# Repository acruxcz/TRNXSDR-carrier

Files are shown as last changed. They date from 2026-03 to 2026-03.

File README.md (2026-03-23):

# #TRNXSDR - Open RF Research Platform

**A modular baseboard designed for advanced Software Defined Radio (SDR) ecosystems.**

---

## 📝 Project Overview
The **TRNXSDR** is a hardware platform engineered to host and interconnect specialized SDR modules. It acts as the central processing hub, providing high-speed logic, memory bandwidth, and versatile connectivity for complex radio applications.

> [!IMPORTANT]
> The **TRNXSDR** is a **Baseboard Platform**. While it provides the processing power and RF routing, it requires external SDR modules connected via the expansion slots for full radio functionality.

## #TRNXSDR Baseboard

<p align="center">
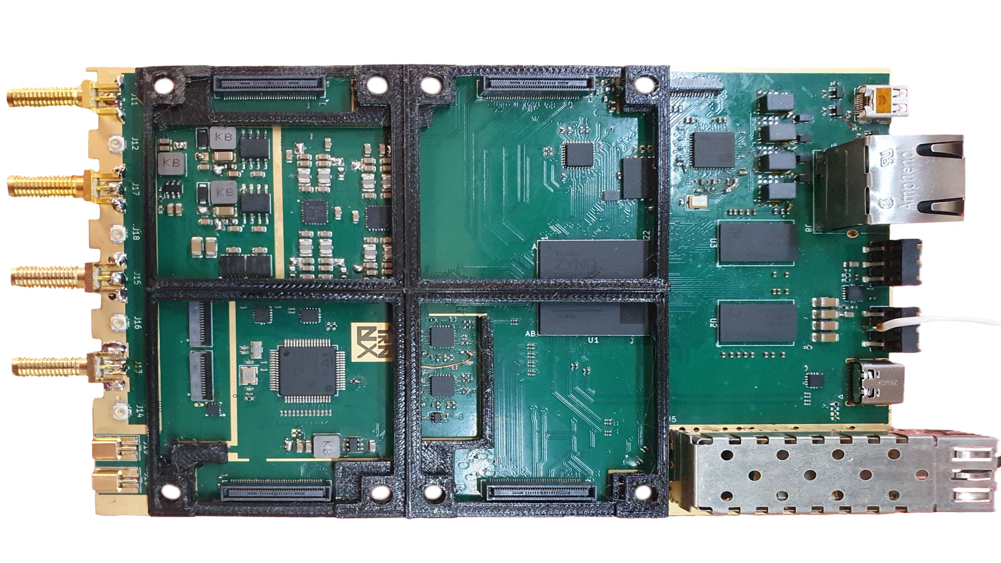
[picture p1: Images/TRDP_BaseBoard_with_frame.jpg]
TRNXSDR BaseBoard
  
</p>

---

## Key Technical Specifications

### ⚙️ Processing & Memory
*   **FPGA XC7Z015 Core**: High-speed logic for real-time Digital Signal Processing (DSP).
*   **1 GB DDR3 RAM @ 1066 MHz**: High-capacity memory for data buffering and complex waveform processing.
*   **80-pin Module Connectors**: High-density connectors ensuring reliable signal integrity between the baseboard and modules.

### 🌐 Connectivity & I/O
*   **1 Gbit Ethernet (Copper)**: Standard high-speed network integration.
*   **Optical Ethernet (SFP)**: Hardware ready for fiber-optic connection. Planned support for **1 Gbit / 2.5 Gbit+** throughput via GTX connection (up to **5 Gbit** for custom digital IF).
*   **USB-C**: Hardware support for **Power Delivery (PD)** to power the entire board via a single cable (9–20 V input). Firmware currently under development.
*   **4 SMA RF Connectors**: On-board SMA connectors for direct and stable antenna connections.

---

## 🛠 Modular Ecosystem & Scalability
The platform is designed to grow. The baseboard features a flexible slot system to accommodate various SDR modules.

| Slot Type | Quantity | Technical Capabilities |
| :--- | :---: | :--- |
| **Primary HS Slots** | **2** | **High-Speed Support**: 1x with 2L GTX (JESD204B support), both slots support LVDS. |
| **Primary LS Slots** | **2** | **Standard I/O**: Optimized for general-purpose SDR control and low-speed buses. |
| **Expansion Board** | **+6** | **Low-Speed Expansion**: Optimized for SPI, I2C, and LVDS control buses. |

---

## 💻 Software & Integration

### GNU Radio Support (Active Development)
**Core functionality is already verified!** We have developed a custom **OOT (Out-Of-Tree) Module**, enabling basic RX streaming between the hardware and GNU Radio.
*   *Current focus*: Stability improvements, feature expansion, and bug fixes.

Below, you can see a GNU Radio Companion (GRC) flowgraph demonstrating the implementation of the dedicated #TRNXSDR source block.

<p align="center">
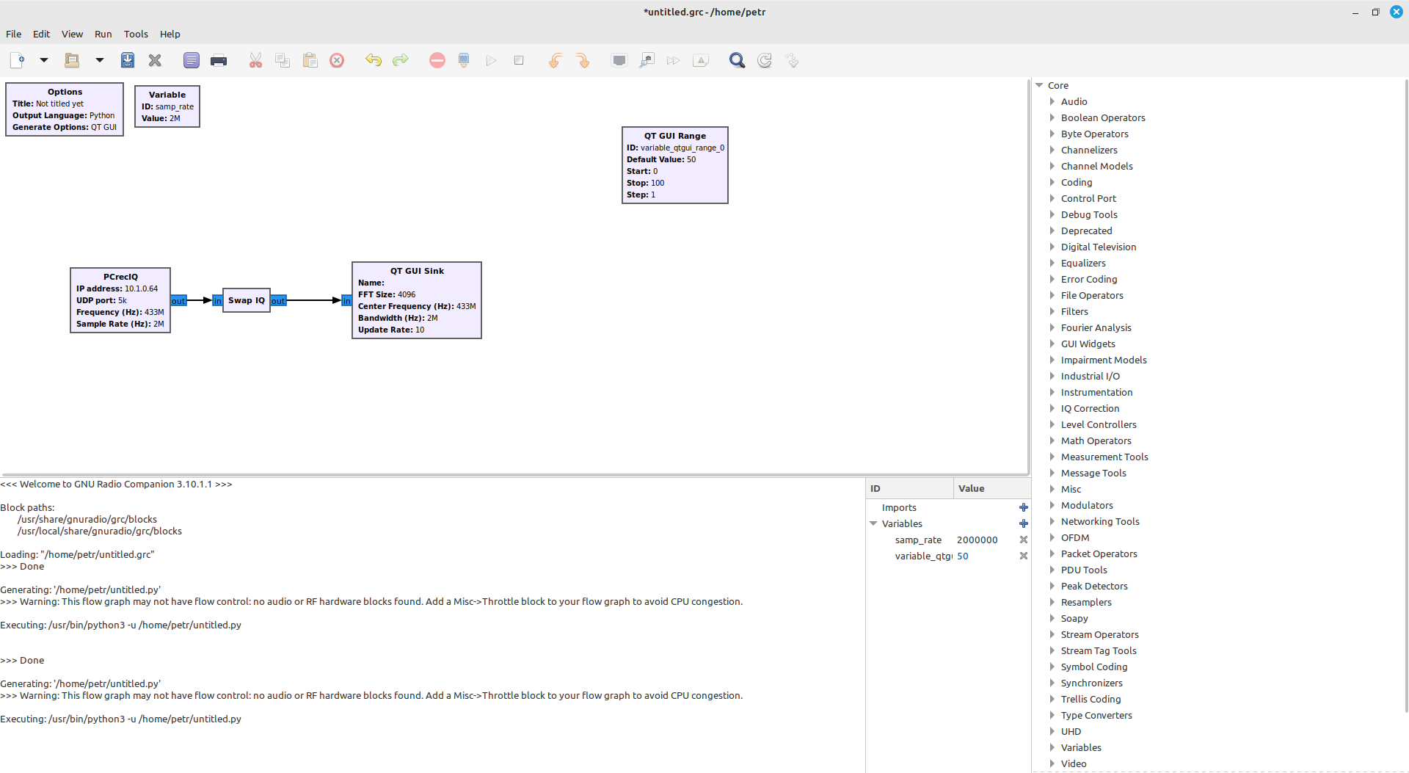
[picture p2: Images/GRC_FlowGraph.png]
GNU Radio flowgraph featuring the custom #TRNXSDR OOT module
  
</p>

### Signal Analysis & Verification
To verify the RF chain's integrity, we tested the SDR in the 433 MHz band. The following image shows the captured spectrum in GRC, displaying a clean signal peak and minimal noise floor.

<p align="center">
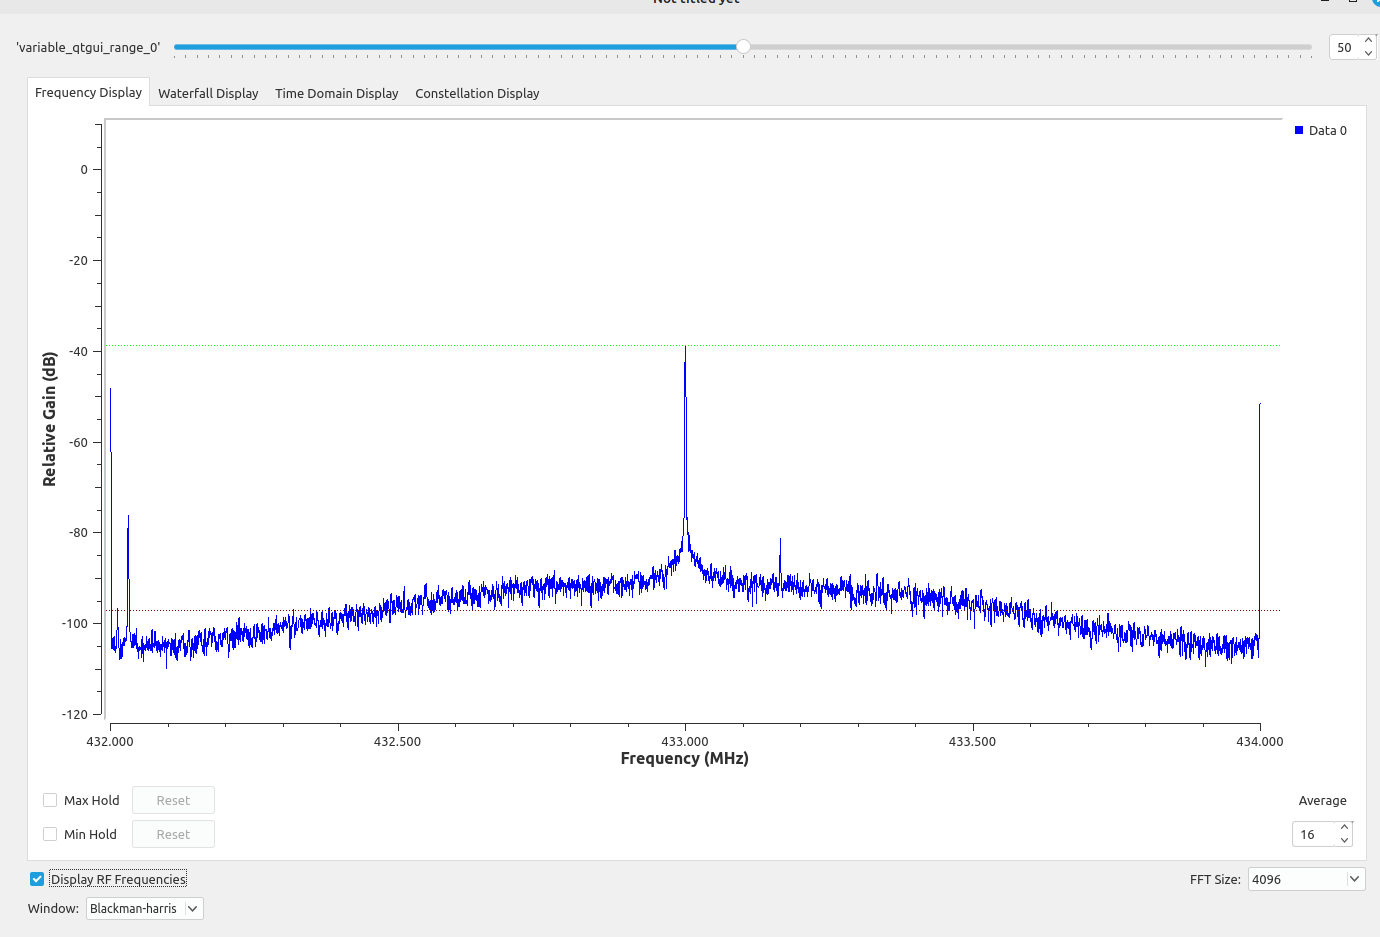
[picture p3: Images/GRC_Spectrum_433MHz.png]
Real-time spectrum analysis of a 433 MHz signal
  
</p>

Furthermore, we performed a dynamic frequency shift test. In the waterfall plot below, you can see a "snake" pattern created by manually sweeping the carrier frequency. The sweep was performed roughly within a ±500 kHz range around the 433 MHz center.

<p align="center">
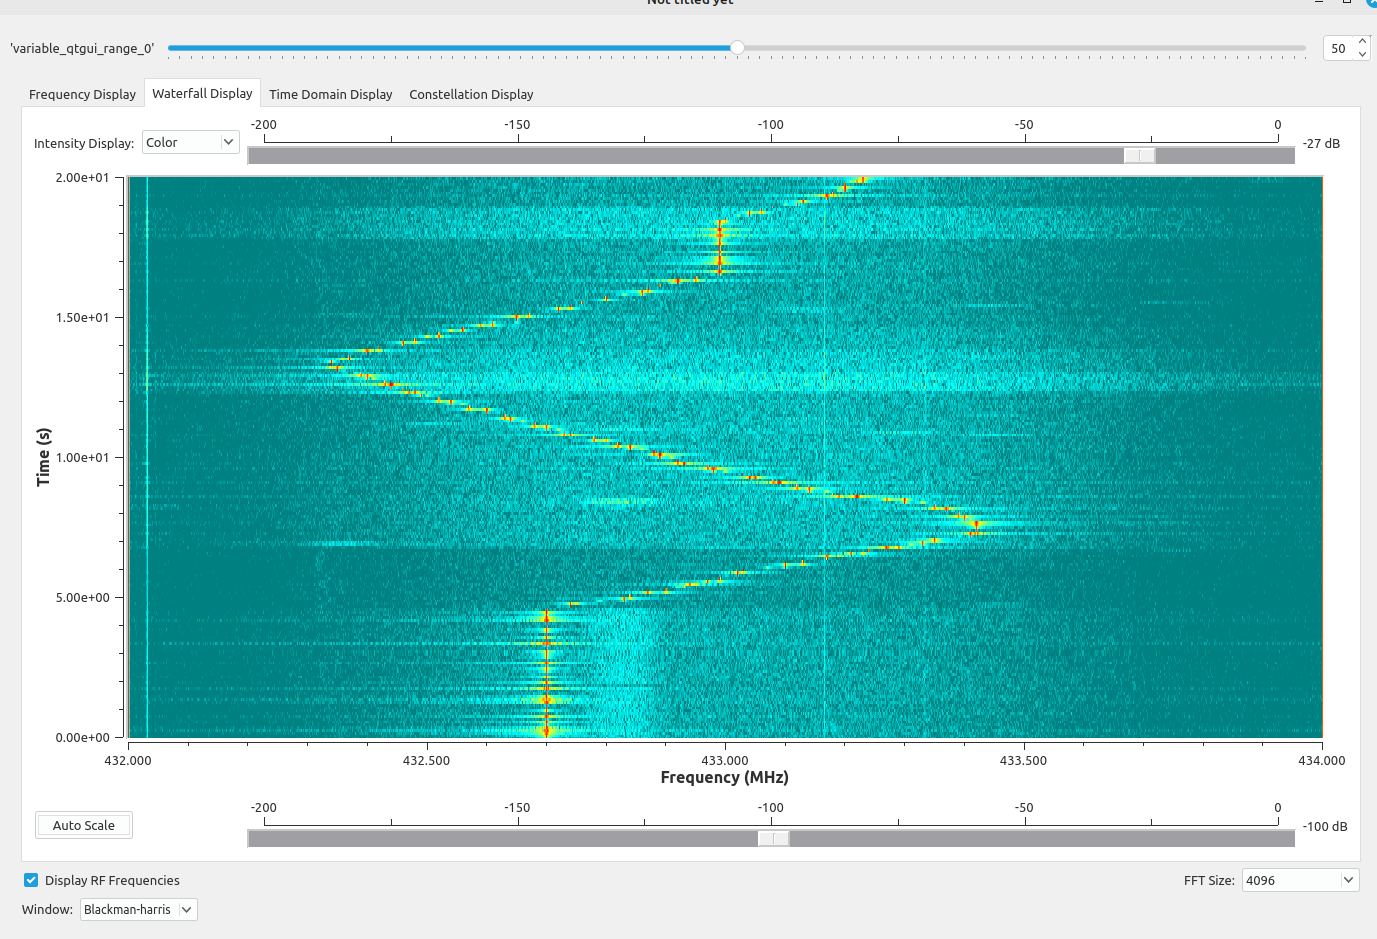
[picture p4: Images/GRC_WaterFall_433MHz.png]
Waterfall plot showing carrier frequency modulation (frequency sweep)
  
</p>

### Future Software Roadmap (Planned)
*   **SoapySDR Compatibility**: Integration of a SoapySDR driver to provide a vendor-neutral API for tools like **SDR++, SDRangel, GNU Radio and more**.
*   **OpenWiFi Project**: Investigating the possibility of hosting the OpenWiFi stack (IEEE 802.11 FPGA/Software) on #TRNXSDR hardware.

---

## #TRNXSDR with AT86RF215 SDR Module and RFFC5072 Mixer Module + RF Front-End (LNA, PA...) Module

<p align="center">
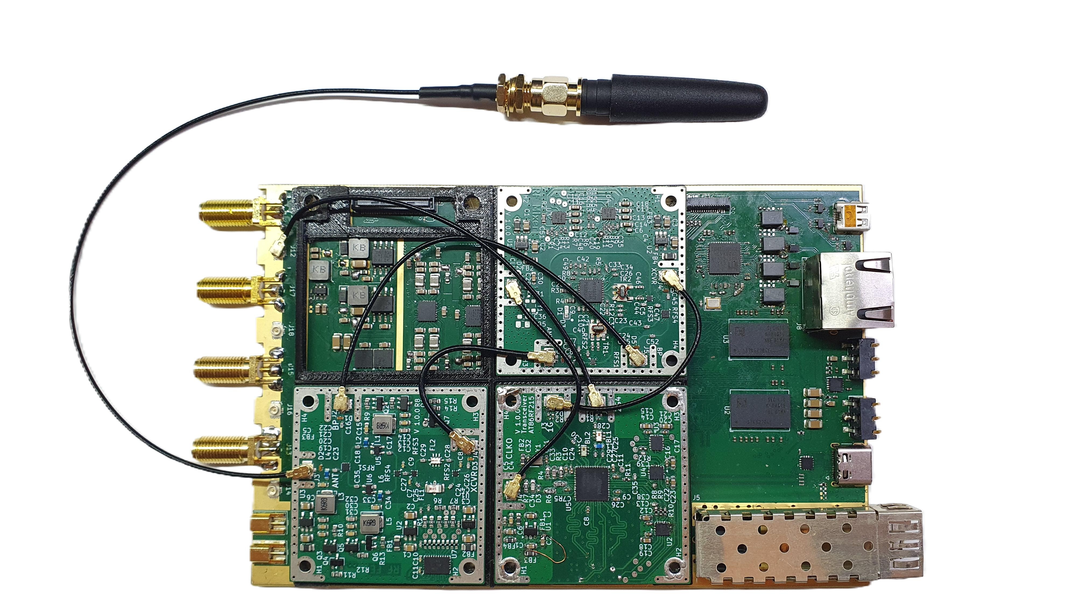
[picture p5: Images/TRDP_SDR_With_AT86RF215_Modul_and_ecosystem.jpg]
TRNXSDR Ecosystem
  
</p>

---

## 🟢 Future Hardware Roadmap
Expanding the #TRNXSDR ecosystem with high-end RF modules:
*   **Expansion Board**: A dedicated add-on board adding **6 additional low-speed slots** (Total of 10 modules).
*   **New SDR Modules**:
    *   **Lime Ecosystem**: Modules based on **LMS6002D** and **LMS7002M** (MIMO, wide frequency range).
    *   **Analog Devices Series**: High-performance transceivers based on **AD9361 / AD9363 / AD9364**.

---

## 🛠 Development Status

- [x] **Baseboard Hardware Design**: Completed (Rev 1.0) — *Functional, with known bugs being addressed.*
- [/] **Hardware Revision 2.0**: In progress (bug fixes and optimizations).
- [/] **GNU Radio OOT Module**: Functional — *Ongoing development and feature updates.*
- [/] **Optical Port**: Hardware ready, firmware development in progress.
- [/] **USB-C Power Delivery**: Hardware support implemented, firmware under active development.
- [ ] **SoapySDR & OpenWiFi**: Conceptual/Planned stage.

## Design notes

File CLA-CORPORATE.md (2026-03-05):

# Corporate Contributor License Agreement

**Project:** TRNXSDR  
**Maintainer:** Petr Pavlata, Tronex s.r.o. ("We", "Us", "Our")  
**Project URL:** https://github.com/acruxcz/TRNXSDR-carrier  
**Version:** 1.0  

---

## Purpose

This Corporate Contributor License Agreement ("Agreement") clarifies the
intellectual property rights granted by a Corporation and its designated
employees or contractors to this project.

This Agreement covers all Contributions made by individuals who are
authorized by the Corporation to contribute on its behalf. It supplements —
and does not replace — any Individual CLAs those individuals may have signed.

---

## Definitions

**"Corporation"** means the legal entity signing this Agreement ("You", "Your").

**"Authorized Contributor"** means any employee, contractor, or agent of the
Corporation who is authorized in writing (e.g. via the Authorized Contributors
list below or a separate authorization) to submit Contributions on behalf of
the Corporation.

**"Contribution"** means any original work of authorship — including hardware
design files, schematics, PCB layouts, BOMs, HDL/FPGA source, firmware,
software, and documentation — submitted to this project by an Authorized
Contributor on behalf of the Corporation.

**"Submit"** means any act of uploading, emailing, opening a pull request,
or otherwise delivering a Contribution to Us or the project repository.

---

## 1. Copyright License Grant

Subject to the terms of this Agreement, You hereby grant to Us a perpetual,
worldwide, non-exclusive, royalty-free, irrevocable license to:

- reproduce, prepare derivative works of, publicly display, publicly perform,
  sublicense, and distribute Your Contributions and derivative works thereof
- license Your Contributions under any license, including commercial and
  proprietary licenses

**Limitation:** As a condition of the above grant, We agree that any Material
incorporating Your Contribution will always be made available under the terms
of the open source license in effect for this project at the time of Your
Contribution (currently CERN-OHL-S v2). We may offer additional commercial
licenses, but We will not remove or revoke the open source license for any
Material containing Your Contribution.

---

## 2. Patent License Grant

You hereby grant to Us and to recipients of Material distributed by Us a
perpetual, worldwide, non-exclusive, royalty-free, irrevocable patent license
to make, have made, use, offer to sell, sell, import, and otherwise transfer
Your Contribution and Your Contribution in combination with the project Material.

This license applies only to patent claims licensable by You that are
necessarily infringed by Your Contribution alone or in combination with the
project Material.

**Defensive termination:** If the Corporation or any entity it controls
institutes patent litigation (including a cross-claim or counterclaim)
alleging that any Contribution constitutes patent infringement, any patent
licenses granted under this Agreement to that entity terminate as of the
date such litigation is filed.

---

## 3. Corporation's Representations

The Corporation represents and warrants that:

1. It is legally entitled to grant the above licenses.
2. It has the authority to authorize the individuals listed as Authorized
   Contributors to submit Contributions on its behalf.
3. Each Contribution submitted by an Authorized Contributor is either an
   original creation of that individual or the Corporation has the right
   to submit it under this Agreement.
4. The Contributions do not, to the best of the Corporation's knowledge,
   infringe any third-party patents, copyrights, trademarks, or other
   intellectual property rights.
5. The Corporation will disclose any known third-party licenses or
   restrictions that apply to any part of the Contributions.

---

## 4. Authorized Contributors

The Corporation designates the following individuals as Authorized Contributors
under this Agreement. The Corporation may update this list by written notice
to Us.

| Name | GitHub Username | Email | Date Added |
|---|---|---|---|
| | | | |
| | | | |
| | | | |

*Attach additional pages if needed.*

---

## 5. Responsibility for Authorized Contributors

The Corporation accepts responsibility for ensuring that each Authorized
Contributor is aware of and complies with this Agreement. The Corporation
remains liable for Contributions made by its Authorized Contributors.

---

## 6. No Support Obligation

The Corporation is not expected to provide support for Contributions unless
it chooses to do so.

---

## 7. No Warranty

Contributions are provided "as is", without warranty of any kind, express
or implied, including but not limited to warranties of merchantability,
fitness for a particular purpose, or non-infringement.

---

## 8. Governing Law

This Agreement shall be governed by the laws of Czech Republic,
without regard to its conflict of law provisions.
Any disputes shall be subject to the exclusive jurisdiction of the courts
of Czech Republic.

---

## Signing

This Agreement must be signed by a person with authority to bind the
Corporation (e.g. director, legal counsel, or authorized officer).

---

**Legal name of Corporation:** ___________________________________

**Registered address:** ___________________________________

**Name of signatory:** ___________________________________

**Title of signatory:** ___________________________________

**Email address:** ___________________________________

**Date:** ___________________________________

**Signature:** ___________________________________

---

*Submit signed Corporate CLA by email to info@tronex.cz.*  
*After acceptance, Authorized Contributors may begin submitting Contributions.*  
*To add or remove Authorized Contributors, contact info@tronex.cz.*

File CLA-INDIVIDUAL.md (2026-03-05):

# Individual Contributor License Agreement

**Project:** TRNXSDR  
**Maintainer:** Petr Pavlata, Tronex s.r.o. ("We", "Us", "Our")  
**Project URL:** https://github.com/acruxcz/TRNXSDR-carrier  
**Version:** 1.0  

---

## Purpose

This Individual Contributor License Agreement ("Agreement") clarifies the
intellectual property rights granted by Contributors to this project.
It enables Us to maintain a dual licensing model while ensuring that all
contributions remain available to the open source community.

This Agreement does **not** transfer copyright ownership. You retain full
copyright in Your Contributions.

---

## Definitions

**"You"** means the individual signing this Agreement.

**"Contribution"** means any original work of authorship — including hardware
design files, schematics, PCB layouts, BOMs, HDL/FPGA source, firmware,
software, and documentation — that You submit to this project, in any form.

**"Submit"** means any act of uploading, emailing, opening a pull request,
or otherwise delivering a Contribution to Us or the project repository.

---

## 1. Copyright License Grant

Subject to the terms of this Agreement, You hereby grant to Us a perpetual,
worldwide, non-exclusive, royalty-free, irrevocable license to:

- reproduce, prepare derivative works of, publicly display, publicly perform,
  sublicense, and distribute Your Contributions and derivative works thereof
- license Your Contributions under any license, including commercial and
  proprietary licenses

**Limitation:** As a condition of the above grant, We agree that any Material
incorporating Your Contribution will always be made available under the
terms of the open source license in effect for this project at the time of
Your Contribution (currently CERN-OHL-S v2). We may offer additional
commercial licenses, but We will not remove or revoke the open source
license for any Material containing Your Contribution.

---

## 2. Patent License Grant

You hereby grant to Us and to recipients of Material distributed by Us a
perpetual, worldwide, non-exclusive, royalty-free, irrevocable patent license
to make, have made, use, offer to sell, sell, import, and otherwise transfer
Your Contribution and Your Contribution in combination with the project Material.

This license applies only to patent claims licensable by You that are
necessarily infringed by Your Contribution alone or in combination with the
project Material.

**Defensive termination:** If any entity institutes patent litigation against
You or Us alleging that Your Contribution constitutes patent infringement,
any patent license granted under this Agreement to that entity terminates
as of the date such litigation is filed.

---

## 3. Your Representations

You represent and warrant that:

1. You are legally entitled to grant the above licenses.
2. Each Contribution is Your original creation, or You have the right to
   submit it under this Agreement.
3. If Your employer has rights to intellectual property You create, You have
   obtained permission to make Contributions on behalf of that employer, or
   Your employer has waived such rights for Your Contributions to this project.
4. Your Contributions do not, to the best of Your knowledge, infringe any
   third-party patents, copyrights, trademarks, or other intellectual
   property rights.
5. You will disclose any third-party licenses or restrictions You are aware of
   that apply to any part of Your Contributions.

---

## 4. Contributions on Behalf of Others

If Your Contribution includes work created by third parties, You must:
- identify such third-party work clearly in the Contribution
- confirm that the third party has agreed to terms consistent with this Agreement

---

## 5. No Support Obligation

You are not expected to provide support for Your Contributions unless You
choose to do so. Support may be provided free of charge, for a fee, or
not at all — at Your discretion.

---

## 6. No Warranty

Your Contributions are provided "as is", without warranty of any kind,
express or implied, including but not limited to warranties of merchantability,
fitness for a particular purpose, or non-infringement.

---

## 7. Governing Law

This Agreement shall be governed by the laws of Czech Republic,
without regard to its conflict of law provisions.

---

## Signing

By submitting a Contribution to this project (e.g. via pull request),
You confirm that You have read, understood, and agree to the terms of
this Agreement.

For formal written confirmation, please submit the following:

---

**Full legal name:** ___________________________________

**GitHub username:** ___________________________________

**Email address:** ___________________________________

**Date:** ___________________________________

**Signature:** ___________________________________

---

*Submit signed CLA by email to info@tronex.cz or via the CLA bot on GitHub.*
*See [CLA assistant setup](https://cla-assistant.io/) for automated signing.*

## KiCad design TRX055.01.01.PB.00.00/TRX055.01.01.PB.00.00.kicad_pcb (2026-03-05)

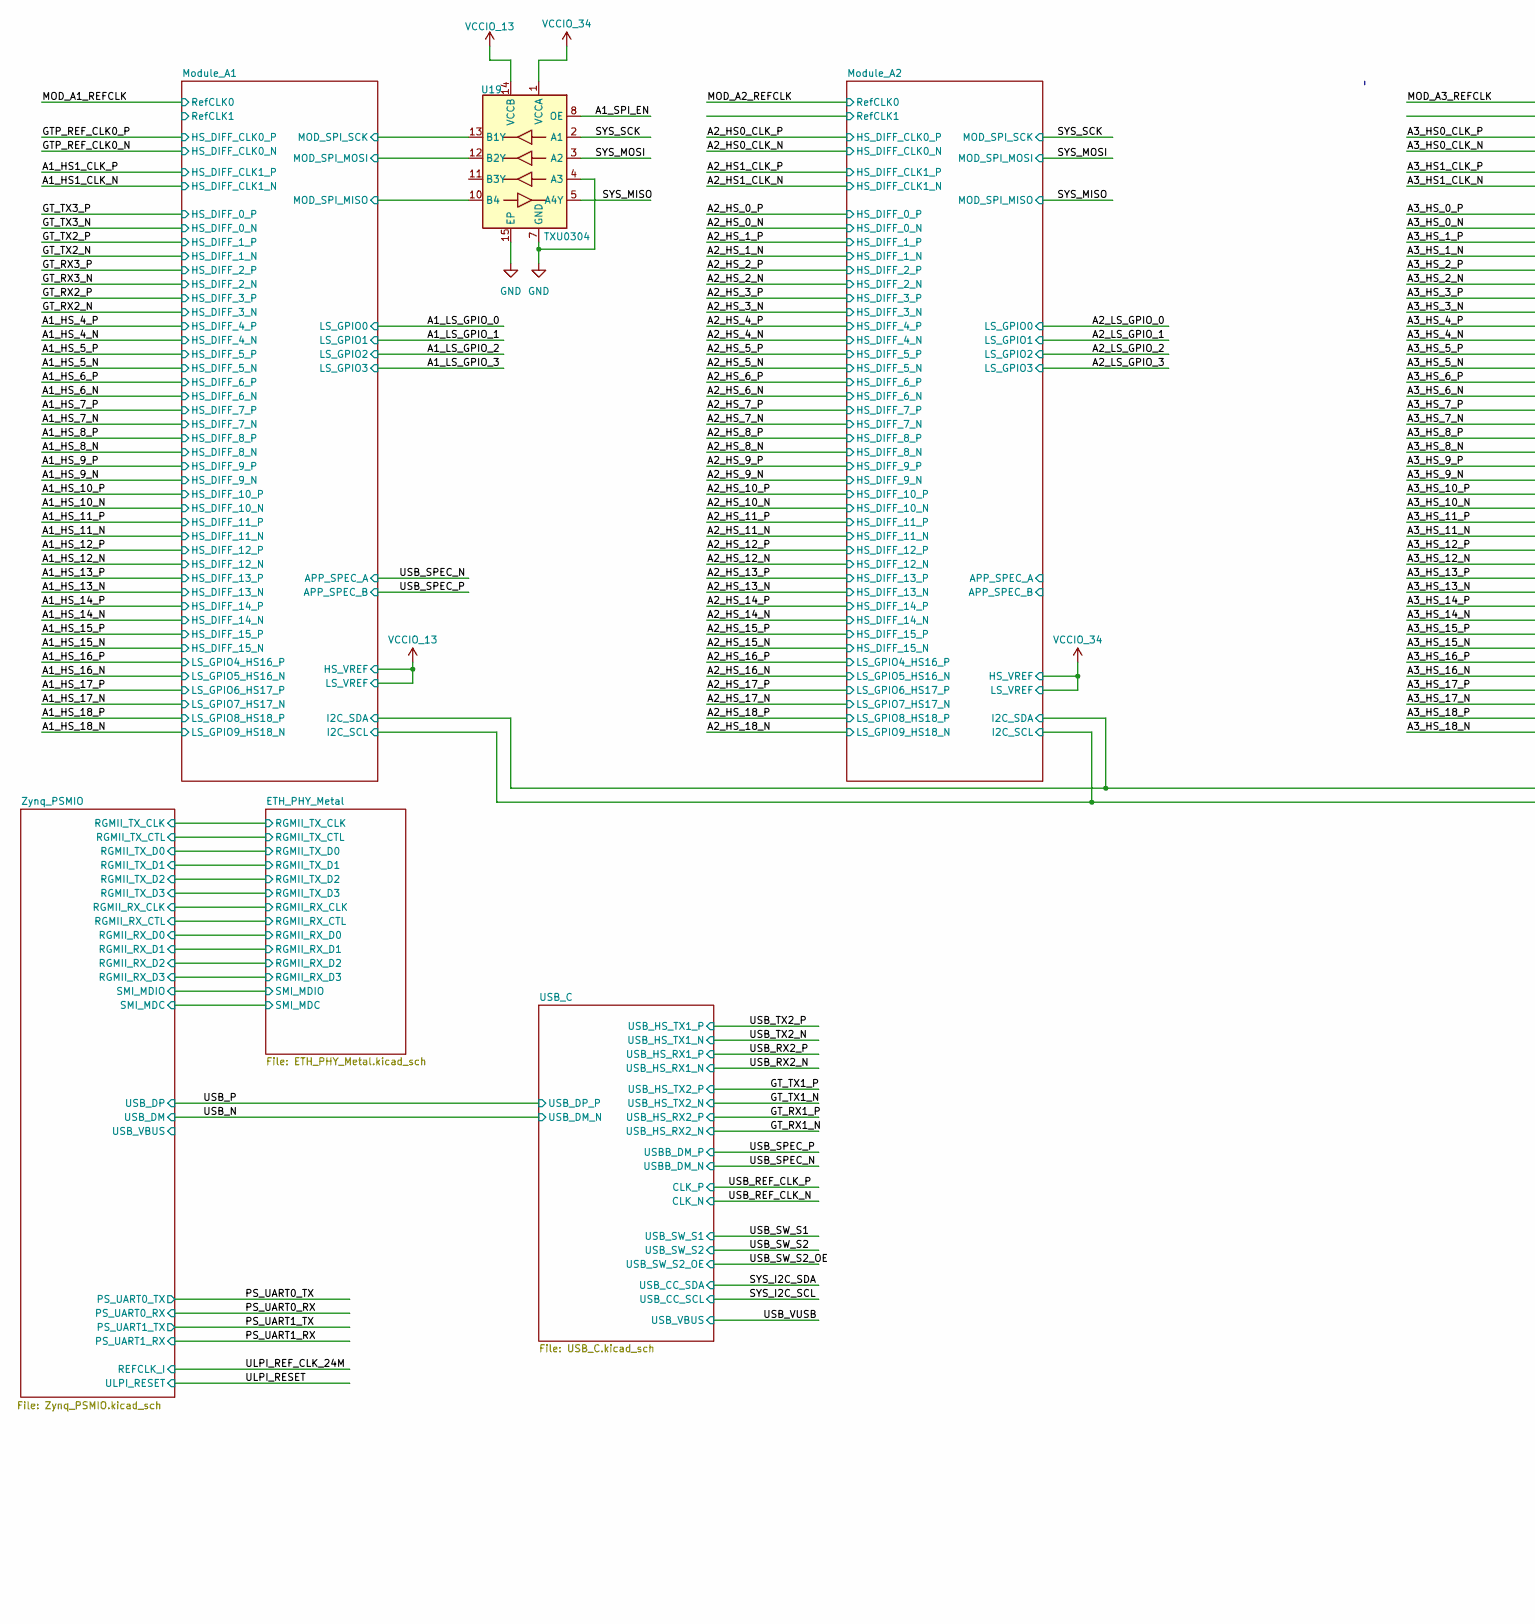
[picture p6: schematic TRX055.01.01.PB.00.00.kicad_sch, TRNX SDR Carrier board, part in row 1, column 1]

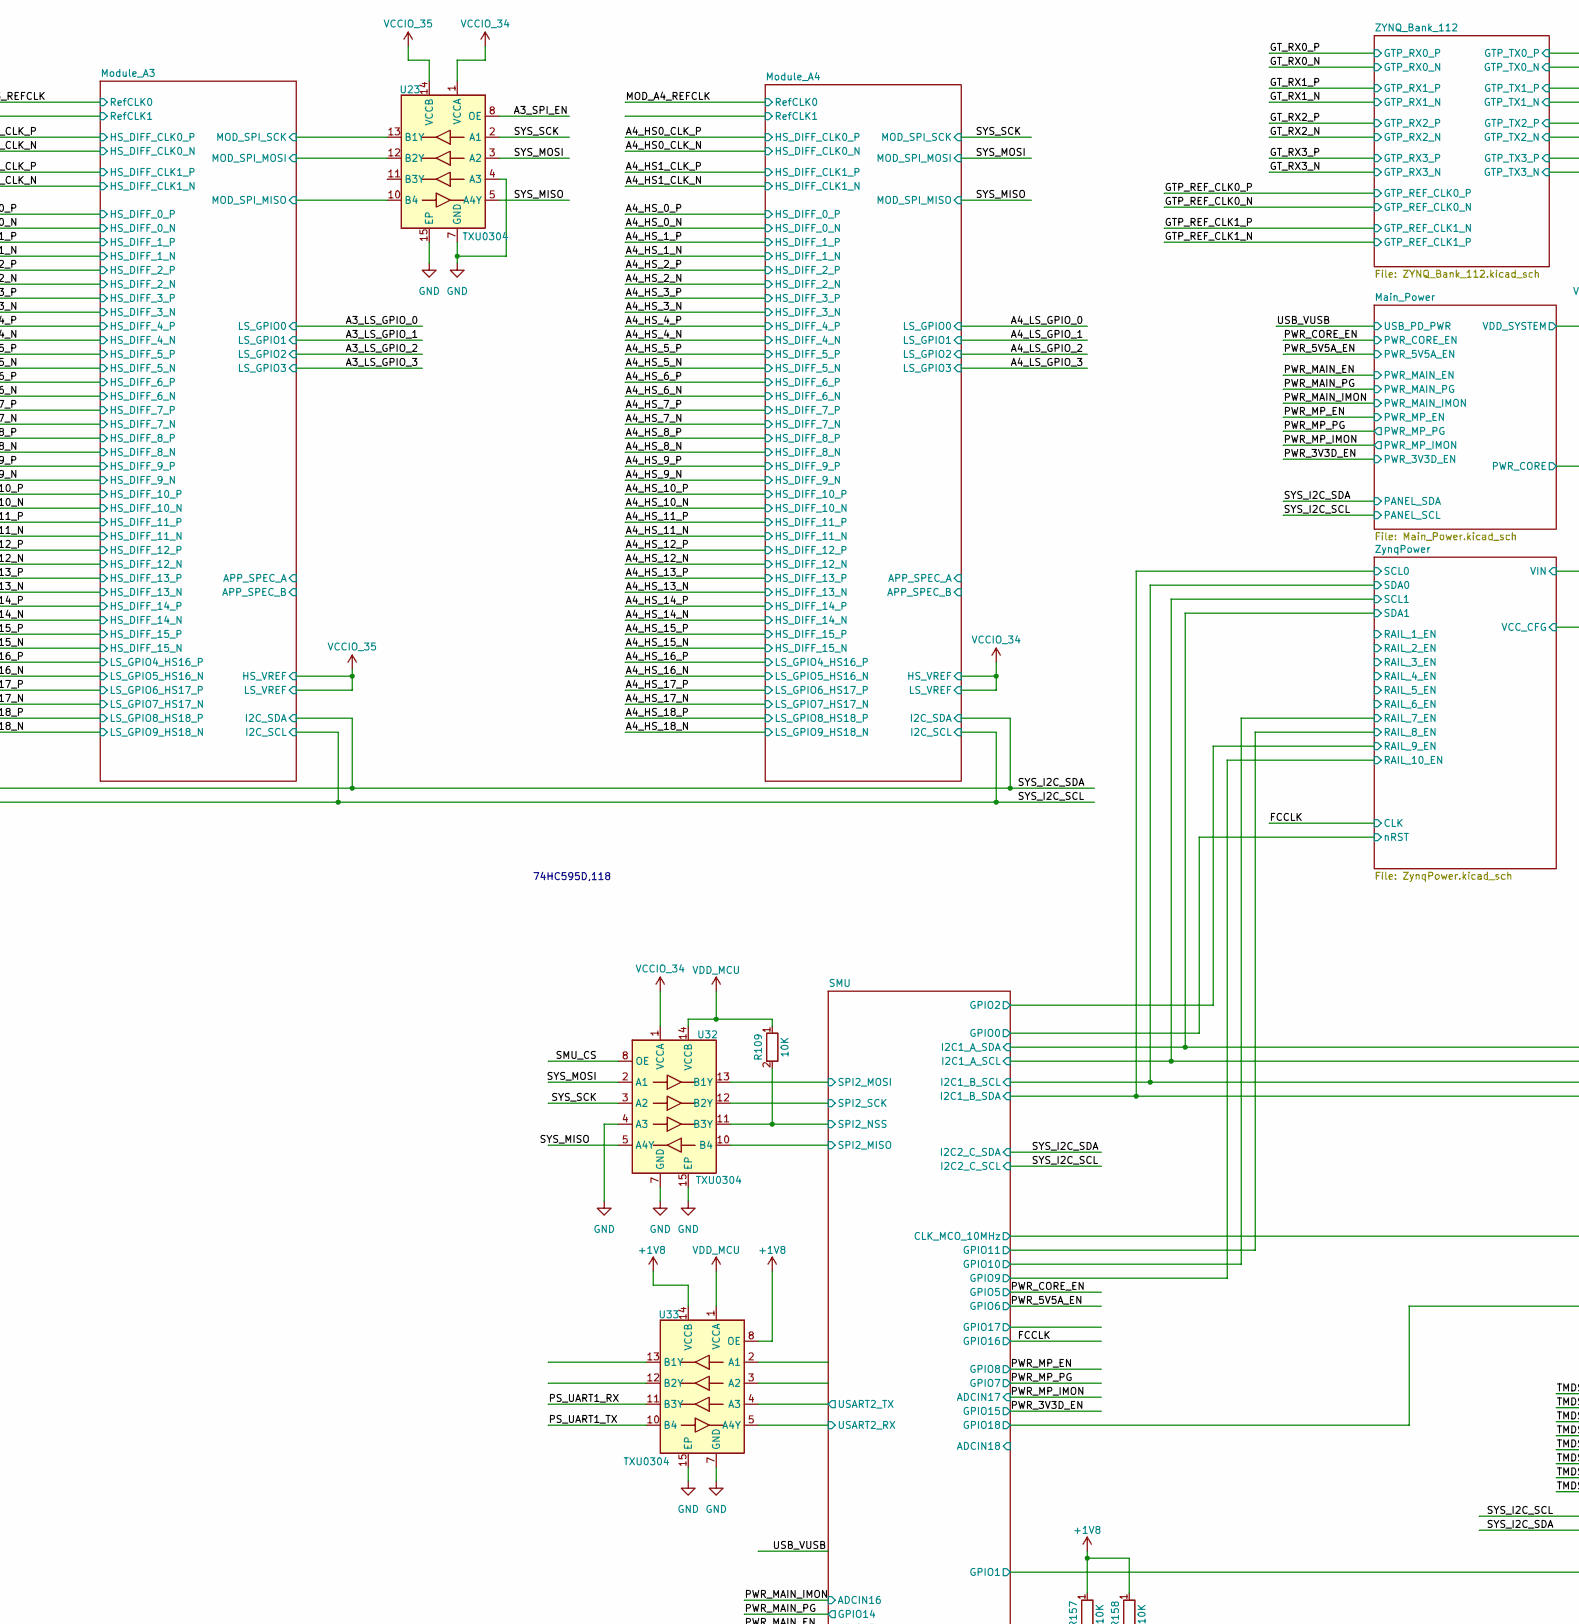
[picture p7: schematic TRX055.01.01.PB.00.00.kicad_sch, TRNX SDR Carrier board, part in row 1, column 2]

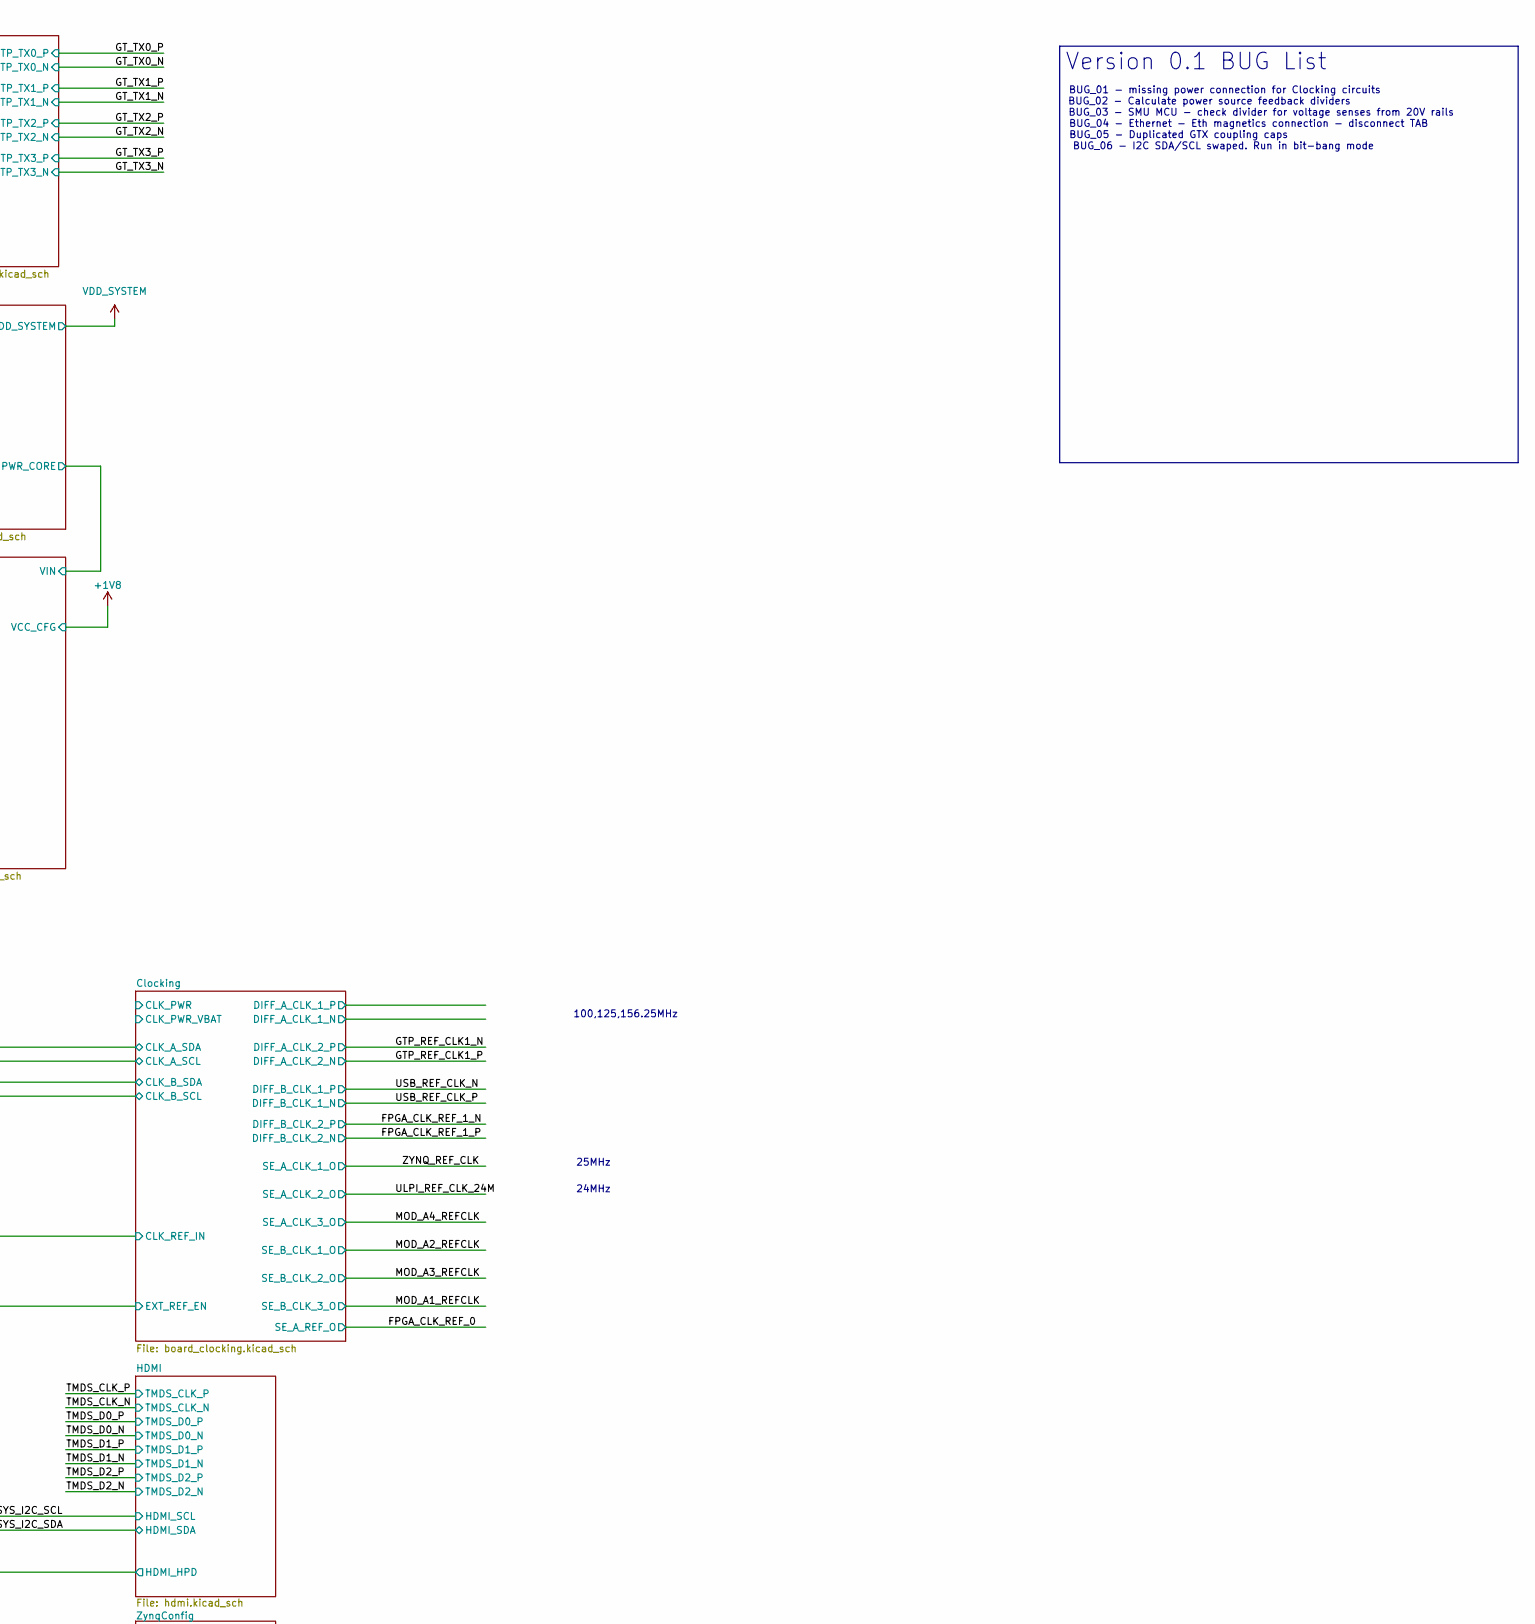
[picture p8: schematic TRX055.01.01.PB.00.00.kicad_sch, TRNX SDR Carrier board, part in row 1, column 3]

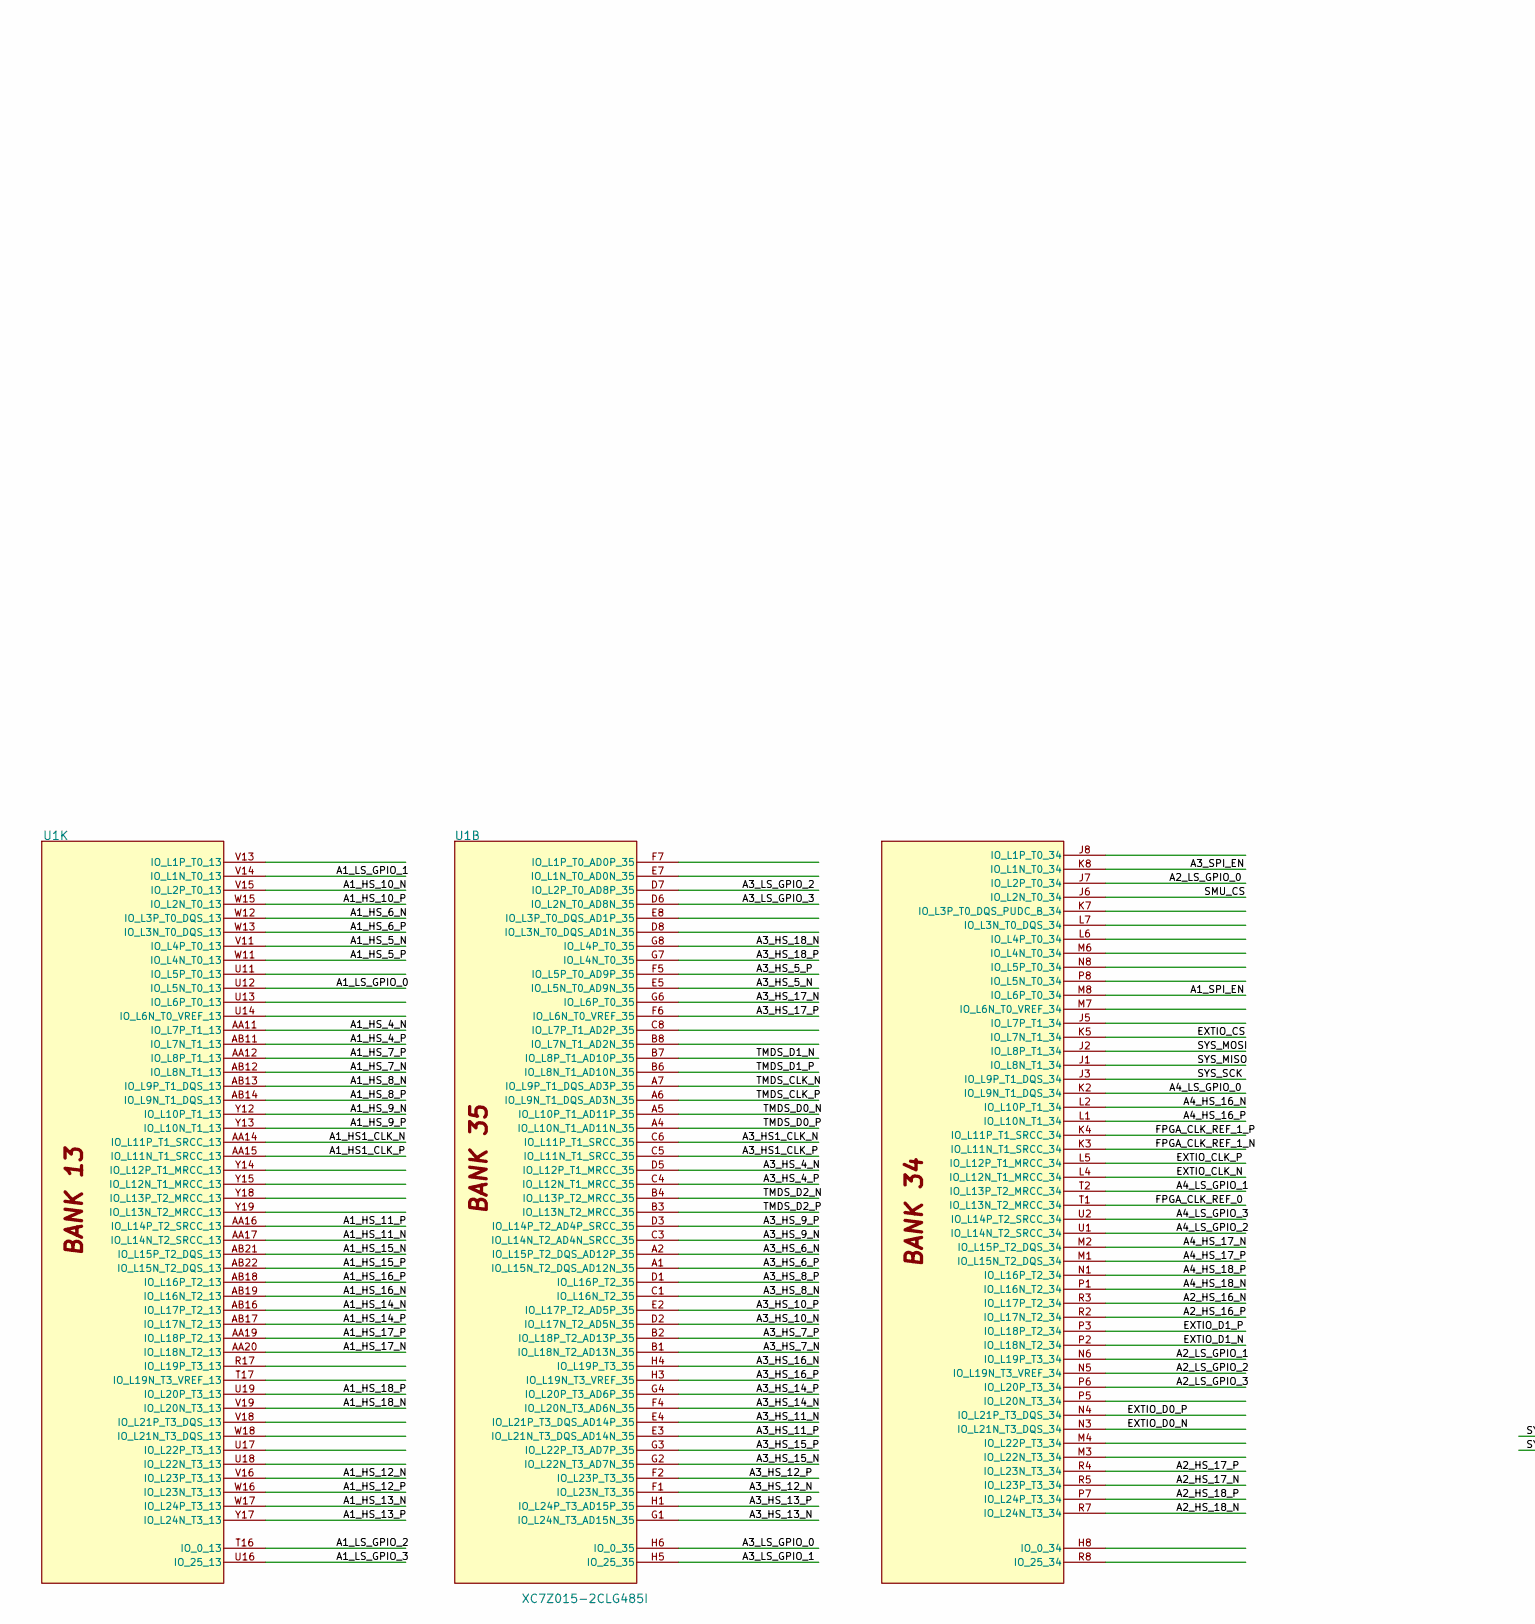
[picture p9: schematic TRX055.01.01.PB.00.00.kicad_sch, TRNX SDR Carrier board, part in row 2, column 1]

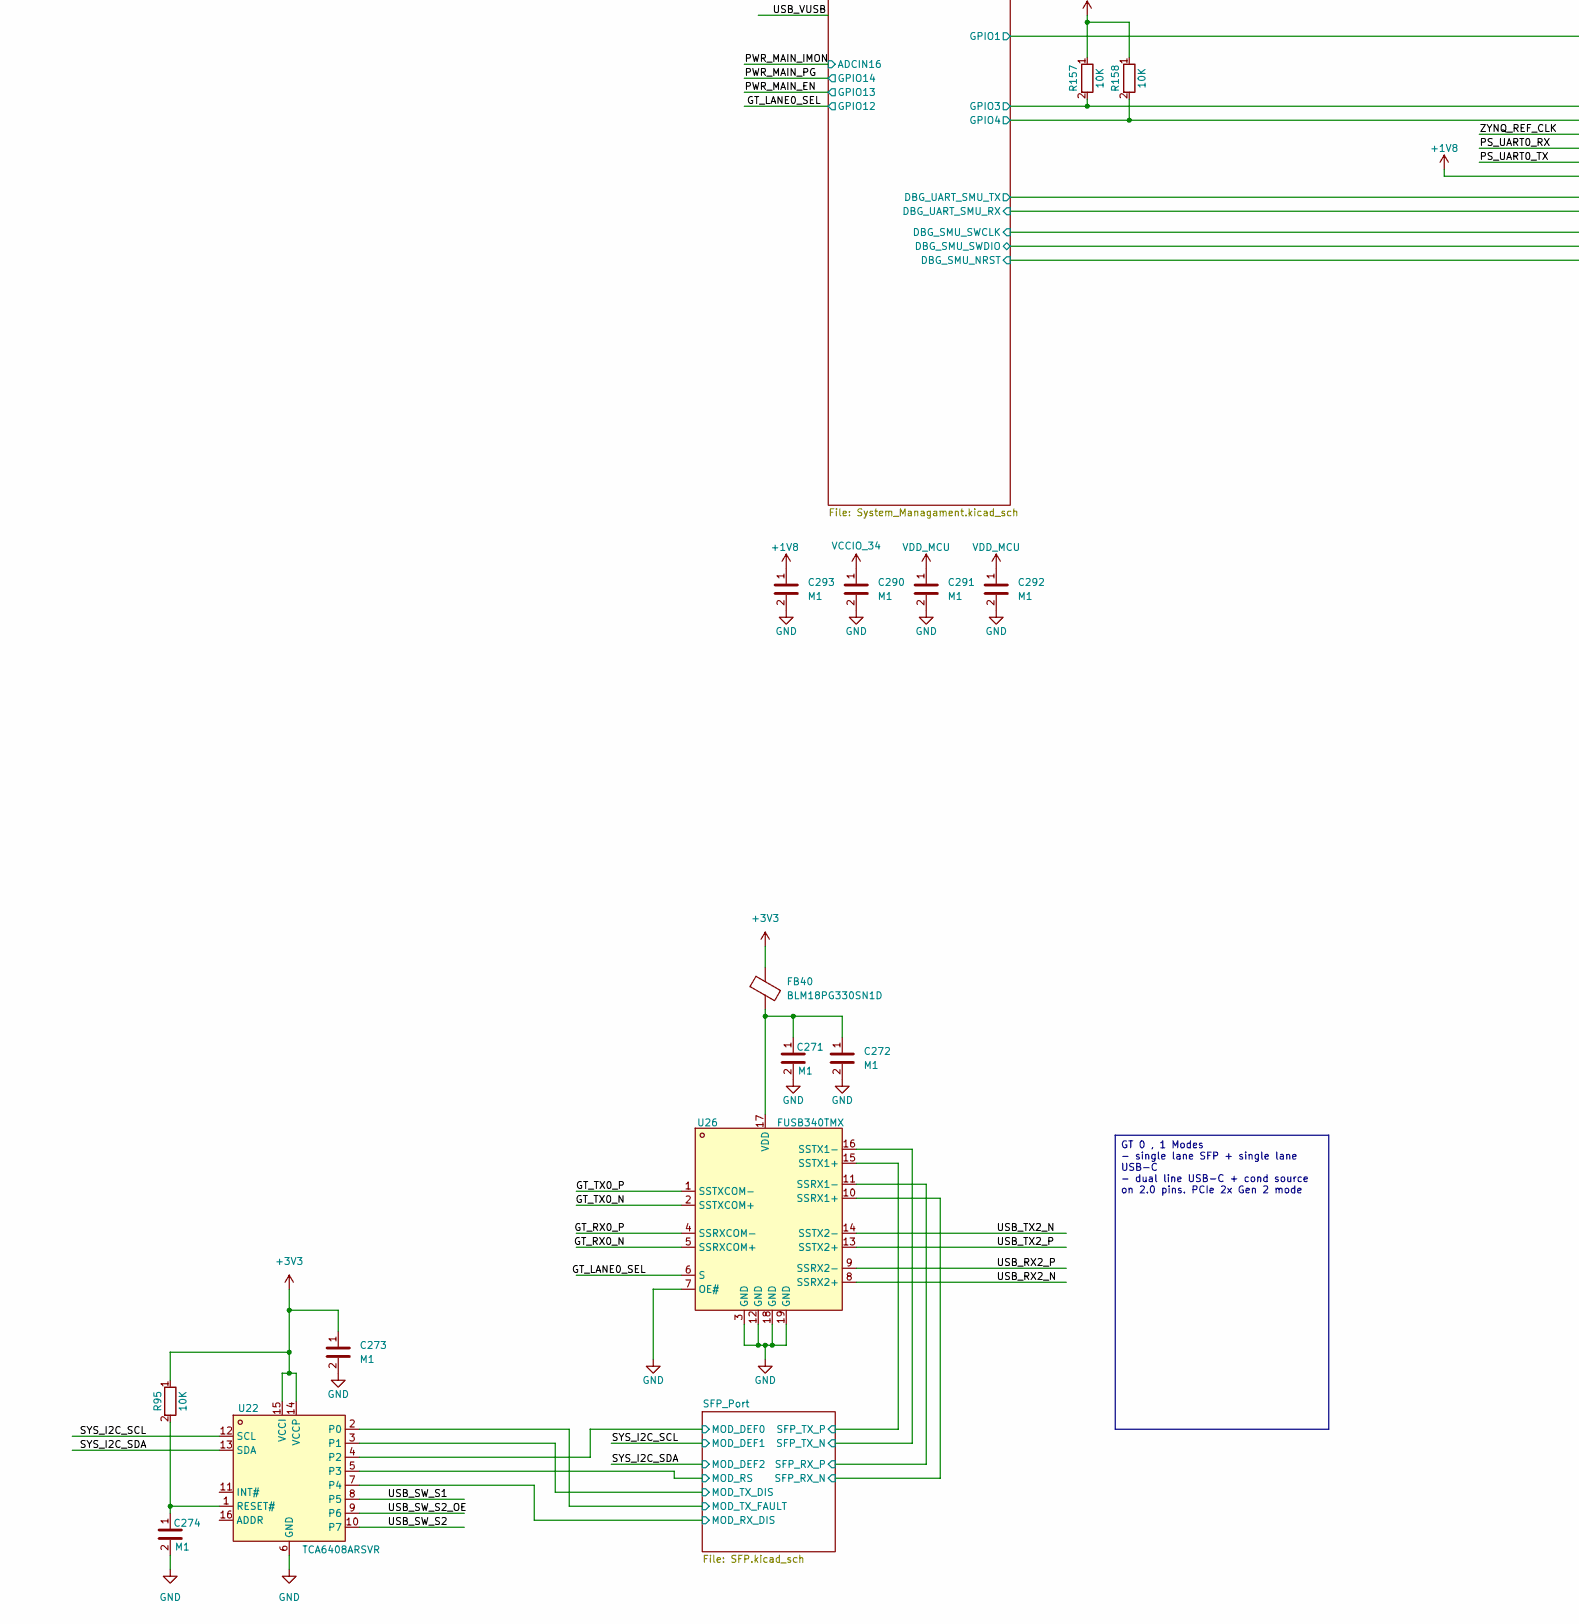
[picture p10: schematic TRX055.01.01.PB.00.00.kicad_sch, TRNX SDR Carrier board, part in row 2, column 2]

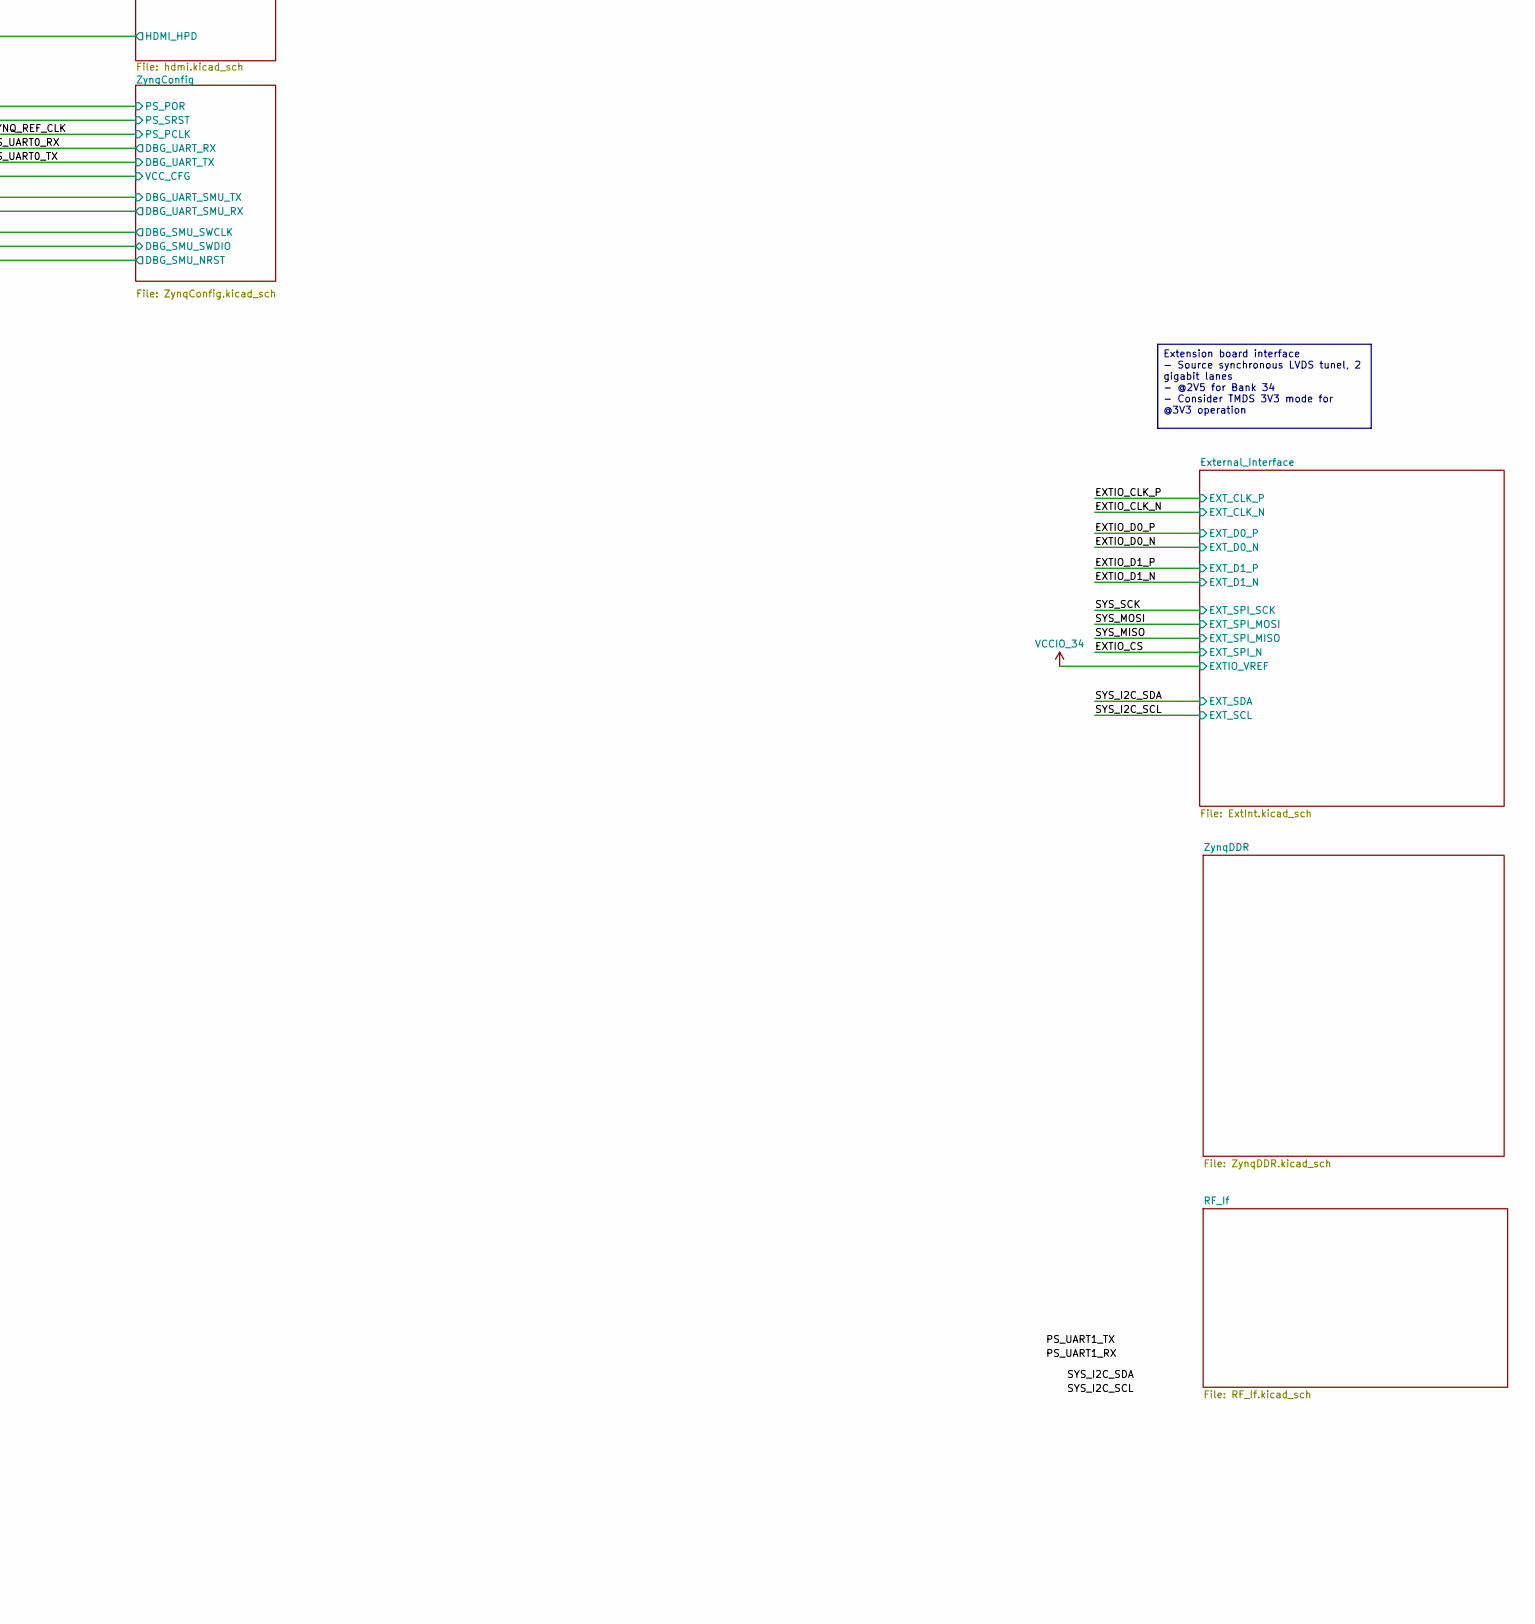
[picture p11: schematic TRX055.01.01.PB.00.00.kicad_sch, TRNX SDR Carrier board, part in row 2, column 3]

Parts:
C271, C272, C273, C274, C290, C291, C292, C293: M1; C_0201_0603Metric; Voltage 100V; JLC C49062
FB40: BLM18PG330SN1D; L_0603_1608Metric; JLCPCB Part # C88984
R95, R109, R157, R158: 10K; R_0402_1005Metric; Tolerance =< 5%; JLCPCB Part # C25744
U1: XC7Z015-2CLG485I; CLG485XC7Z012S&slash_XC7Z015_AMD; JLCPCB Part # C1522056
U19, U23, U32, U33: TXU0304; DHVQFN-14-1EP_2.5x3mm_P0.5mm_EP1x1.5mm; Mfr part TXU0304QWBQARQ1; JLCPCB Part # C5217873
U22: TCA6408ARSVR; UQFN-16_L2.6-W1.8-P0.40-BL; Manufacturer Part TCA6408ARSVR; LCSC Part Name TCA6408A具有中断输出、复位和配置寄存器的低电压8位I2C和SMBuSI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
U26: FUSB340TMX; TMLP-18_L2.8-W2.0-P0.40-BL-EP; Manufacturer Part FUSB340TMX; LCSC Part Name USB 3.1 SuperSpeed 10 Gbps 开关

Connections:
+1V8: C293.1, R157.1, R158.1, U33.8 (OE), U33.14 (VCCB); also elsewhere on the board
+3V3: C273.1, FB40.2, R95.1, U22.14 (VCCP), U22.15 (VCCI); also elsewhere on the board
/A1_HS1_CLK_N: U1.AA14 (IO_L11P_T1_SRCC_13); also elsewhere on the board
/A1_HS1_CLK_P: U1.AA15 (IO_L11N_T1_SRCC_13); also elsewhere on the board
/A1_HS_4_N: U1.AA11 (IO_L7P_T1_13); also elsewhere on the board
/A1_HS_4_P: U1.AB11 (IO_L7N_T1_13); also elsewhere on the board
/A1_HS_5_N: U1.V11 (IO_L4P_T0_13); also elsewhere on the board
/A1_HS_5_P: U1.W11 (IO_L4N_T0_13); also elsewhere on the board
/A1_HS_6_N: U1.W12 (IO_L3P_T0_DQS_13); also elsewhere on the board
/A1_HS_6_P: U1.W13 (IO_L3N_T0_DQS_13); also elsewhere on the board
/A1_HS_7_N: U1.AB12 (IO_L8N_T1_13); also elsewhere on the board
/A1_HS_7_P: U1.AA12 (IO_L8P_T1_13); also elsewhere on the board
/A1_HS_8_N: U1.AB13 (IO_L9P_T1_DQS_13); also elsewhere on the board
/A1_HS_8_P: U1.AB14 (IO_L9N_T1_DQS_13); also elsewhere on the board
/A1_HS_9_N: U1.Y12 (IO_L10P_T1_13); also elsewhere on the board
/A1_HS_9_P: U1.Y13 (IO_L10N_T1_13); also elsewhere on the board
/A1_HS_10_N: U1.V15 (IO_L2P_T0_13); also elsewhere on the board
/A1_HS_10_P: U1.W15 (IO_L2N_T0_13); also elsewhere on the board
/A1_HS_11_N: U1.AA17 (IO_L14N_T2_SRCC_13); also elsewhere on the board
/A1_HS_11_P: U1.AA16 (IO_L14P_T2_SRCC_13); also elsewhere on the board
/A1_HS_12_N: U1.V16 (IO_L23P_T3_13); also elsewhere on the board
/A1_HS_12_P: U1.W16 (IO_L23N_T3_13); also elsewhere on the board
/A1_HS_13_N: U1.W17 (IO_L24P_T3_13); also elsewhere on the board
/A1_HS_13_P: U1.Y17 (IO_L24N_T3_13); also elsewhere on the board
/A1_HS_14_N: U1.AB16 (IO_L17P_T2_13); also elsewhere on the board
/A1_HS_14_P: U1.AB17 (IO_L17N_T2_13); also elsewhere on the board
/A1_HS_15_N: U1.AB21 (IO_L15P_T2_DQS_13); also elsewhere on the board
/A1_HS_15_P: U1.AB22 (IO_L15N_T2_DQS_13); also elsewhere on the board
/A1_HS_16_N: U1.AB19 (IO_L16N_T2_13); also elsewhere on the board
/A1_HS_16_P: U1.AB18 (IO_L16P_T2_13); also elsewhere on the board
/A1_HS_17_N: U1.AA20 (IO_L18N_T2_13); also elsewhere on the board
/A1_HS_17_P: U1.AA19 (IO_L18P_T2_13); also elsewhere on the board
/A1_HS_18_N: U1.V19 (IO_L20N_T3_13); also elsewhere on the board
/A1_HS_18_P: U1.U19 (IO_L20P_T3_13); also elsewhere on the board
/A1_LS_GPIO_0: U1.U12 (IO_L5N_T0_13); also elsewhere on the board
/A1_LS_GPIO_1: U1.V14 (IO_L1N_T0_13); also elsewhere on the board
/A1_LS_GPIO_2: U1.T16 (IO_0_13); also elsewhere on the board
/A1_LS_GPIO_3: U1.U16 (IO_25_13); also elsewhere on the board
/A1_SPI_EN: U1.M8 (IO_L6P_T0_34), U19.8 (OE)
/A2_HS_16_N: U1.R3 (IO_L17P_T2_34); also elsewhere on the board
/A2_HS_16_P: U1.R2 (IO_L17N_T2_34); also elsewhere on the board
/A2_HS_17_N: U1.R5 (IO_L23P_T3_34); also elsewhere on the board
/A2_HS_17_P: U1.R4 (IO_L23N_T3_34); also elsewhere on the board
/A2_HS_18_N: U1.R7 (IO_L24N_T3_34); also elsewhere on the board
/A2_HS_18_P: U1.P7 (IO_L24P_T3_34); also elsewhere on the board
/A2_LS_GPIO_0: U1.J7 (IO_L2P_T0_34); also elsewhere on the board
/A2_LS_GPIO_1: U1.N6 (IO_L19P_T3_34); also elsewhere on the board
/A2_LS_GPIO_2: U1.N5 (IO_L19N_T3_VREF_34); also elsewhere on the board
/A2_LS_GPIO_3: U1.P6 (IO_L20P_T3_34); also elsewhere on the board
/A3_HS1_CLK_N: U1.C6 (IO_L11P_T1_SRCC_35); also elsewhere on the board
/A3_HS1_CLK_P: U1.C5 (IO_L11N_T1_SRCC_35); also elsewhere on the board
/A3_HS_4_N: U1.D5 (IO_L12P_T1_MRCC_35); also elsewhere on the board
/A3_HS_4_P: U1.C4 (IO_L12N_T1_MRCC_35); also elsewhere on the board
/A3_HS_5_N: U1.E5 (IO_L5N_T0_AD9N_35); also elsewhere on the board
/A3_HS_5_P: U1.F5 (IO_L5P_T0_AD9P_35); also elsewhere on the board
/A3_HS_6_N: U1.A2 (IO_L15P_T2_DQS_AD12P_35); also elsewhere on the board
/A3_HS_6_P: U1.A1 (IO_L15N_T2_DQS_AD12N_35); also elsewhere on the board
/A3_HS_7_N: U1.B1 (IO_L18N_T2_AD13N_35); also elsewhere on the board
/A3_HS_7_P: U1.B2 (IO_L18P_T2_AD13P_35); also elsewhere on the board
/A3_HS_8_N: U1.C1 (IO_L16N_T2_35); also elsewhere on the board
/A3_HS_8_P: U1.D1 (IO_L16P_T2_35); also elsewhere on the board
/A3_HS_9_N: U1.C3 (IO_L14N_T2_AD4N_SRCC_35); also elsewhere on the board
/A3_HS_9_P: U1.D3 (IO_L14P_T2_AD4P_SRCC_35); also elsewhere on the board
/A3_HS_10_N: U1.D2 (IO_L17N_T2_AD5N_35); also elsewhere on the board
/A3_HS_10_P: U1.E2 (IO_L17P_T2_AD5P_35); also elsewhere on the board
/A3_HS_11_N: U1.E4 (IO_L21P_T3_DQS_AD14P_35); also elsewhere on the board
/A3_HS_11_P: U1.E3 (IO_L21N_T3_DQS_AD14N_35); also elsewhere on the board
/A3_HS_12_N: U1.F1 (IO_L23N_T3_35); also elsewhere on the board
/A3_HS_12_P: U1.F2 (IO_L23P_T3_35); also elsewhere on the board
/A3_HS_13_N: U1.G1 (IO_L24N_T3_AD15N_35); also elsewhere on the board
/A3_HS_13_P: U1.H1 (IO_L24P_T3_AD15P_35); also elsewhere on the board
/A3_HS_14_N: U1.F4 (IO_L20N_T3_AD6N_35); also elsewhere on the board
/A3_HS_14_P: U1.G4 (IO_L20P_T3_AD6P_35); also elsewhere on the board
/A3_HS_15_N: U1.G2 (IO_L22N_T3_AD7N_35); also elsewhere on the board
/A3_HS_15_P: U1.G3 (IO_L22P_T3_AD7P_35); also elsewhere on the board
/A3_HS_16_N: U1.H4 (IO_L19P_T3_35); also elsewhere on the board
/A3_HS_16_P: U1.H3 (IO_L19N_T3_VREF_35); also elsewhere on the board
/A3_HS_17_N: U1.G6 (IO_L6P_T0_35); also elsewhere on the board
/A3_HS_17_P: U1.F6 (IO_L6N_T0_VREF_35); also elsewhere on the board
/A3_HS_18_N: U1.G8 (IO_L4P_T0_35); also elsewhere on the board
/A3_HS_18_P: U1.G7 (IO_L4N_T0_35); also elsewhere on the board
/A3_LS_GPIO_0: U1.H6 (IO_0_35); also elsewhere on the board
/A3_LS_GPIO_1: U1.H5 (IO_25_35); also elsewhere on the board
/A3_LS_GPIO_2: U1.D7 (IO_L2P_T0_AD8P_35); also elsewhere on the board
/A3_LS_GPIO_3: U1.D6 (IO_L2N_T0_AD8N_35); also elsewhere on the board
/A3_SPI_EN: U1.K8 (IO_L1N_T0_34), U23.8 (OE)
/A4_HS_16_N: U1.L2 (IO_L10P_T1_34); also elsewhere on the board
/A4_HS_16_P: U1.L1 (IO_L10N_T1_34); also elsewhere on the board
/A4_HS_17_N: U1.M2 (IO_L15P_T2_DQS_34); also elsewhere on the board
/A4_HS_17_P: U1.M1 (IO_L15N_T2_DQS_34); also elsewhere on the board
/A4_HS_18_N: U1.P1 (IO_L16N_T2_34); also elsewhere on the board
/A4_HS_18_P: U1.N1 (IO_L16P_T2_34); also elsewhere on the board
/A4_LS_GPIO_0: U1.K2 (IO_L9N_T1_DQS_34); also elsewhere on the board
/A4_LS_GPIO_1: U1.T2 (IO_L13P_T2_MRCC_34); also elsewhere on the board
/A4_LS_GPIO_2: U1.U1 (IO_L14N_T2_SRCC_34); also elsewhere on the board
/A4_LS_GPIO_3: U1.U2 (IO_L14P_T2_SRCC_34); also elsewhere on the board
/EXTIO_CLK_N: U1.L4 (IO_L12N_T1_MRCC_34); also elsewhere on the board
/EXTIO_CLK_P: U1.L5 (IO_L12P_T1_MRCC_34); also elsewhere on the board
/EXTIO_CS: U1.K5 (IO_L7N_T1_34); also elsewhere on the board
/EXTIO_D0_N: U1.N3 (IO_L21N_T3_DQS_34); also elsewhere on the board
/EXTIO_D0_P: U1.N4 (IO_L21P_T3_DQS_34); also elsewhere on the board
/EXTIO_D1_N: U1.P2 (IO_L18N_T2_34); also elsewhere on the board
/EXTIO_D1_P: U1.P3 (IO_L18P_T2_34); also elsewhere on the board
/FPGA_CLK_REF_0: U1.T1 (IO_L13N_T2_MRCC_34); also elsewhere on the board
/FPGA_CLK_REF_1_N: U1.K3 (IO_L11N_T1_SRCC_34); also elsewhere on the board
/FPGA_CLK_REF_1_P: U1.K4 (IO_L11P_T1_SRCC_34); also elsewhere on the board
/GT_LANE0_SEL: U26.6 (S); also elsewhere on the board
/GT_RX0_N: U26.5 (SSRXCOM+); also elsewhere on the board
/GT_RX0_P: U26.4 (SSRXCOM-); also elsewhere on the board
/GT_TX0_N: U26.2 (SSTXCOM+); also elsewhere on the board
/GT_TX0_P: U26.1 (SSTXCOM-); also elsewhere on the board
/Module_A1/MOD_SPI_MISO: U19.10 (B4); also elsewhere on the board
/Module_A1/MOD_SPI_MOSI: U19.12 (B2Y); also elsewhere on the board
/Module_A1/MOD_SPI_SCK: U19.13 (B1Y); also elsewhere on the board
/Module_A3/MOD_SPI_MISO: U23.10 (B4); also elsewhere on the board
/Module_A3/MOD_SPI_MOSI: U23.12 (B2Y); also elsewhere on the board
/Module_A3/MOD_SPI_SCK: U23.13 (B1Y); also elsewhere on the board
/PS_UART1_RX: U33.11 (B3Y); also elsewhere on the board
/PS_UART1_TX: U33.10 (B4); also elsewhere on the board
/SFP_Port/MOD_DEF0: U22.4 (P2); also elsewhere on the board
/SFP_Port/MOD_RS: U22.5 (P3); also elsewhere on the board
/SFP_Port/MOD_RX_DIS: U22.7 (P4); also elsewhere on the board
/SFP_Port/MOD_TX_DIS: U22.3 (P1); also elsewhere on the board
/SFP_Port/MOD_TX_FAULT: U22.2 (P0); also elsewhere on the board
/SFP_Port/SFP_RX_N: U26.10 (SSRX1+); also elsewhere on the board
/SFP_Port/SFP_RX_P: U26.11 (SSRX1-); also elsewhere on the board
/SFP_Port/SFP_TX_N: U26.16 (SSTX1-); also elsewhere on the board
/SFP_Port/SFP_TX_P: U26.15 (SSTX1+); also elsewhere on the board
/SMU/GPIO3: R157.2; also elsewhere on the board
/SMU/GPIO4: R158.2; also elsewhere on the board
/SMU/SPI2_MISO: U32.10 (B4); also elsewhere on the board
/SMU/SPI2_MOSI: U32.13 (B1Y); also elsewhere on the board
/SMU/SPI2_NSS: R109.2, U32.11 (B3Y); also elsewhere on the board
/SMU/SPI2_SCK: U32.12 (B2Y); also elsewhere on the board
/SMU/USART2_RX: U33.5 (A4Y); also elsewhere on the board
/SMU/USART2_TX: U33.4 (A3); also elsewhere on the board
/SMU_CS: U1.J6 (IO_L2N_T0_34), U32.8 (OE)
/SYS_I2C_SCL: U22.12 (SCL); also elsewhere on the board
/SYS_I2C_SDA: U22.13 (SDA); also elsewhere on the board
/SYS_MISO: U1.J1 (IO_L8N_T1_34), U19.5 (A4Y), U23.5 (A4Y), U32.5 (A4Y); also elsewhere on the board
/SYS_MOSI: U1.J2 (IO_L8P_T1_34), U19.3 (A2), U23.3 (A2), U32.2 (A1); also elsewhere on the board
/SYS_SCK: U1.J3 (IO_L9P_T1_DQS_34), U19.2 (A1), U23.2 (A1), U32.3 (A2); also elsewhere on the board
/TMDS_CLK_N: U1.A7 (IO_L9P_T1_DQS_AD3P_35); also elsewhere on the board
/TMDS_CLK_P: U1.A6 (IO_L9N_T1_DQS_AD3N_35); also elsewhere on the board
/TMDS_D0_N: U1.A5 (IO_L10P_T1_AD11P_35); also elsewhere on the board
/TMDS_D0_P: U1.A4 (IO_L10N_T1_AD11N_35); also elsewhere on the board
/TMDS_D1_N: U1.B7 (IO_L8P_T1_AD10P_35); also elsewhere on the board
/TMDS_D1_P: U1.B6 (IO_L8N_T1_AD10N_35); also elsewhere on the board
/TMDS_D2_N: U1.B4 (IO_L13P_T2_MRCC_35); also elsewhere on the board
/TMDS_D2_P: U1.B3 (IO_L13N_T2_MRCC_35); also elsewhere on the board
/USB_RX2_N: U26.8 (SSRX2+); also elsewhere on the board
/USB_RX2_P: U26.9 (SSRX2-); also elsewhere on the board
/USB_SW_S1: U22.8 (P5); also elsewhere on the board
/USB_SW_S2: U22.10 (P7); also elsewhere on the board
/USB_SW_S2_OE: U22.9 (P6); also elsewhere on the board
/USB_TX2_N: U26.14 (SSTX2-); also elsewhere on the board
/USB_TX2_P: U26.13 (SSTX2+); also elsewhere on the board
GND: C271.2, C272.2, C273.2, C274.2, C290.2, C291.2, C292.2, C293.2, U19.4 (A3), U19.7 (GND), U19.15 (EP), U22.6 (GND), U23.4 (A3), U23.7 (GND), U23.15 (EP), U26.3 (GND), U26.7 (OE#), U26.12 (GND), U26.18 (GND), U26.19 (GND), U32.4 (A3), U32.7 (GND), U32.15 (EP), U33.7 (GND), U33.15 (EP); also elsewhere on the board
unnamed: C274.1, R95.2, U22.1 (RESET#)
unnamed: C271.1, C272.1, FB40.1, U26.17 (VDD)
VCCIO_13: U19.14 (VCCB); also elsewhere on the board
VCCIO_34: C290.1, U19.1 (VCCA), U23.1 (VCCA), U32.1 (VCCA); also elsewhere on the board
VCCIO_35: U23.14 (VCCB); also elsewhere on the board
VDD_MCU: C291.1, C292.1, R109.1, U32.14 (VCCB), U33.1 (VCCA); also elsewhere on the board

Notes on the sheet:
BUG_05 - Duplicated GTX coupling caps
74HC595D,118
BUG_06 - I2C SDA/SCL swaped. Run in bit-bang mode
BUG_04 - Ethernet - Eth magnetics connection - disconnect TAB
100,125,156.25MHz
24MHz
BUG_03 - SMU MCU - check divider for voltage senses from 20V rails
25MHz
BUG_01 - missing power connection for Clocking circuits
BUG_02 - Calculate power source feedback dividers
Extension board interface - Source synchronous LVDS tunel, 2 gigabit lanes - @2V5 for Bank 34 - Consider TMDS 3V3 mode for @3V3 operation
Version 0.1 BUG List
GT 0 , 1 Modes - single lane SFP + single lane USB-C - dual line USB-C + cond source on 2.0 pins. PCIe 2x Gen 2 mode

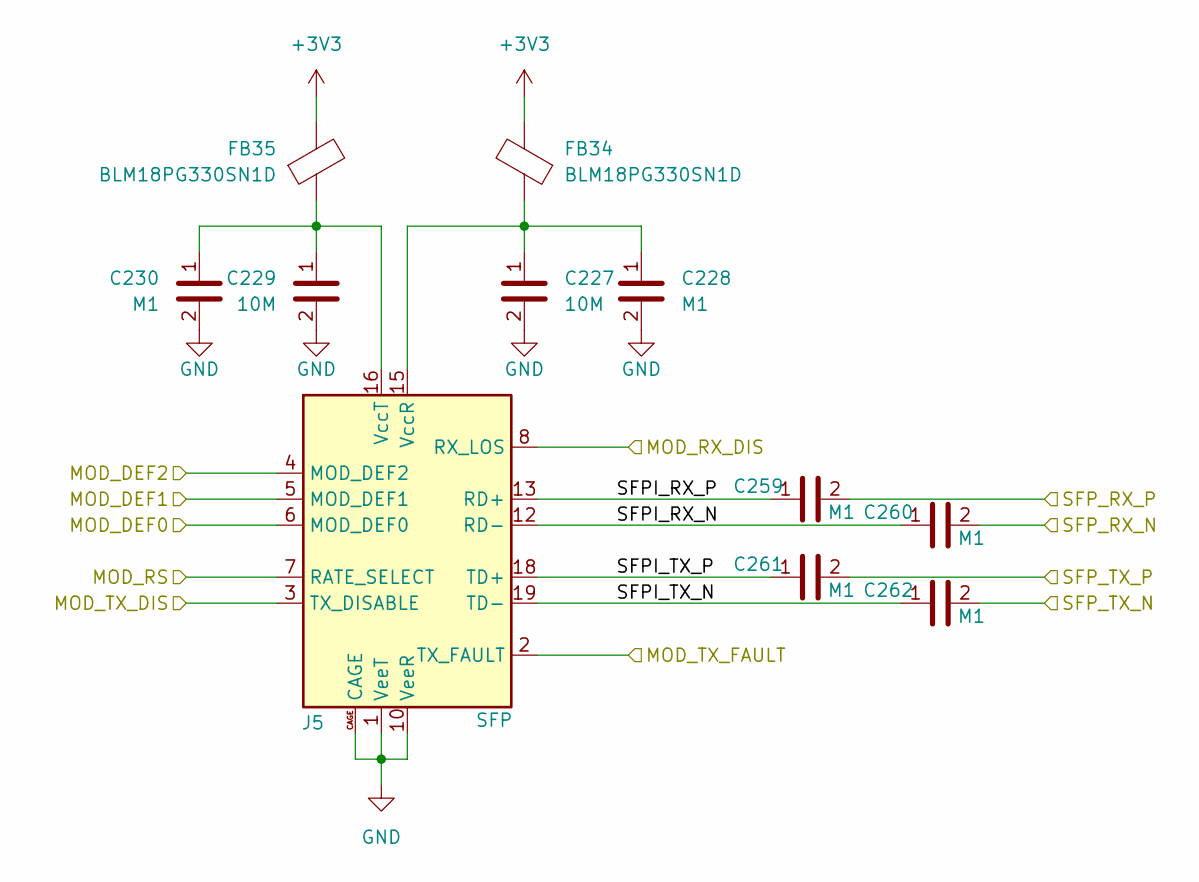
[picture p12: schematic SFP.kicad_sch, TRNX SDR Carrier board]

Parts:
C227, C229: 10M; C_0603_1608Metric; Voltage 100V; JLCPCB Part # C96446
C228, C230, C259, C260, C261, C262: M1; C_0201_0603Metric; Voltage 100V; JLC C49062
FB34, FB35: BLM18PG330SN1D; L_0603_1608Metric; JLCPCB Part # C88984
J5: SFP; Connector_SFP_and_Cage; JLCPCB Part # C42418480

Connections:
+3V3: FB34.2, FB35.2; also elsewhere on the board
/SFP_Port/MOD_DEF0: J5.6 (MOD_DEF0); also elsewhere on the board
/SFP_Port/MOD_RS: J5.7 (RATE_SELECT); also elsewhere on the board
/SFP_Port/MOD_RX_DIS: J5.8 (RX_LOS); also elsewhere on the board
/SFP_Port/MOD_TX_DIS: J5.3 (TX_DISABLE); also elsewhere on the board
/SFP_Port/MOD_TX_FAULT: J5.2 (TX_FAULT); also elsewhere on the board
/SFP_Port/SFPI_RX_N: C260.1, J5.12 (RD-)
/SFP_Port/SFPI_RX_P: C259.1, J5.13 (RD+)
/SFP_Port/SFPI_TX_N: C262.1, J5.19 (TD-)
/SFP_Port/SFPI_TX_P: C261.1, J5.18 (TD+)
/SFP_Port/SFP_RX_N: C260.2; also elsewhere on the board
/SFP_Port/SFP_RX_P: C259.2; also elsewhere on the board
/SFP_Port/SFP_TX_N: C262.2; also elsewhere on the board
/SFP_Port/SFP_TX_P: C261.2; also elsewhere on the board
/SYS_I2C_SCL: J5.5 (MOD_DEF1); also elsewhere on the board
/SYS_I2C_SDA: J5.4 (MOD_DEF2); also elsewhere on the board
GND: C227.2, C228.2, C229.2, C230.2, J5.1 (VeeT), J5.9 (VeeR), J5.10 (VeeR), J5.11 (VeeR), J5.14 (VeeR), J5.17 (VeeT), J5.20 (VeeT), J5.CAGE; also elsewhere on the board
unnamed: C227.1, C228.1, FB34.1, J5.15 (VccR)
unnamed: C229.1, C230.1, FB35.1, J5.16 (VccT)

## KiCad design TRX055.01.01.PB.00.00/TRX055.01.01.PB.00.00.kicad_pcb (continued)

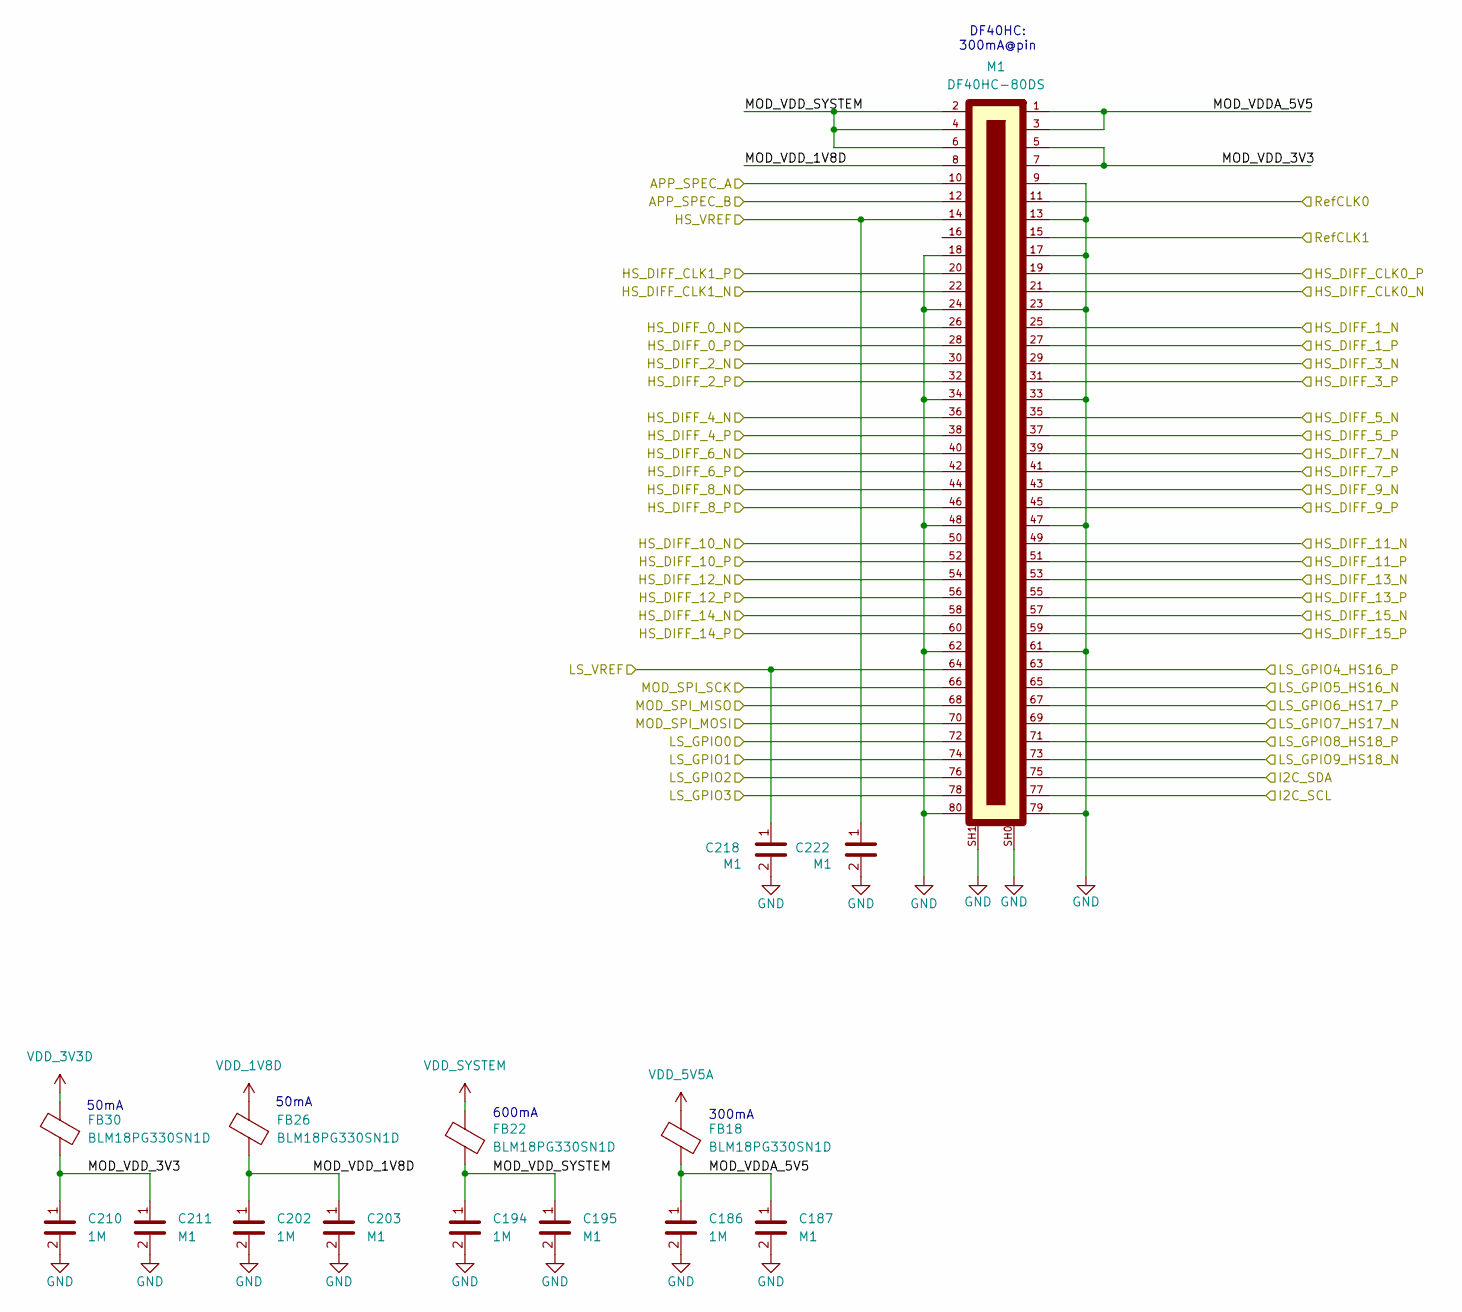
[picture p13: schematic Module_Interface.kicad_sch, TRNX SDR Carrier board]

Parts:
C186, C194, C202, C210: 1M; C_0402_1005Metric; Voltage 100V; JLCPCB Part # C52923
C187, C195, C203, C211, C218, C222: M1; C_0201_0603Metric; Voltage 100V; JLC C49062
FB18, FB22, FB26, FB30: BLM18PG330SN1D; L_0603_1608Metric; JLCPCB Part # C88984
M1: DF40HC-80DS; module_sdr_kit_base; JLCPCB Part # C5254351

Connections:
/A1_HS1_CLK_N: M1.22; also elsewhere on the board
/A1_HS1_CLK_P: M1.20; also elsewhere on the board
/A1_HS_4_N: M1.36; also elsewhere on the board
/A1_HS_4_P: M1.38; also elsewhere on the board
/A1_HS_5_N: M1.35; also elsewhere on the board
/A1_HS_5_P: M1.37; also elsewhere on the board
/A1_HS_6_N: M1.40; also elsewhere on the board
/A1_HS_6_P: M1.42; also elsewhere on the board
/A1_HS_7_N: M1.39; also elsewhere on the board
/A1_HS_7_P: M1.41; also elsewhere on the board
/A1_HS_8_N: M1.44; also elsewhere on the board
/A1_HS_8_P: M1.46; also elsewhere on the board
/A1_HS_9_N: M1.43; also elsewhere on the board
/A1_HS_9_P: M1.45; also elsewhere on the board
/A1_HS_10_N: M1.50; also elsewhere on the board
/A1_HS_10_P: M1.52; also elsewhere on the board
/A1_HS_11_N: M1.49; also elsewhere on the board
/A1_HS_11_P: M1.51; also elsewhere on the board
/A1_HS_12_N: M1.54; also elsewhere on the board
/A1_HS_12_P: M1.56; also elsewhere on the board
/A1_HS_13_N: M1.53; also elsewhere on the board
/A1_HS_13_P: M1.55; also elsewhere on the board
/A1_HS_14_N: M1.58; also elsewhere on the board
/A1_HS_14_P: M1.60; also elsewhere on the board
/A1_HS_15_N: M1.57; also elsewhere on the board
/A1_HS_15_P: M1.59; also elsewhere on the board
/A1_HS_16_N: M1.65; also elsewhere on the board
/A1_HS_16_P: M1.63; also elsewhere on the board
/A1_HS_17_N: M1.69; also elsewhere on the board
/A1_HS_17_P: M1.67; also elsewhere on the board
/A1_HS_18_N: M1.73; also elsewhere on the board
/A1_HS_18_P: M1.71; also elsewhere on the board
/A1_LS_GPIO_0: M1.72; also elsewhere on the board
/A1_LS_GPIO_1: M1.74; also elsewhere on the board
/A1_LS_GPIO_2: M1.76; also elsewhere on the board
/A1_LS_GPIO_3: M1.78; also elsewhere on the board
/GTP_REF_CLK0_N: M1.21; also elsewhere on the board
/GTP_REF_CLK0_P: M1.19; also elsewhere on the board
/GT_RX2_N: M1.29; also elsewhere on the board
/GT_RX2_P: M1.31; also elsewhere on the board
/GT_RX3_N: M1.30; also elsewhere on the board
/GT_RX3_P: M1.32; also elsewhere on the board
/GT_TX2_N: M1.25; also elsewhere on the board
/GT_TX2_P: M1.27; also elsewhere on the board
/GT_TX3_N: M1.26; also elsewhere on the board
/GT_TX3_P: M1.28; also elsewhere on the board
/MOD_A1_REFCLK: M1.11; also elsewhere on the board
/Module_A1/MOD_SPI_MISO: M1.68; also elsewhere on the board
/Module_A1/MOD_SPI_MOSI: M1.70; also elsewhere on the board
/Module_A1/MOD_SPI_SCK: M1.66; also elsewhere on the board
/Module_A1/MOD_VDDA_5V5: C186.1, C187.1, FB18.1, M1.1, M1.3
/Module_A1/MOD_VDD_1V8D: C202.1, C203.1, FB26.1, M1.8
/Module_A1/MOD_VDD_3V3: C210.1, C211.1, FB30.1, M1.5, M1.7
/Module_A1/MOD_VDD_SYSTEM: C194.1, C195.1, FB22.1, M1.2, M1.4, M1.6
/Module_A1/RefCLK1: M1.15
/SYS_I2C_SCL: M1.77; also elsewhere on the board
/SYS_I2C_SDA: M1.75; also elsewhere on the board
/USB_SPEC_N: M1.10; also elsewhere on the board
/USB_SPEC_P: M1.12; also elsewhere on the board
GND: C186.2, C187.2, C194.2, C195.2, C202.2, C203.2, C210.2, C211.2, C218.2, C222.2, M1.9, M1.13, M1.17, M1.18, M1.23, M1.24, M1.33, M1.34, M1.47, M1.48, M1.61, M1.62, M1.79, M1.80, M1.SH0, M1.SH1; also elsewhere on the board
VCCIO_13: C218.1, C222.1, M1.14, M1.64; also elsewhere on the board
VDD_1V8D: FB26.2; also elsewhere on the board
VDD_3V3D: FB30.2; also elsewhere on the board
VDD_5V5A: FB18.2; also elsewhere on the board
VDD_SYSTEM: FB22.2; also elsewhere on the board

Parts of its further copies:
C188, C190, C192, C196, C198, C200, C204, C206, C208, C212, C214, C216: 1M; C_0402_1005Metric; Voltage 100V; JLCPCB Part # C52923
C189, C191, C193, C197, C199, C201, C205, C207, C209, C213, C215, C217, C219, C220, C221, C223, C224, C225: M1; C_0201_0603Metric; Voltage 100V; JLC C49062
FB19, FB20, FB21, FB23, FB24, FB25, FB27, FB28, FB29, FB31, FB32, FB33: BLM18PG330SN1D; L_0603_1608Metric; JLCPCB Part # C88984
M2, M3, M4: DF40HC-80DS; module_sdr_kit_base; JLCPCB Part # C5254351

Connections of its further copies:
/A2_HS0_CLK_N: M2.21
/A2_HS0_CLK_P: M2.19
/A2_HS1_CLK_N: M2.22
/A2_HS1_CLK_P: M2.20
/A2_HS_0_N: M2.26
/A2_HS_0_P: M2.28
/A2_HS_1_N: M2.25
/A2_HS_1_P: M2.27
/A2_HS_2_N: M2.30
/A2_HS_2_P: M2.32
/A2_HS_3_N: M2.29
/A2_HS_3_P: M2.31
/A2_HS_4_N: M2.36
/A2_HS_4_P: M2.38
/A2_HS_5_N: M2.35
/A2_HS_5_P: M2.37
/A2_HS_6_N: M2.40
/A2_HS_6_P: M2.42
/A2_HS_7_N: M2.39
/A2_HS_7_P: M2.41
/A2_HS_8_N: M2.44
/A2_HS_8_P: M2.46
/A2_HS_9_N: M2.43
/A2_HS_9_P: M2.45
/A2_HS_10_N: M2.50
/A2_HS_10_P: M2.52
/A2_HS_11_N: M2.49
/A2_HS_11_P: M2.51
/A2_HS_12_N: M2.54
/A2_HS_12_P: M2.56
/A2_HS_13_N: M2.53
/A2_HS_13_P: M2.55
/A2_HS_14_N: M2.58
/A2_HS_14_P: M2.60
/A2_HS_15_N: M2.57
/A2_HS_15_P: M2.59
/A2_HS_16_N: M2.65; also elsewhere on the board
/A2_HS_16_P: M2.63; also elsewhere on the board
/A2_HS_17_N: M2.69; also elsewhere on the board
/A2_HS_17_P: M2.67; also elsewhere on the board
/A2_HS_18_N: M2.73; also elsewhere on the board
/A2_HS_18_P: M2.71; also elsewhere on the board
/A2_LS_GPIO_0: M2.72; also elsewhere on the board
/A2_LS_GPIO_1: M2.74; also elsewhere on the board
/A2_LS_GPIO_2: M2.76; also elsewhere on the board
/A2_LS_GPIO_3: M2.78; also elsewhere on the board
/A3_HS0_CLK_N: M3.21
/A3_HS0_CLK_P: M3.19
/A3_HS1_CLK_N: M3.22; also elsewhere on the board
/A3_HS1_CLK_P: M3.20; also elsewhere on the board
/A3_HS_0_N: M3.26
/A3_HS_0_P: M3.28
/A3_HS_1_N: M3.25
/A3_HS_1_P: M3.27
/A3_HS_2_N: M3.30
/A3_HS_2_P: M3.32
/A3_HS_3_N: M3.29
/A3_HS_3_P: M3.31
/A3_HS_4_N: M3.36; also elsewhere on the board
/A3_HS_4_P: M3.38; also elsewhere on the board
/A3_HS_5_N: M3.35; also elsewhere on the board
/A3_HS_5_P: M3.37; also elsewhere on the board
/A3_HS_6_N: M3.40; also elsewhere on the board
/A3_HS_6_P: M3.42; also elsewhere on the board
/A3_HS_7_N: M3.39; also elsewhere on the board
/A3_HS_7_P: M3.41; also elsewhere on the board
/A3_HS_8_N: M3.44; also elsewhere on the board
/A3_HS_8_P: M3.46; also elsewhere on the board
/A3_HS_9_N: M3.43; also elsewhere on the board
/A3_HS_9_P: M3.45; also elsewhere on the board
/A3_HS_10_N: M3.50; also elsewhere on the board
/A3_HS_10_P: M3.52; also elsewhere on the board
/A3_HS_11_N: M3.49; also elsewhere on the board
/A3_HS_11_P: M3.51; also elsewhere on the board
/A3_HS_12_N: M3.54; also elsewhere on the board
/A3_HS_12_P: M3.56; also elsewhere on the board
/A3_HS_13_N: M3.53; also elsewhere on the board
/A3_HS_13_P: M3.55; also elsewhere on the board
/A3_HS_14_N: M3.58; also elsewhere on the board
/A3_HS_14_P: M3.60; also elsewhere on the board
/A3_HS_15_N: M3.57; also elsewhere on the board
/A3_HS_15_P: M3.59; also elsewhere on the board
/A3_HS_16_N: M3.65; also elsewhere on the board
/A3_HS_16_P: M3.63; also elsewhere on the board
/A3_HS_17_N: M3.69; also elsewhere on the board
/A3_HS_17_P: M3.67; also elsewhere on the board
/A3_HS_18_N: M3.73; also elsewhere on the board
/A3_HS_18_P: M3.71; also elsewhere on the board
/A3_LS_GPIO_0: M3.72; also elsewhere on the board
/A3_LS_GPIO_1: M3.74; also elsewhere on the board
/A3_LS_GPIO_2: M3.76; also elsewhere on the board
/A3_LS_GPIO_3: M3.78; also elsewhere on the board
/A4_HS0_CLK_N: M4.21
/A4_HS0_CLK_P: M4.19
/A4_HS1_CLK_N: M4.22
/A4_HS1_CLK_P: M4.20
/A4_HS_0_N: M4.26
/A4_HS_0_P: M4.28
/A4_HS_1_N: M4.25
/A4_HS_1_P: M4.27
/A4_HS_2_N: M4.30
/A4_HS_2_P: M4.32
/A4_HS_3_N: M4.29
/A4_HS_3_P: M4.31
/A4_HS_4_N: M4.36
/A4_HS_4_P: M4.38
/A4_HS_5_N: M4.35
/A4_HS_5_P: M4.37
/A4_HS_6_N: M4.40
/A4_HS_6_P: M4.42
/A4_HS_7_N: M4.39
/A4_HS_7_P: M4.41
/A4_HS_8_N: M4.44
/A4_HS_8_P: M4.46
/A4_HS_9_N: M4.43
/A4_HS_9_P: M4.45
/A4_HS_10_N: M4.50
/A4_HS_10_P: M4.52
/A4_HS_11_N: M4.49
/A4_HS_11_P: M4.51
/A4_HS_12_N: M4.54
/A4_HS_12_P: M4.56
/A4_HS_13_N: M4.53
/A4_HS_13_P: M4.55
/A4_HS_14_N: M4.58
/A4_HS_14_P: M4.60
/A4_HS_15_N: M4.57
/A4_HS_15_P: M4.59
/A4_HS_16_N: M4.65; also elsewhere on the board
/A4_HS_16_P: M4.63; also elsewhere on the board
/A4_HS_17_N: M4.69; also elsewhere on the board
/A4_HS_17_P: M4.67; also elsewhere on the board
/A4_HS_18_N: M4.73; also elsewhere on the board
/A4_HS_18_P: M4.71; also elsewhere on the board
/A4_LS_GPIO_0: M4.72; also elsewhere on the board
/A4_LS_GPIO_1: M4.74; also elsewhere on the board
/A4_LS_GPIO_2: M4.76; also elsewhere on the board
/A4_LS_GPIO_3: M4.78; also elsewhere on the board
/MOD_A2_REFCLK: M2.11; also elsewhere on the board
/MOD_A3_REFCLK: M3.11; also elsewhere on the board
/MOD_A4_REFCLK: M4.11; also elsewhere on the board
/Module_A2/APP_SPEC_A: M2.10
/Module_A2/APP_SPEC_B: M2.12
/Module_A2/MOD_VDDA_5V5: C188.1, C189.1, FB19.1, M2.1, M2.3
/Module_A2/MOD_VDD_1V8D: C204.1, C205.1, FB27.1, M2.8
/Module_A2/MOD_VDD_3V3: C212.1, C213.1, FB31.1, M2.5, M2.7
/Module_A2/MOD_VDD_SYSTEM: C196.1, C197.1, FB23.1, M2.2, M2.4, M2.6
/Module_A2/RefCLK1: M2.15
/Module_A3/APP_SPEC_A: M3.10
/Module_A3/APP_SPEC_B: M3.12
/Module_A3/MOD_SPI_MISO: M3.68; also elsewhere on the board
/Module_A3/MOD_SPI_MOSI: M3.70; also elsewhere on the board
/Module_A3/MOD_SPI_SCK: M3.66; also elsewhere on the board
/Module_A3/MOD_VDDA_5V5: C190.1, C191.1, FB20.1, M3.1, M3.3
/Module_A3/MOD_VDD_1V8D: C206.1, C207.1, FB28.1, M3.8
/Module_A3/MOD_VDD_3V3: C214.1, C215.1, FB32.1, M3.5, M3.7
/Module_A3/MOD_VDD_SYSTEM: C198.1, C199.1, FB24.1, M3.2, M3.4, M3.6
/Module_A3/RefCLK1: M3.15
/Module_A4/APP_SPEC_A: M4.10
/Module_A4/APP_SPEC_B: M4.12
/Module_A4/MOD_VDDA_5V5: C192.1, C193.1, FB21.1, M4.1, M4.3
/Module_A4/MOD_VDD_1V8D: C208.1, C209.1, FB29.1, M4.8
/Module_A4/MOD_VDD_3V3: C216.1, C217.1, FB33.1, M4.5, M4.7
/Module_A4/MOD_VDD_SYSTEM: C200.1, C201.1, FB25.1, M4.2, M4.4, M4.6
/Module_A4/RefCLK1: M4.15
/SYS_I2C_SCL: M2.77, M3.77, M4.77; also elsewhere on the board
/SYS_I2C_SDA: M2.75, M3.75, M4.75; also elsewhere on the board
/SYS_MISO: M2.68, M4.68; also elsewhere on the board
/SYS_MOSI: M2.70, M4.70; also elsewhere on the board
/SYS_SCK: M2.66, M4.66; also elsewhere on the board
GND: C188.2, C189.2, C190.2, C191.2, C192.2, C193.2, C196.2, C197.2, C198.2, C199.2, C200.2, C201.2, C204.2, C205.2, C206.2, C207.2, C208.2, C209.2, C212.2, C213.2, C214.2, C215.2, C216.2, C217.2, C219.2, C220.2, C221.2, C223.2, C224.2, C225.2, M2.9, M2.13, M2.17, M2.18, M2.23, M2.24, M2.33, M2.34, M2.47, M2.48, M2.61, M2.62, M2.79, M2.80, M2.SH0, M2.SH1, M3.9, M3.13, M3.17, M3.18, M3.23, M3.24, M3.33, M3.34, M3.47, M3.48, M3.61, M3.62, M3.79, M3.80, M3.SH0, M3.SH1, M4.9, M4.13, M4.17, M4.18, M4.23, M4.24, M4.33, M4.34, M4.47, M4.48, M4.61, M4.62, M4.79, M4.80, M4.SH0, M4.SH1; also elsewhere on the board
VCCIO_34: C219.1, C221.1, C223.1, C225.1, M2.14, M2.64, M4.14, M4.64; also elsewhere on the board
VCCIO_35: C220.1, C224.1, M3.14, M3.64; also elsewhere on the board
VDD_1V8D: FB27.2, FB28.2, FB29.2; also elsewhere on the board
VDD_3V3D: FB31.2, FB32.2, FB33.2; also elsewhere on the board
VDD_5V5A: FB19.2, FB20.2, FB21.2; also elsewhere on the board
VDD_SYSTEM: FB23.2, FB24.2, FB25.2; also elsewhere on the board

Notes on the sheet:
50mA
300mA
DF40HC: 300mA@pin
600mA

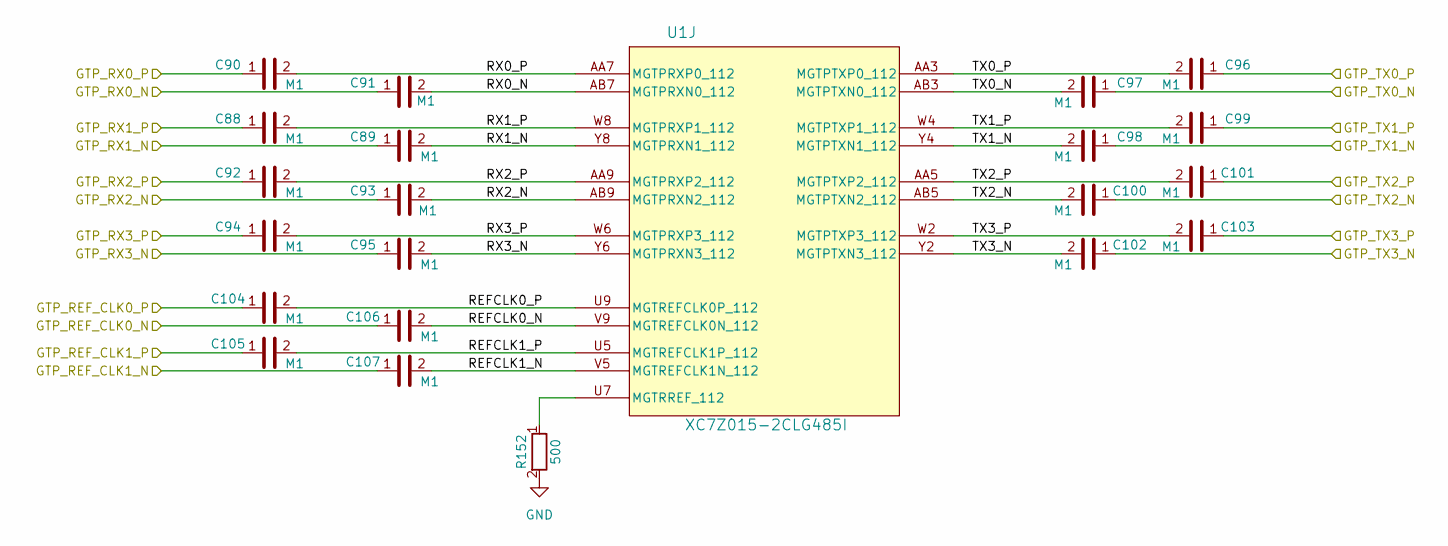
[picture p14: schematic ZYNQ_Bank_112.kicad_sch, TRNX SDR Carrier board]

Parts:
C88, C89, C90, C91, C92, C93, C94, C95, C96, C97, C98, C99, C100, C101, C102, C103, C104, C105, C106, C107: M1; C_0201_0603Metric; Voltage 100V; JLC C49062
R152: 500; R_0402_1005Metric; Tolerance =< 5%; JLCPCB Part # C25744
U1: XC7Z015-2CLG485I; CLG485XC7Z012S&slash_XC7Z015_AMD; JLCPCB Part # C1522056

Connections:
/GTP_REF_CLK0_N: C106.1; also elsewhere on the board
/GTP_REF_CLK0_P: C104.1; also elsewhere on the board
/GTP_REF_CLK1_N: C105.1; also elsewhere on the board
/GTP_REF_CLK1_P: C107.1; also elsewhere on the board
/GT_RX0_N: C91.1; also elsewhere on the board
/GT_RX0_P: C90.1; also elsewhere on the board
/GT_RX1_N: C89.1; also elsewhere on the board
/GT_RX1_P: C88.1; also elsewhere on the board
/GT_RX2_N: C93.1; also elsewhere on the board
/GT_RX2_P: C92.1; also elsewhere on the board
/GT_RX3_N: C95.1; also elsewhere on the board
/GT_RX3_P: C94.1; also elsewhere on the board
/GT_TX0_N: C97.1; also elsewhere on the board
/GT_TX0_P: C96.1; also elsewhere on the board
/GT_TX1_N: C98.1; also elsewhere on the board
/GT_TX1_P: C99.1; also elsewhere on the board
/GT_TX2_N: C100.1; also elsewhere on the board
/GT_TX2_P: C101.1; also elsewhere on the board
/GT_TX3_N: C102.1; also elsewhere on the board
/GT_TX3_P: C103.1; also elsewhere on the board
/ZYNQ_Bank_112/REFCLK0_N: C106.2, U1.V9 (MGTREFCLK0N_112)
/ZYNQ_Bank_112/REFCLK0_P: C104.2, U1.U9 (MGTREFCLK0P_112)
/ZYNQ_Bank_112/REFCLK1_N: C107.2, U1.V5 (MGTREFCLK1N_112)
/ZYNQ_Bank_112/REFCLK1_P: C105.2, U1.U5 (MGTREFCLK1P_112)
/ZYNQ_Bank_112/RX0_N: C91.2, U1.AB7 (MGTPRXN0_112)
/ZYNQ_Bank_112/RX0_P: C90.2, U1.AA7 (MGTPRXP0_112)
/ZYNQ_Bank_112/RX1_N: C89.2, U1.Y8 (MGTPRXN1_112)
/ZYNQ_Bank_112/RX1_P: C88.2, U1.W8 (MGTPRXP1_112)
/ZYNQ_Bank_112/RX2_N: C93.2, U1.AB9 (MGTPRXN2_112)
/ZYNQ_Bank_112/RX2_P: C92.2, U1.AA9 (MGTPRXP2_112)
/ZYNQ_Bank_112/RX3_N: C95.2, U1.Y6 (MGTPRXN3_112)
/ZYNQ_Bank_112/RX3_P: C94.2, U1.W6 (MGTPRXP3_112)
/ZYNQ_Bank_112/TX0_N: C97.2, U1.AB3 (MGTPTXN0_112)
/ZYNQ_Bank_112/TX0_P: C96.2, U1.AA3 (MGTPTXP0_112)
/ZYNQ_Bank_112/TX1_N: C98.2, U1.Y4 (MGTPTXN1_112)
/ZYNQ_Bank_112/TX1_P: C99.2, U1.W4 (MGTPTXP1_112)
/ZYNQ_Bank_112/TX2_N: C100.2, U1.AB5 (MGTPTXN2_112)
/ZYNQ_Bank_112/TX2_P: C101.2, U1.AA5 (MGTPTXP2_112)
/ZYNQ_Bank_112/TX3_N: C102.2, U1.Y2 (MGTPTXN3_112)
/ZYNQ_Bank_112/TX3_P: C103.2, U1.W2 (MGTPTXP3_112)
GND: R152.2; also elsewhere on the board
unnamed: R152.1, U1.U7 (MGTRREF_112)

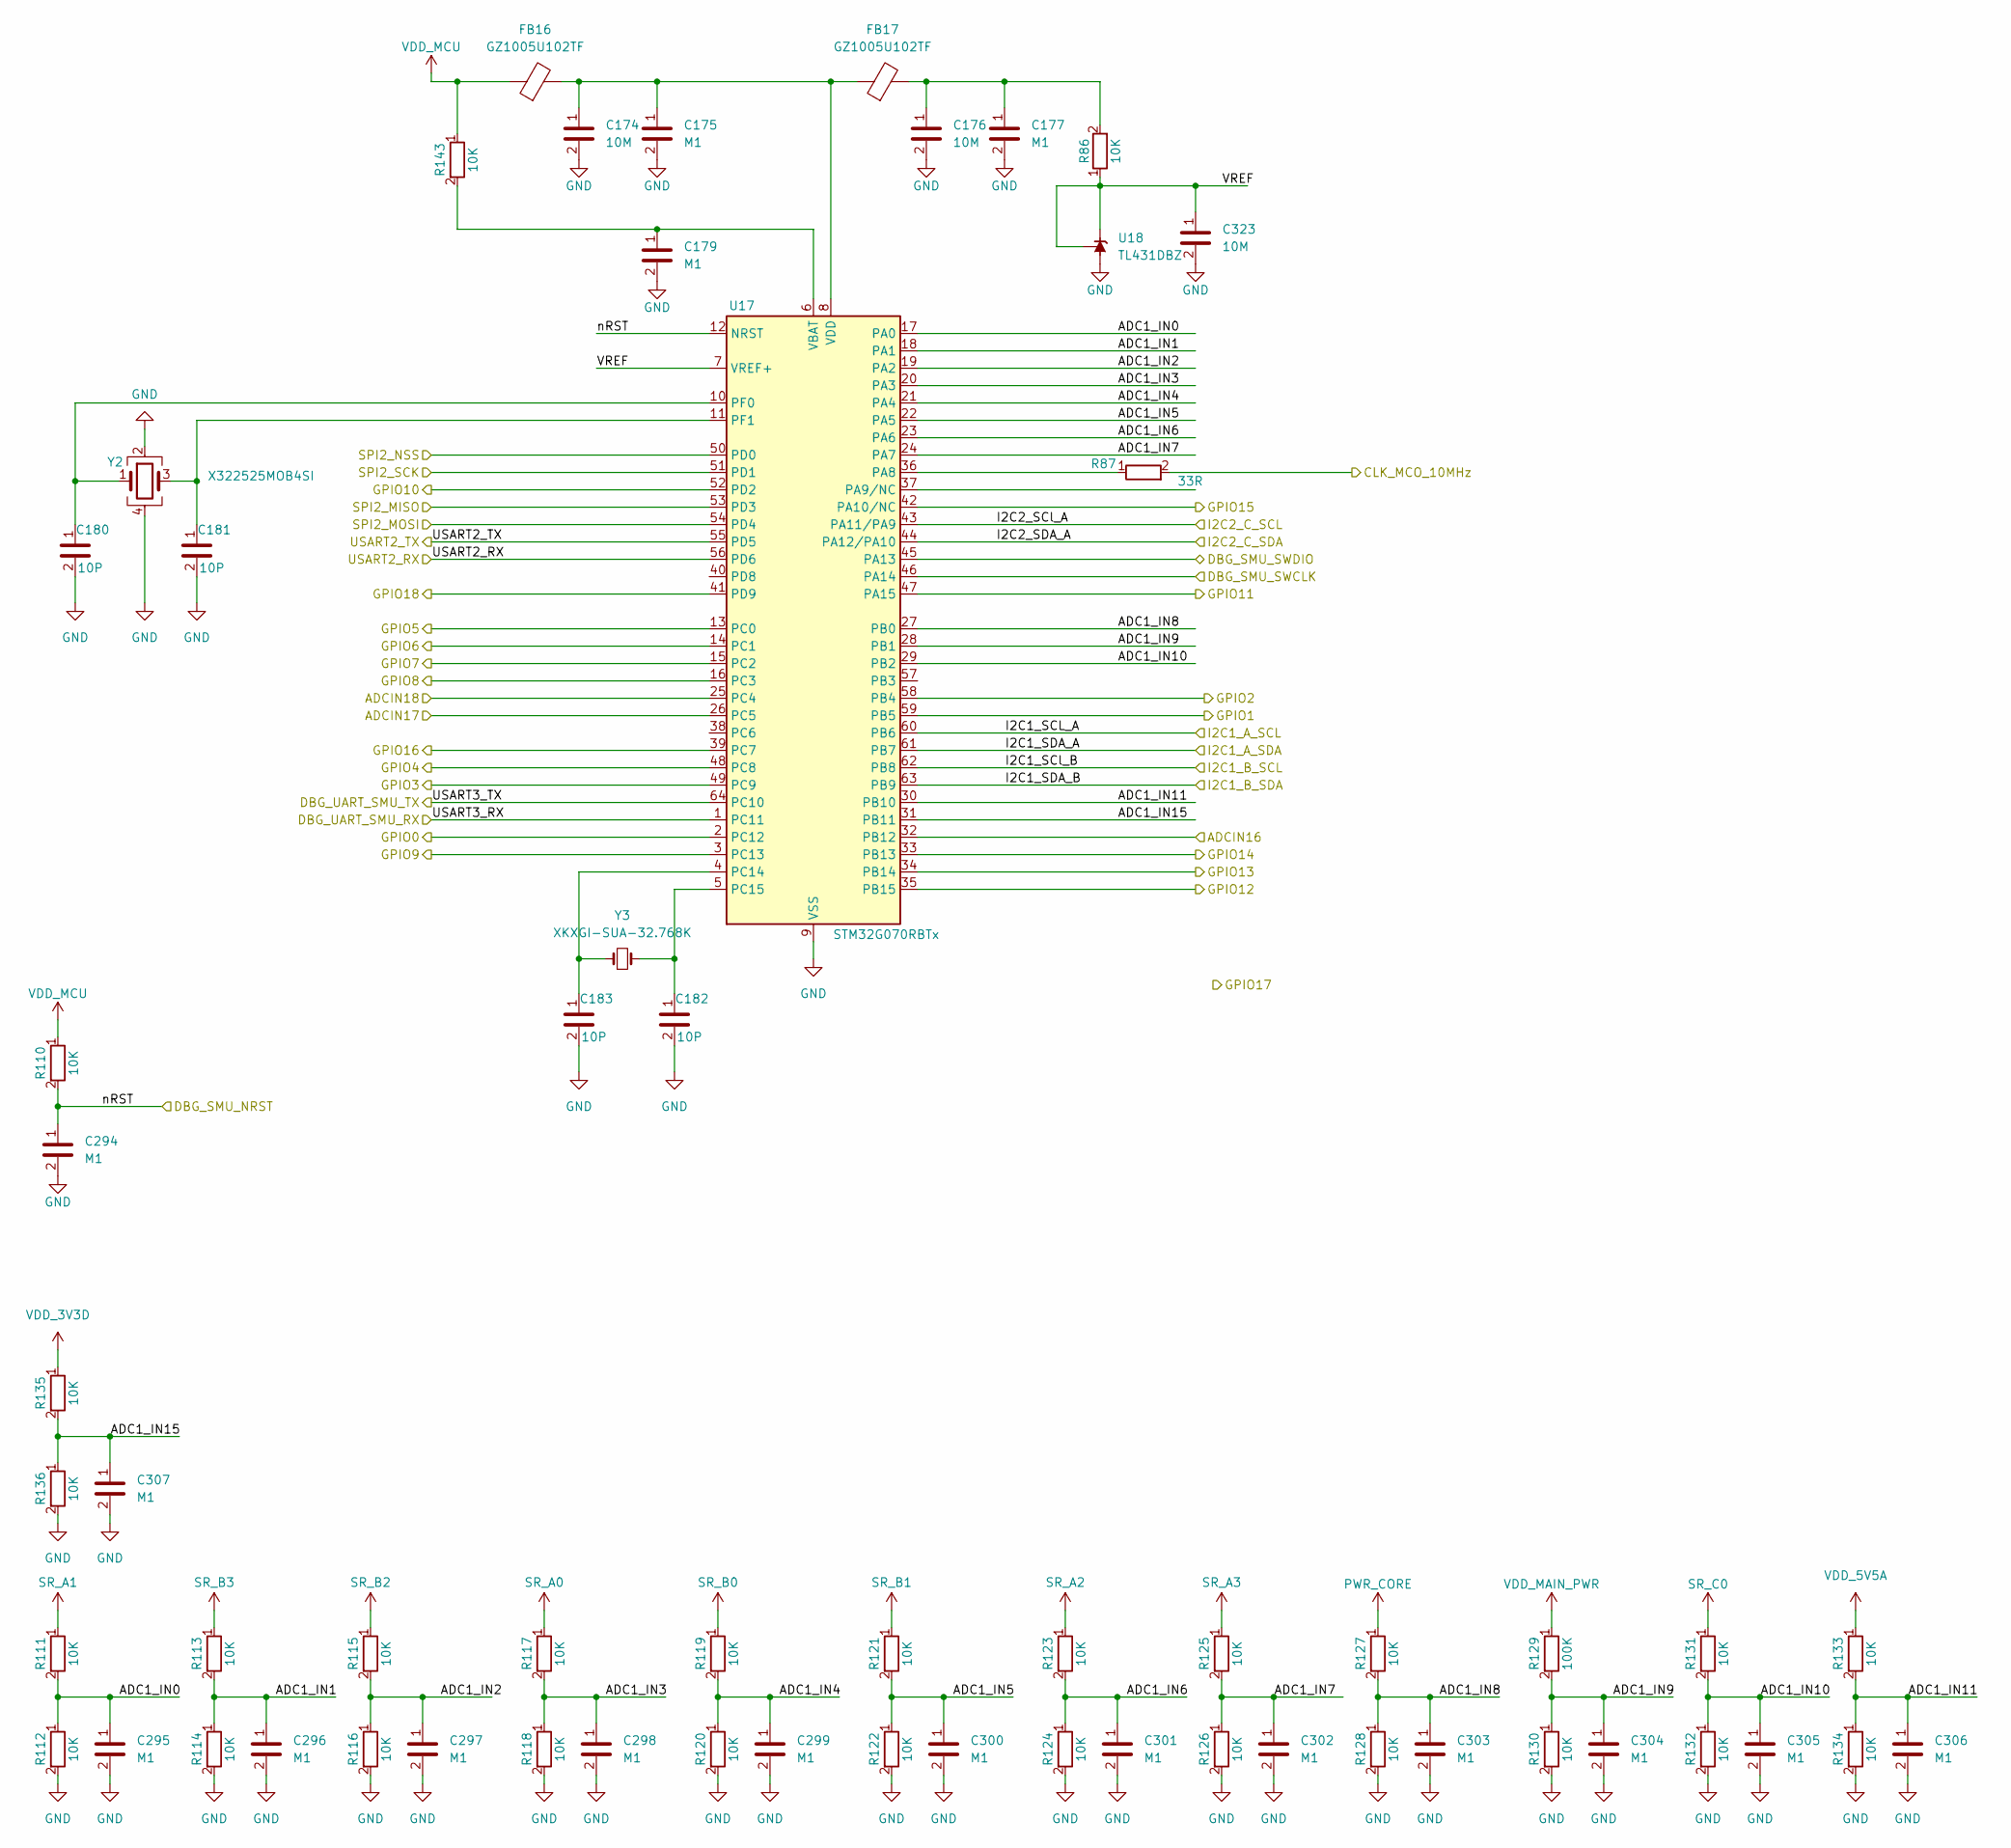
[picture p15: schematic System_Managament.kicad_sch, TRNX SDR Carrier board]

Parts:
C174, C176, C323: 10M; C_0603_1608Metric; Voltage 100V; JLCPCB Part # C96446
C175, C177, C179, C294, C295, C296, C297, C298, C299, C300, C301, C302, C303, C304, C305, C306, C307: M1; C_0201_0603Metric; Voltage 100V; JLC C49062
C180, C181, C182, C183: 10P; C_0402_1005Metric; Voltage 100V; JLCPCB Part # C25744
FB16, FB17: GZ1005U102TF; L_0402_1005Metric_Pad0.77x0.64mm_HandSolder; JLCPCB Part # C19136
R86: 10K; R_0402_1005Metric; Tolerance =< 5%; JLCPCB Part # C25105
R87: 33R; R_0402_1005Metric; Tolerance =< 5%; JLCPCB Part # C25105
R110, R111, R112, R113, R114, R115, R116, R117, R118, R119, R120, R121, R122, R123, R124, R125, R126, R127, R128, R130, R131, R132, R133, R134, R135, R136, R143: 10K; R_0402_1005Metric; Tolerance =< 5%; JLCPCB Part # C25744
R129: 100K; R_0402_1005Metric; Tolerance =< 5%; JLCPCB Part # C25744
U17: STM32G070RBTx; LQFP-64_10x10mm_P0.5mm; JLCPCB Part # C529340
U18: TL431DBZ; SOT-23
Y2: X322525MOB4SI; Crystal_SMD_3225-4Pin_3.2x2.5mm; JLCPCB Part # C9006
Y3: XKXGI-SUA-32.768K; Crystal_SMD_3215-2Pin_3.2x1.5mm; JLCPCB Part # C5213671

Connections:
/Clocking/CLK_REF_IN: R87.2; also elsewhere on the board
/Clocking/EXT_REF_EN: U17.41 (PD9); also elsewhere on the board
/FCCLK: U17.39 (PC7); also elsewhere on the board
/GT_LANE0_SEL: U17.35 (PB15); also elsewhere on the board
/HDMI/HDMI_HPD: U17.59 (PB5); also elsewhere on the board
/PWR_3V3D_EN: U17.42 (PA10/NC); also elsewhere on the board
/PWR_5V5A_EN: U17.14 (PC1); also elsewhere on the board
/PWR_CORE_EN: U17.13 (PC0); also elsewhere on the board
/PWR_MAIN_EN: U17.34 (PB14); also elsewhere on the board
/PWR_MAIN_IMON: U17.32 (PB12); also elsewhere on the board
/PWR_MAIN_PG: U17.33 (PB13); also elsewhere on the board
/PWR_MP_EN: U17.16 (PC3); also elsewhere on the board
/PWR_MP_IMON: U17.26 (PC5); also elsewhere on the board
/PWR_MP_PG: U17.15 (PC2); also elsewhere on the board
/SMU/ADC1_IN0: C295.1, R111.2, R112.1, U17.17 (PA0)
/SMU/ADC1_IN1: C296.1, R113.2, R114.1, U17.18 (PA1)
/SMU/ADC1_IN2: C297.1, R115.2, R116.1, U17.19 (PA2)
/SMU/ADC1_IN3: C298.1, R117.2, R118.1, U17.20 (PA3)
/SMU/ADC1_IN4: C299.1, R119.2, R120.1, U17.21 (PA4)
/SMU/ADC1_IN5: C300.1, R121.2, R122.1, U17.22 (PA5)
/SMU/ADC1_IN6: C301.1, R123.2, R124.1, U17.23 (PA6)
/SMU/ADC1_IN7: C302.1, R125.2, R126.1, U17.24 (PA7)
/SMU/ADC1_IN8: C303.1, R127.2, R128.1, U17.27 (PB0)
/SMU/ADC1_IN9: C304.1, R129.2, R130.1, U17.28 (PB1)
/SMU/ADC1_IN10: C305.1, R131.2, R132.1, U17.29 (PB2)
/SMU/ADC1_IN11: C306.1, R133.2, R134.1, U17.30 (PB10)
/SMU/ADC1_IN15: C307.1, R135.2, R136.1, U17.31 (PB11)
/SMU/ADCIN18: U17.25 (PC4)
/SMU/DBG_SMU_SWCLK: U17.46 (PA14); also elsewhere on the board
/SMU/DBG_SMU_SWDIO: U17.45 (PA13); also elsewhere on the board
/SMU/GPIO0: U17.2 (PC12); also elsewhere on the board
/SMU/GPIO2: U17.58 (PB4); also elsewhere on the board
/SMU/GPIO3: U17.49 (PC9); also elsewhere on the board
/SMU/GPIO4: U17.48 (PC8); also elsewhere on the board
/SMU/GPIO9: U17.3 (PC13); also elsewhere on the board
/SMU/GPIO10: U17.52 (PD2); also elsewhere on the board
/SMU/GPIO11: U17.47 (PA15); also elsewhere on the board
/SMU/I2C1_SCL_A: U17.60 (PB6); also elsewhere on the board
/SMU/I2C1_SCl_B: U17.62 (PB8); also elsewhere on the board
/SMU/I2C1_SDA_A: U17.61 (PB7); also elsewhere on the board
/SMU/I2C1_SDA_B: U17.63 (PB9); also elsewhere on the board
/SMU/SPI2_MISO: U17.53 (PD3); also elsewhere on the board
/SMU/SPI2_MOSI: U17.54 (PD4); also elsewhere on the board
/SMU/SPI2_NSS: U17.50 (PD0); also elsewhere on the board
/SMU/SPI2_SCK: U17.51 (PD1); also elsewhere on the board
/SMU/USART2_RX: U17.56 (PD6); also elsewhere on the board
/SMU/USART2_TX: U17.55 (PD5); also elsewhere on the board
/SMU/USART3_RX: U17.1 (PC11); also elsewhere on the board
/SMU/USART3_TX: U17.64 (PC10); also elsewhere on the board
/SMU/VREF: C323.1, R86.1, U17.7 (VREF+), U18.1 (K), U18.2 (REF)
/SMU/nRST: C294.1, R110.2, U17.12 (NRST); also elsewhere on the board
/SYS_I2C_SCL: U17.43 (PA11/PA9); also elsewhere on the board
/SYS_I2C_SDA: U17.44 (PA12/PA10); also elsewhere on the board
GND: C174.2, C175.2, C176.2, C177.2, C179.2, C180.2, C181.2, C182.2, C183.2, C294.2, C295.2, C296.2, C297.2, C298.2, C299.2, C300.2, C301.2, C302.2, C303.2, C304.2, C305.2, C306.2, C307.2, C323.2, R112.2, R114.2, R116.2, R118.2, R120.2, R122.2, R124.2, R126.2, R128.2, R130.2, R132.2, R134.2, R136.2, U17.9 (VSS), U18.3 (A), Y2.2, Y2.4; also elsewhere on the board
unnamed: C176.1, C177.1, FB17.2, R86.2
unnamed: R87.1, U17.36 (PA8)
unnamed: C183.1, U17.4 (PC14), Y3.1
unnamed: C182.1, U17.5 (PC15), Y3.2
unnamed: C180.1, U17.10 (PF0), Y2.1
unnamed: C181.1, U17.11 (PF1), Y2.3
unnamed: C179.1, R143.2, U17.6 (VBAT)
unnamed: C174.1, C175.1, FB16.2, FB17.1, U17.8 (VDD)
PWR_CORE: R127.1; also elsewhere on the board
SR_A0: R117.1; also elsewhere on the board
SR_A1: R111.1; also elsewhere on the board
SR_A2: R123.1; also elsewhere on the board
SR_A3: R125.1; also elsewhere on the board
SR_B0: R119.1; also elsewhere on the board
SR_B1: R121.1; also elsewhere on the board
SR_B2: R115.1; also elsewhere on the board
SR_B3: R113.1; also elsewhere on the board
SR_C0: R131.1; also elsewhere on the board
VDD_3V3D: R135.1; also elsewhere on the board
VDD_5V5A: R133.1; also elsewhere on the board
VDD_MAIN_PWR: R129.1; also elsewhere on the board
VDD_MCU: FB16.1, R110.1, R143.1; also elsewhere on the board

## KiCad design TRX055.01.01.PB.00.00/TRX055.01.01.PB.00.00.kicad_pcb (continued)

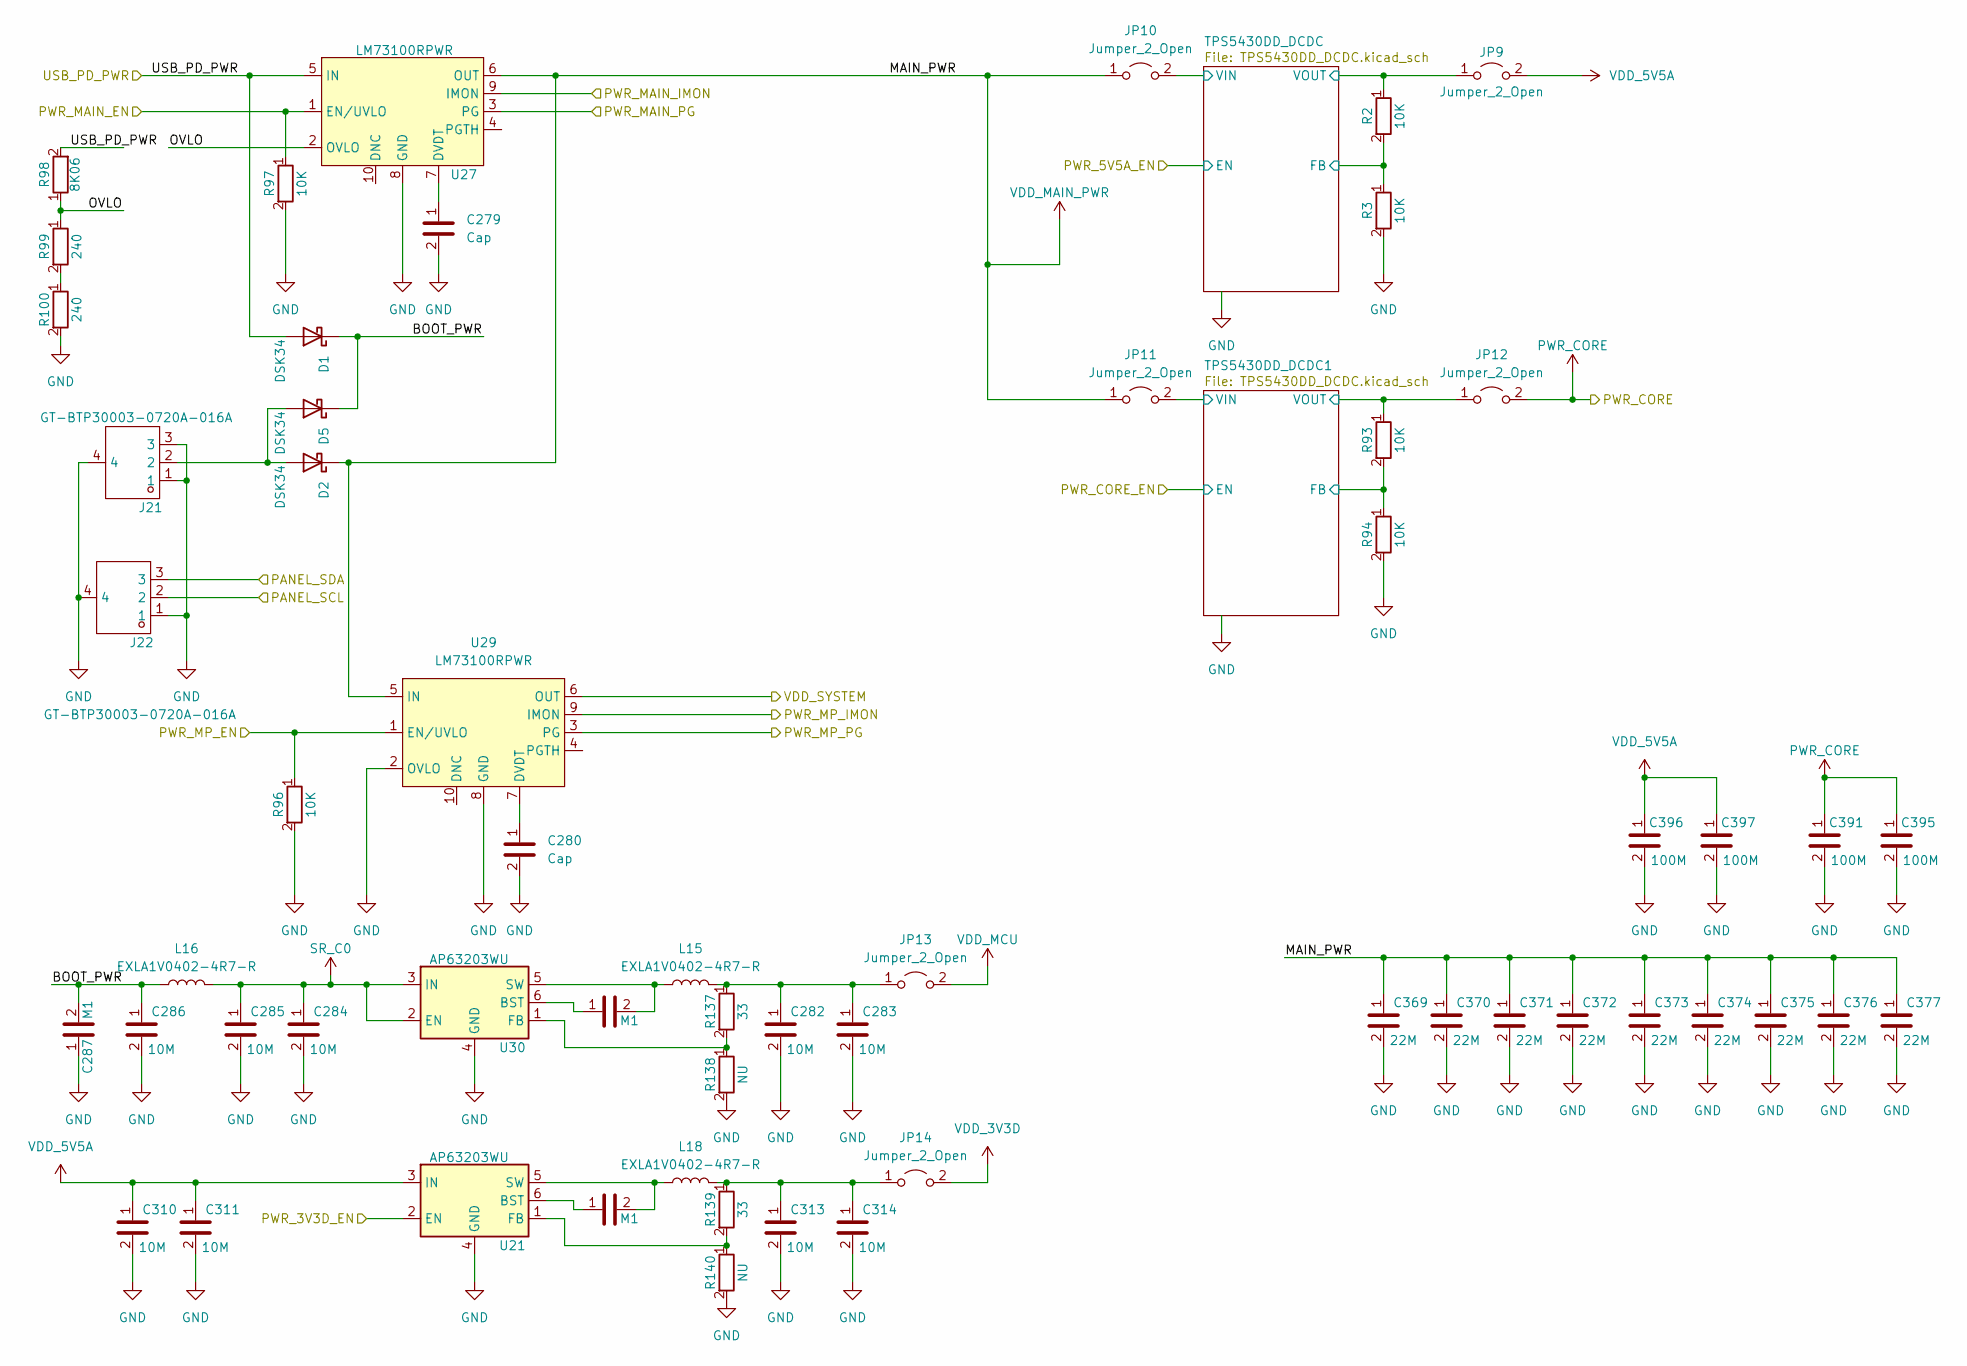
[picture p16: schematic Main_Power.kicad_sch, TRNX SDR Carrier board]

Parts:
C279, C280: Cap; C_0402_1005Metric; Voltage 100V
C281, C287, C312: M1; C_0201_0603Metric; Voltage 100V; JLC C49062
C282, C283, C284, C285, C286, C310, C311, C313, C314: 10M; C_0603_1608Metric; Voltage 100V; JLCPCB Part # C96446
C369, C370, C371, C372, C373, C374, C375, C376, C377: 22M; C_0603_1608Metric; Voltage 35V; JLCPCB Part # C338080
C391, C395, C396, C397: 100M; C_1206_3216Metric; Voltage 100V; JLCPCB Part # C15008
D1, D2, D5: DSK34; D_SOD-123F; JLCPCB Part # C727076
J21, J22: GT-BTP30003-0720A-016A; BAT-SMD_GT-BTP30003-0500A-016A-1; Manufacturer Part GT-BTP30003-0720A-016A; LCSC Part Name 卧式Pitch3.0 3P电池座
JP9, JP10, JP11, JP12, JP13, JP14: Jumper_2_Open; SolderJumper-2_P1.3mm_open_Pad1.0x1.5mm
L15, L16, L18: EXLA1V0402-4R7-R; EXLA1V04
R2, R3, R93, R94, R96, R97: 10K; R_0402_1005Metric; Tolerance =< 5%; JLCPCB Part # C25744
R98: 8K06; R_0402_1005Metric; Tolerance =< 5%; JLCPCB Part # C276278
R99, R100: 240; R_0402_1005Metric; Tolerance =< 5%; JLCPCB Part # C25744
R137, R139: 33; R_0402_1005Metric; Tolerance =< 5%; JLCPCB Part # C25744
R138, R140: NU; R_0402_1005Metric; Tolerance =< 5%; JLCPCB Part # C25744
U21, U30: AP63203WU; TSOT-23-6
U27, U29: LM73100RPWR; VQFN-10_L2.0-W2.0-P0.45-TL; Manufacturer Part LM73100RPWR; LCSC Part Name 具有输入反极性保护和过压保护功能的集成式理想二极管

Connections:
/Main_Power/BOOT_PWR: C286.1, C287.2, D1.1 (K), D5.1 (K), L16.1
/Main_Power/OVLO: R98.1, R99.1, U27.2 (OVLO)
/Main_Power/TPS5430DD_DCDC1/FB: R93.2, R94.1; also elsewhere on the board
/Main_Power/TPS5430DD_DCDC1/TPSVOUT: JP12.1 (A), R93.1; also elsewhere on the board
/Main_Power/TPS5430DD_DCDC1/VIN: JP11.2 (B); also elsewhere on the board
/Main_Power/TPS5430DD_DCDC/FB: R2.2, R3.1; also elsewhere on the board
/Main_Power/TPS5430DD_DCDC/TPSVOUT: JP9.1 (A), R2.1; also elsewhere on the board
/Main_Power/TPS5430DD_DCDC/VIN: JP10.2 (B); also elsewhere on the board
/PWR_3V3D_EN: U21.2 (EN); also elsewhere on the board
/PWR_MAIN_EN: R97.1, U27.1 (EN/UVLO); also elsewhere on the board
/PWR_MAIN_IMON: U27.9 (IMON); also elsewhere on the board
/PWR_MAIN_PG: U27.3 (PG); also elsewhere on the board
/PWR_MP_EN: R96.1, U29.1 (EN/UVLO); also elsewhere on the board
/PWR_MP_IMON: U29.9 (IMON); also elsewhere on the board
/PWR_MP_PG: U29.3 (PG); also elsewhere on the board
/SYS_I2C_SCL: J22.2; also elsewhere on the board
/SYS_I2C_SDA: J22.3; also elsewhere on the board
/USB_VUSB: D1.2 (A), R98.2, U27.5 (IN); also elsewhere on the board
GND: C279.2, C280.2, C282.2, C283.2, C284.2, C285.2, C286.2, C287.1, C310.2, C311.2, C313.2, C314.2, C369.2, C370.2, C371.2, C372.2, C373.2, C374.2, C375.2, C376.2, C377.2, C391.2, C395.2, C396.2, C397.2, J21.1, J21.3, J21.4, J22.1, J22.4, R3.2, R94.2, R96.2, R97.2, R100.2, R138.2, R140.2, U21.4 (GND), U27.8 (GND), U29.2 (OVLO), U29.8 (GND), U30.4 (GND); also elsewhere on the board
unnamed: D2.2 (A), D5.2 (A), J21.2
unnamed: C282.1, C283.1, JP13.1 (A), L15.2, R137.1
unnamed: C313.1, C314.1, JP14.1 (A), L18.2, R139.1
unnamed: R99.2, R100.1
unnamed: C312.1, U21.6 (BST)
unnamed: R139.2, R140.1, U21.1 (FB)
unnamed: C312.2, L18.1, U21.5 (SW)
unnamed: C279.1, U27.7 (DVDT)
unnamed: C280.1, U29.7 (DVDT)
unnamed: C281.1, U30.6 (BST)
unnamed: R137.2, R138.1, U30.1 (FB)
unnamed: C281.2, L15.1, U30.5 (SW)
PWR_CORE: C391.1, C395.1, JP12.2 (B); also elsewhere on the board
SR_C0: C284.1, C285.1, L16.2, U30.2 (EN), U30.3 (IN); also elsewhere on the board
VDD_3V3D: JP14.2 (B); also elsewhere on the board
VDD_5V5A: C310.1, C311.1, C396.1, C397.1, JP9.2 (B), U21.3 (IN); also elsewhere on the board
VDD_MAIN_PWR: C369.1, C370.1, C371.1, C372.1, C373.1, C374.1, C375.1, C376.1, C377.1, D2.1 (K), JP10.1 (A), JP11.1 (A), U27.6 (OUT), U29.5 (IN); also elsewhere on the board
VDD_MCU: JP13.2 (B); also elsewhere on the board
VDD_SYSTEM: U29.6 (OUT); also elsewhere on the board

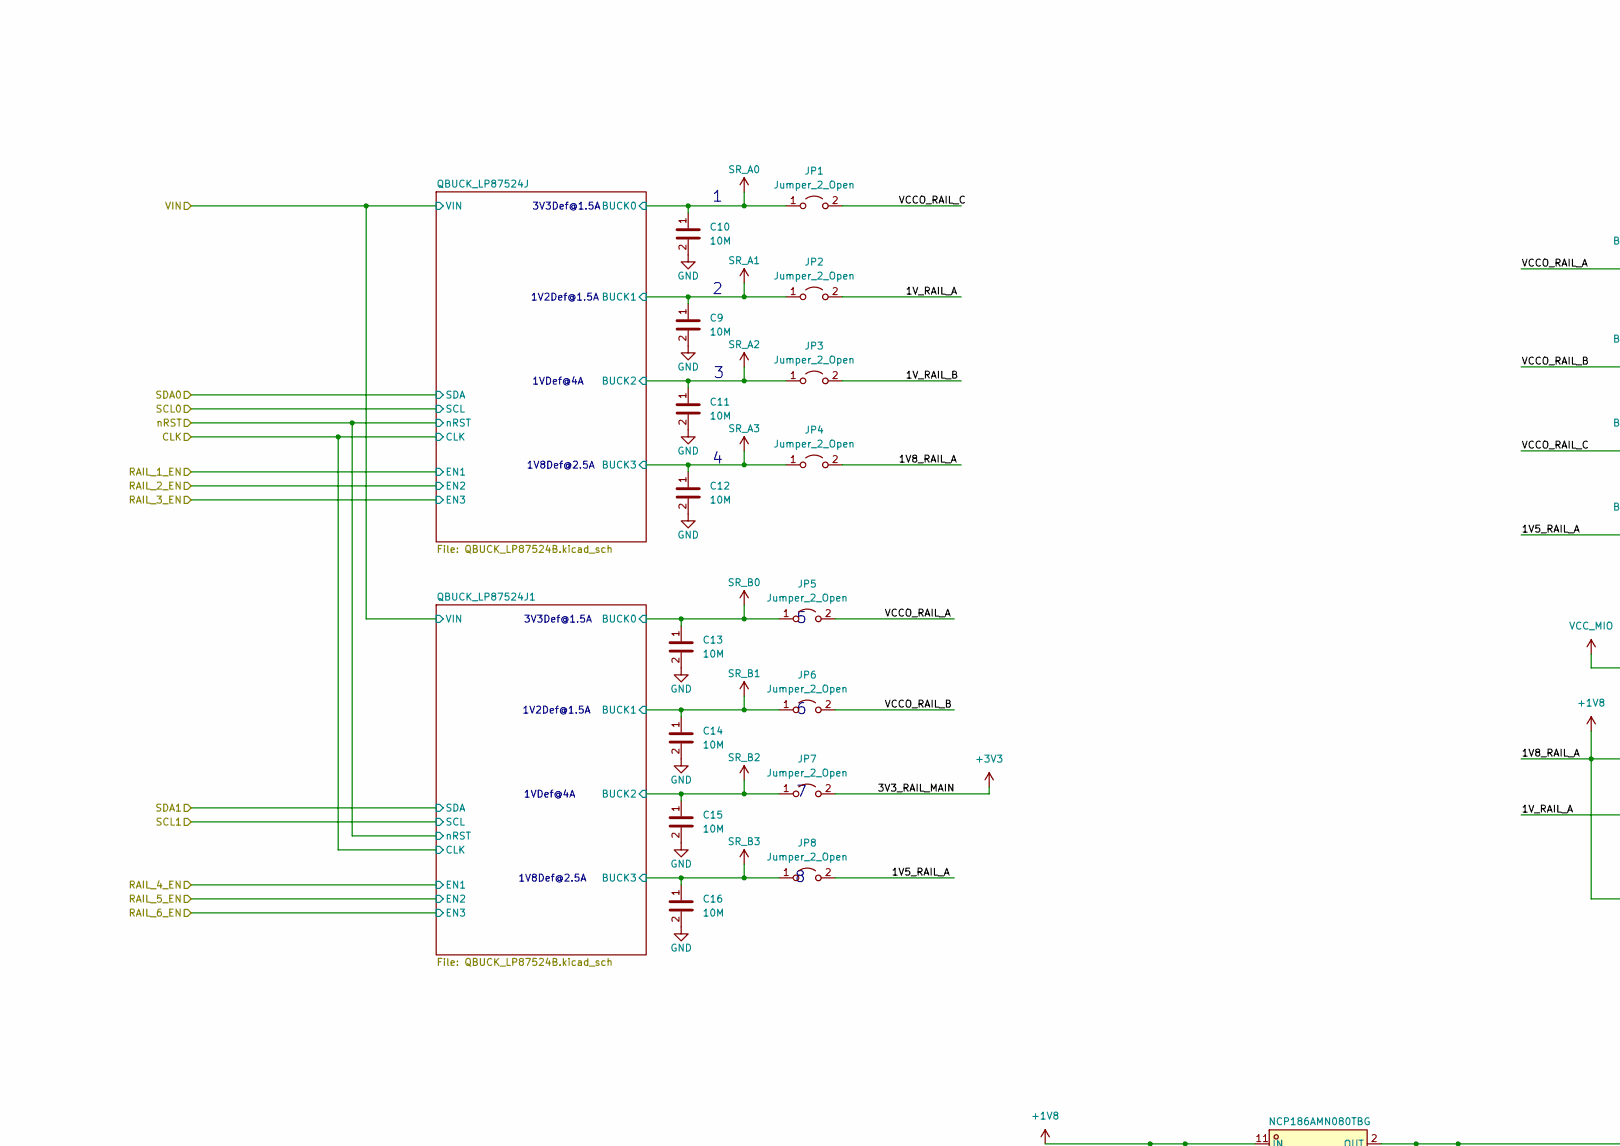
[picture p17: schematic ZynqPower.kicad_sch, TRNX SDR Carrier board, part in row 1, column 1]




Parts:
C9, C10, C11, C12, C13, C14, C15, C16, C148, C149, C150, C154, C245, C246, C247, C248: 10M; C_0603_1608Metric; Voltage 100V; JLCPCB Part # C96446
C25, C240, C244: 1M; C_0402_1005Metric; Voltage 100V; JLCPCB Part # C52923
C26, C28, C29, C30, C31, C32, C33, C34, C35, C36, C37, C38, C39, C40, C41, C42, C43, C44, C45, C46, C47, C48, C49, C50, C51, C52, C53, C54, C55, C56, C57, C58, C59, C60, C61, C62, C63, C64, C65, C66, C67, C68, C69, C70, C71, C72, C73, C74, C75, C76, C77, C78, C79, C80, C81, C82, C83, C84, C85, C86, C87, C184, C185: M1; C_0201_0603Metric; Voltage 100V; JLC C49062
C27, C147, C151, C152, C153: M1; C_0201_0603Metric; Voltage 100V; JLCPCB Part # C1581
FB6, FB11: GZ1005U102TF; L_0402_1005Metric_Pad0.77x0.64mm_HandSolder; JLCPCB Part # C19136
FB7, FB8, FB9, FB10, FB37, FB38: BLM18PG330SN1D; L_0603_1608Metric; JLCPCB Part # C88984
JP1, JP2, JP3, JP4, JP5, JP6, JP7, JP8: Jumper_2_Open; SolderJumper-2_P1.3mm_open_Pad1.0x1.5mm
R5, R7, R162: 5K1; R_0402_1005Metric; Tolerance =< 5%; JLCPCB Part # C25905
R6, R8, R69, R70, R71, R72: 10K; R_0402_1005Metric; Tolerance =< 5%; JLCPCB Part # C25744
R73: 33R; R_0402_1005Metric; Tolerance =< 5%; JLCPCB Part # C25105
U1: XC7Z015-2CLG485I; CLG485XC7Z012S&slash_XC7Z015_AMD; JLCPCB Part # C1522056
U5, U8: NCP186AMN080TBG; DFN-12_L4.0-W4.0-P0.65-BL-EP3.4; Manufacturer Part NCP186AMN080TBG; LCSC Part Name 低压差线性稳压器（LDO）——快速瞬态响应、低电压、1A
U15: TPS51200DRC; VSON-10-1EP_3x3mm_P0.5mm_EP1.65x2.4mm; JLCPCB Part # C34771
U24: SIP32409DNP-T1-GE4; UDFN-5_L1.6-W1.2-P0.50-BL-EP; Manufacturer Part SIP32409DNP-T1-GE4; LCSC Part Name SIP32409DNP-T1-GE4

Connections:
+1V2: C244.1, FB37.1, R5.1, U8.2 (OUT), U8.3 (OUT)
+1V8: C25.1, C26.1, C27.1, C57.1, C58.1, C59.1, C60.1, C247.1, C248.1, FB6.1, JP4.2 (B), R69.1, U1.A13 (VCCO_MIO1_501), U1.B10 (VCCO_MIO1_501), U1.B20 (VCCO_MIO0_500), U1.C17 (VCCO_MIO0_500), U1.D14 (VCCO_MIO1_501), U1.E11 (VCCO_MIO1_501), U1.K14 (VCCPAUX), U1.L13 (VCCPAUX), U1.M14 (VCCPAUX), U1.P14 (VCCPAUX), U1.R11 (VCCO_0), U5.10 (IN), U5.11 (IN), U8.10 (IN), U8.11 (IN), U24.1 (IN); also elsewhere on the board
+3V3: C153.1, C154.1, JP7.2 (B), U15.10 (VIN); also elsewhere on the board
/SMU/GPIO2: U15.7 (EN); also elsewhere on the board
/SMU/GPIO9: U8.9 (EN); also elsewhere on the board
/SMU/GPIO10: U5.9 (EN); also elsewhere on the board
/SMU/GPIO11: U24.3 (EN); also elsewhere on the board
/ZynqPower/1V5_RAIL_A: FB7.1, JP8.2 (B)
/ZynqPower/DDRVREF: U1.H16 (PS_DDR_VREF0_502), U1.P16 (PS_DDR_VREF1_502)
/ZynqPower/MGTAVCC: C45.1, C46.1, C47.1, C48.1, C49.1, C245.1, FB38.2, U1.U4 (MGTAVCC), U1.U6 (MGTAVCC), U1.U8 (MGTAVCC), U1.W5 (MGTAVCC), U1.W9 (MGTAVCC)
/ZynqPower/MGTAVTT: C40.1, C41.1, C42.1, C43.1, C44.1, C246.1, FB37.2, U1.AA2 (MGTAVTT), U1.AA4 (MGTAVTT), U1.AA8 (MGTAVTT), U1.AB1 (MGTAVTT), U1.AB6 (MGTAVTT), U1.Y7 (MGTAVTT)
/ZynqPower/PS_MIO_VREF_501: R69.2, R70.1, U1.F15 (PS_MIO_VREF_501)
/ZynqPower/VCCADC: C184.1, C185.1, FB11.2, U1.K12 (VCCADC_0)
/ZynqPower/VCCAUX: C36.1, C37.1, C38.1, C39.1, FB11.1, U1.N13 (VCCAUX), U1.P12 (VCCAUX), U1.R13 (VCCAUX), U1.T12 (VCCAUX), U24.4 (OUT)
/ZynqPower/VCCO_RAIL_A: FB9.1, JP5.2 (B)
/ZynqPower/VCCO_RAIL_B: FB8.1, JP6.2 (B)
/ZynqPower/VCCO_RAIL_C: FB10.1, JP1.2 (B)
/ZynqPower/VCCPLL: C50.1, FB6.2, U1.G13 (VCCPLL)
GND: C9.2, C10.2, C11.2, C12.2, C13.2, C14.2, C15.2, C16.2, C25.2, C26.2, C27.2, C28.2, C29.2, C30.2, C31.2, C32.2, C33.2, C34.2, C35.2, C36.2, C37.2, C38.2, C39.2, C40.2, C41.2, C42.2, C43.2, C44.2, C45.2, C46.2, C47.2, C48.2, C49.2, C50.2, C51.2, C52.2, C53.2, C54.2, C55.2, C56.2, C57.2, C58.2, C59.2, C60.2, C61.2, C62.2, C63.2, C64.2, C65.2, C66.2, C67.2, C68.2, C69.2, C70.2, C71.2, C72.2, C73.2, C74.2, C75.2, C76.2, C77.2, C78.2, C79.2, C80.2, C81.2, C82.2, C83.2, C84.2, C85.2, C86.2, C87.2, C147.2, C148.2, C149.2, C150.2, C151.2, C152.2, C153.2, C154.2, C184.2, C185.2, C240.2, C244.2, C245.2, C246.2, C247.2, C248.2, R6.2, R8.2, R70.2, R72.2, U1.A8 (GND), U1.A18 (GND), U1.AA1 (GND), U1.AA6 (GND), U1.AA10 (GND), U1.AA18 (GND), U1.AB2 (GND), U1.AB4 (GND), U1.AB8 (GND), U1.AB10 (GND), U1.AB15 (GND), U1.B5 (GND), U1.B15 (GND), U1.C2 (GND), U1.C12 (GND), U1.C22 (GND), U1.D9 (GND), U1.D19 (GND), U1.E6 (GND), U1.E16 (GND), U1.F3 (GND), U1.F13 (GND), U1.G10 (GND), U1.G12 (RSVDGND), U1.G20 (GND), U1.H7 (GND), U1.H13 (GND), U1.H15 (GND), U1.H17 (GND), U1.J4 (GND), U1.J10 (GND), U1.J12 (GND), U1.J14 (GND), U1.K1 (GND), U1.K9 (GND), U1.K11 (GNDADC_0), U1.K13 (GND), U1.K15 (GND), U1.K21 (GND), U1.L8 (GND), U1.L10 (GND), U1.L11 (VREFN_0), U1.L14 (GND), U1.L18 (GND), U1.M5 (GND), U1.M9 (GND), U1.M12 (VREFP_0), U1.M13 (GND), U1.M15 (GND), U1.N2 (GND), U1.N10 (GND), U1.N14 (GND), U1.N22 (GND), U1.P9 (GND), U1.P11 (GND), U1.P13 (GND), U1.P15 (GND), U1.P19 (GND), U1.R6 (GND), U1.R10 (GND), U1.R12 (GND), U1.R14 (GND), U1.R16 (GND), U1.T3 (GND), U1.T4 (GND), U1.T5 (GND), U1.T6 (GND), U1.T7 (GND), U1.T13 (GND), U1.U3 (GND), U1.U10 (GND), U1.U20 (GND), U1.V1 (GND), U1.V2 (GND), U1.V3 (GND), U1.V4 (GND), U1.V6 (GND), U1.V8 (GND), U1.V17 (GND), U1.W1 (GND), U1.W7 (GND), U1.W10 (GND), U1.W14 (GND), U1.Y1 (GND), U1.Y3 (GND), U1.Y5 (GND), U1.Y9 (GND), U1.Y10 (GND), U1.Y11 (GND), U1.Y21 (GND), U5.8 (GND), U5.13 (EP), U8.8 (GND), U8.13 (EP), U15.4 (GND), U15.8 (GND), U15.11 (GND), U24.2 (GND), U24.5 (EXP); also elsewhere on the board
unnamed: C240.1, FB38.1, R7.1, R162.1, U5.2 (OUT), U5.3 (OUT)
unnamed: R7.2, R8.1, R162.2, U5.5 (FB/ADJ)
unnamed: R5.2, R6.1, U8.5 (FB/ADJ)
unnamed: C151.1, R71.2, R72.1, U15.1 (REFIN)
unnamed: C152.1, R73.1, U15.5 (VOSNS)
SR_A0: C10.1, JP1.1 (A); also elsewhere on the board
SR_A1: C9.1, JP2.1 (A); also elsewhere on the board
SR_A2: C11.1, JP3.1 (A); also elsewhere on the board
SR_A3: C12.1, JP4.1 (A); also elsewhere on the board
SR_B0: C13.1, JP5.1 (A); also elsewhere on the board
SR_B1: C14.1, JP6.1 (A); also elsewhere on the board
SR_B2: C15.1, JP7.1 (A); also elsewhere on the board
SR_B3: C16.1, JP8.1 (A); also elsewhere on the board
VCCIO_13: C82.1, C83.1, C84.1, C85.1, C86.1, C87.1, FB9.2, U1.AA13 (VCCO_13), U1.AB20 (VCCO_13), U1.T18 (VCCO_13), U1.U15 (VCCO_13), U1.V12 (VCCO_13), U1.W19 (VCCO_13), U1.Y16 (VCCO_13); also elsewhere on the board
VCCIO_34: C76.1, C77.1, C78.1, C79.1, C80.1, C81.1, FB8.2, U1.H2 (VCCO_34), U1.K6 (VCCO_34), U1.L3 (VCCO_34), U1.N7 (VCCO_34), U1.P4 (VCCO_34), U1.R1 (VCCO_34); also elsewhere on the board
VCCIO_35: C70.1, C71.1, C72.1, C73.1, C74.1, C75.1, FB10.2, U1.A3 (VCCO_35), U1.C7 (VCCO_35), U1.D4 (VCCO_35), U1.E1 (VCCO_35), U1.F8 (VCCO_35), U1.G5 (VCCO_35); also elsewhere on the board
VDD_1V_RAIL_A: C51.1, C52.1, C53.1, C54.1, C55.1, C56.1, JP2.2 (B), U1.G15 (VCCPINT), U1.H14 (VCCPINT), U1.J15 (VCCPINT), U1.L15 (VCCPINT), U1.N15 (VCCPINT), U1.R15 (VCCPINT)
VDD_1V_RAIL_B: C28.1, C29.1, C30.1, C31.1, C32.1, C33.1, C34.1, C35.1, JP3.2 (B), U1.H12 (VCCBRAM), U1.J9 (VCCINT), U1.J11 (VCCINT), U1.J13 (VCCBRAM), U1.K10 (VCCINT), U1.L9 (VCCINT), U1.M10 (VCCINT), U1.N9 (VCCINT), U1.P10 (VCCINT), U1.R9 (VCCINT)
VDD_DDR: C61.1, C62.1, C63.1, C64.1, C65.1, C66.1, C67.1, C68.1, C69.1, FB7.2, R71.1, U1.E21 (VCCO_DDR_502), U1.F18 (VCCO_DDR_502), U1.H22 (VCCO_DDR_502), U1.J19 (VCCO_DDR_502), U1.K16 (VCCO_DDR_502), U1.M20 (VCCO_DDR_502), U1.N17 (VCCO_DDR_502), U1.R21 (VCCO_DDR_502), U1.V22 (VCCO_DDR_502), U15.2 (VLDOIN); also elsewhere on the board
VDD_VTT: C148.1, C149.1, C150.1, R73.2, U15.3 (VO); also elsewhere on the board
VREF_DDR: C147.1, U15.6 (REFOUT); also elsewhere on the board

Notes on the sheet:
1.8V@518mA
1.8-3.3V@50mA
1.8V@15mA
1V8Def@2.5A
1V@363mA
1V@52mA
1.2V@219mA
1V2Def@1.5A
1VDef@4A
1V@4A
1.8V@50mA
3V3Def@1.5A
1.8V@73mA
1.5V@460mA
1V@1.3A


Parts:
J11, J13, J15, J17: HYCW12-SMAW0863-1365B; sma-edge; JLCPCB Part # C5301850
J12, J14, J16, J18: U.FL-R-SMT-1(80); U.FL_Molex_MCRF_73412-0110_Vertical; JLCPCB Part # C88374

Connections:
GND: J11.2 (Ext), J12.2 (Ext), J13.2 (Ext), J14.2 (Ext), J15.2 (Ext), J16.2 (Ext), J17.2 (Ext), J18.2 (Ext); also elsewhere on the board
unnamed: J11.1 (In), J12.1 (In)
unnamed: J13.1 (In), J14.1 (In)
unnamed: J15.1 (In), J16.1 (In)
unnamed: J17.1 (In), J18.1 (In)

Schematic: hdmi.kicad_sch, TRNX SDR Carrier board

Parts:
J7: HDMI_D_1.4; HDMI_Micro-D_Molex_46765-1x01; JLCPCB Part # C563878
Q1, Q2, Q3: NTS4001NT1G; SOT-323_SC-70
R101, R102, R103, R104, R105, R106: 10K; R_0402_1005Metric; Tolerance =< 5%; JLCPCB Part # C25744

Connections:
+3V3: Q1.1 (G), Q2.1 (G), Q3.1 (G), R103.1, R104.1, R106.1; also elsewhere on the board
/HDMI/HDMI_HPD: Q3.2 (S), R106.2; also elsewhere on the board
/SYS_I2C_SCL: Q1.2 (S), R103.2; also elsewhere on the board
/SYS_I2C_SDA: Q2.2 (S), R104.2; also elsewhere on the board
/TMDS_CLK_N: J7.14 (CK-); also elsewhere on the board
/TMDS_CLK_P: J7.12 (CK+); also elsewhere on the board
/TMDS_D0_N: J7.11 (D0-); also elsewhere on the board
/TMDS_D0_P: J7.9 (D0+); also elsewhere on the board
/TMDS_D1_N: J7.8 (D1-); also elsewhere on the board
/TMDS_D1_P: J7.6 (D1+); also elsewhere on the board
/TMDS_D2_N: J7.5 (D2-); also elsewhere on the board
/TMDS_D2_P: J7.3 (D2+); also elsewhere on the board
GND: J7.4 (D2S), J7.7 (D1S), J7.10 (D0S), J7.13 (CKS), J7.16 (GND), J7.SH; also elsewhere on the board
unnamed: J7.1 (HPD/HEAC-), Q3.3 (D), R105.2
unnamed: J7.17 (SCL), Q1.3 (D), R101.2
unnamed: J7.18 (SDA), Q2.3 (D), R102.2
VDD_5V5A: J7.19 (+5V), R101.1, R102.1, R105.1; also elsewhere on the board

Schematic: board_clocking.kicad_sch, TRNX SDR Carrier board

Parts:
C164, C165, C169, C171: 10M; C_0603_1608Metric; Voltage 100V; JLCPCB Part # C96446
C166, C167, C168, C170, C172, C173, C308, C309, C315, C316, C317, C318, C319, C320, C321, C322, C382, C383: M1; C_0201_0603Metric; Voltage 100V; JLC C49062
FB12, FB13, FB14, FB15, FB41, FB42, FB43, FB44, FB45: GZ1005U102TF; L_0402_1005Metric_Pad0.77x0.64mm_HandSolder; JLCPCB Part # C19136
J19, J20: Conn_Coaxial; MMCX_Molex_73415-0961_Horizontal_1.6mm-PCB; JLCPCB Part # C5250057
R22, R23, R24, R25, R74, R75, R76, R77, R78, R79, R80, R81, R82, R83, R84, R85, R90, R141, R163: 33R; R_0402_1005Metric; Tolerance =< 5%; JLCPCB Part # C25105
R142, R164, R165, R166: 10K; R_0402_1005Metric; Tolerance =< 5%; JLCPCB Part # C25744
U13, U16: 5P35023B-000NLGI; VQFN-24-1EP_4x4mm_P0.5mm_EP2.5x2.5mm; Manufacturer Part 5P35023B-000NLGI; LCSC Part Name 5P35023B-000NLGI
U28: SN74LVC1G125DCKR; SOT-353_SC-70-5; JLCPCB Part # C7833

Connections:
+1V8: FB43.2; also elsewhere on the board
+3V3: FB42.2; also elsewhere on the board
/Clocking/CLK_PWR: FB13.1, FB14.1, R142.1
/Clocking/CLK_PWR_VBAT: R142.2, U13.6 (VBAT), U16.6 (VBAT)
/Clocking/CLK_REF_IN: R90.2; also elsewhere on the board
/Clocking/DIFF_A_CLK_1_N: R25.2
/Clocking/DIFF_A_CLK_1_P: R24.2
/Clocking/EXT_REF_EN: R166.2, U28.1; also elsewhere on the board
/Clocking/VDD_13F: C319.1, FB44.1, U13.20 (VDDSE3)
/Clocking/VDD_18F: C318.1, FB43.1, U16.13 (VDDSE1)
/Clocking/VDD_34F: C317.1, C320.1, FB41.1, U13.13 (VDDSE1), U16.20 (VDDSE3)
/Clocking/VDD_35F: C321.1, FB45.1, U13.11 (VDDSE2)
/Clocking/VDD_DIFF: C308.1, C309.1, C315.1, C316.1, C322.1, C383.2, FB42.1, R165.1, R166.1, U13.16 (VDDDIFF1), U13.22 (VDDDIFF2), U16.11 (VDDSE2), U16.16 (VDDDIFF1), U16.22 (VDDDIFF2), U28.5 (VCC)
/FPGA_CLK_REF_0: R77.2, R163.2, U13.5 (CLKINB/X1); also elsewhere on the board
/FPGA_CLK_REF_1_N: R78.2; also elsewhere on the board
/FPGA_CLK_REF_1_P: R79.2; also elsewhere on the board
/GTP_REF_CLK1_N: R22.2; also elsewhere on the board
/GTP_REF_CLK1_P: R23.2; also elsewhere on the board
/MOD_A1_REFCLK: R82.2; also elsewhere on the board
/MOD_A2_REFCLK: R84.2; also elsewhere on the board
/MOD_A3_REFCLK: R83.2; also elsewhere on the board
/MOD_A4_REFCLK: R74.2; also elsewhere on the board
/SMU/I2C1_SCL_A: U16.3 (SEL_DFC/SCL_DFC1); also elsewhere on the board
/SMU/I2C1_SCl_B: U13.2 (SDA_DFCO); also elsewhere on the board
/SMU/I2C1_SDA_A: U16.2 (SDA_DFCO); also elsewhere on the board
/SMU/I2C1_SDA_B: U13.3 (SEL_DFC/SCL_DFC1); also elsewhere on the board
/ULPI_REF_CLK_24M: R75.2; also elsewhere on the board
/USB_REF_CLK_N: R80.2; also elsewhere on the board
/USB_REF_CLK_P: R81.2; also elsewhere on the board
/ZYNQ_REF_CLK: R76.2; also elsewhere on the board
GND: C164.2, C165.2, C166.2, C167.2, C168.2, C169.2, C170.2, C171.2, C172.2, C173.2, C308.2, C309.2, C315.2, C316.2, C317.2, C318.2, C319.2, C320.2, C321.2, C322.2, C383.1, J19.2 (Ext), J20.2 (Ext), R164.2, U13.25 (EP), U16.25 (EP), U28.3 (GND); also elsewhere on the board
unnamed: C382.1, R141.2
unnamed: C382.2, R164.1, R165.2, U28.2
unnamed: J19.1 (In), R85.2
unnamed: J20.1 (In), R141.1
unnamed: R163.1, U28.4
unnamed: R80.1, U13.18 (DIFF1)
unnamed: R81.1, U13.17 (DIFF1B)
unnamed: R78.1, U13.24 (DIFF2)
unnamed: R79.1, U13.23 (DIFF2B)
unnamed: R85.1, U13.8 (REF)
unnamed: R84.1, U13.14 (SE1)
unnamed: R83.1, U13.12 (SE2)
unnamed: R82.1, U13.19 (SE3)
unnamed: C169.1, C170.1, FB14.2, FB15.1, U13.9 (VDD33)
unnamed: C171.1, C172.1, C173.1, FB15.2, U13.1 (VDDA)
unnamed: R90.1, U16.5 (CLKINB/X1)
unnamed: R24.1, U16.18 (DIFF1)
unnamed: R25.1, U16.17 (DIFF1B)
unnamed: R22.1, U16.24 (DIFF2)
unnamed: R23.1, U16.23 (DIFF2B)
unnamed: R77.1, U16.8 (REF)
unnamed: R76.1, U16.14 (SE1)
unnamed: R75.1, U16.12 (SE2)
unnamed: R74.1, U16.19 (SE3)
unnamed: C164.1, C166.1, FB12.1, FB13.2, U16.9 (VDD33)
unnamed: C165.1, C167.1, C168.1, FB12.2, U16.1 (VDDA)
VCCIO_13: FB44.2; also elsewhere on the board
VCCIO_34: FB41.2; also elsewhere on the board
VCCIO_35: FB45.2; also elsewhere on the board

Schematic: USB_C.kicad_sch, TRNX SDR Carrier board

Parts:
C226, C232, C263, C264, C265, C266, C267, C268, C269, C270, C275, C276, C277, C278: M1; C_0201_0603Metric; Voltage 100V; JLC C49062
C231: 10M; C_0603_1608Metric; Voltage 100V; JLCPCB Part # C96446
J9: 1054500101; MOLEX_1054500101; PARTREV A7; JLCPCB Part # C134092
R14, R17: 33R; R_0402_1005Metric; Tolerance =< 5%; JLCPCB Part # C25105
U9, U20: TS3USB221RSER; IC_TPD6E001RSER; JLCPCB Part # C130085
U25: FUSB302BMPX; WQFN-14-1EP_2.5x2.5mm_P0.5mm_EP1.45x1.45mm

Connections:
+3V3: C226.1, C231.1, C232.1, C275.2, C276.2, C277.2, C278.2, U9.10 (VCC), U20.10 (VCC), U25.3 (VDD), U25.4 (VDD); also elsewhere on the board
/GT_RX1_N: C269.1; also elsewhere on the board
/GT_RX1_P: C270.1; also elsewhere on the board
/GT_TX1_N: C268.1; also elsewhere on the board
/GT_TX1_P: C267.1; also elsewhere on the board
/SYS_I2C_SCL: U25.6 (SCL); also elsewhere on the board
/SYS_I2C_SDA: U25.7 (SDA); also elsewhere on the board
/USB_C/USBC_DM: J9.A7 (D1-), J9.B6 (D2+), R17.1
/USB_C/USBC_DP: J9.A6 (D1+), J9.B7 (D2-), R14.1
/USB_C/USB_CC1: J9.A5 (CC1), U25.10 (CC1), U25.11 (CC1)
/USB_C/USB_CC2: J9.B5 (CC2), U25.1 (CC2), U25.14 (CC2)
/USB_C/USB_IM_N: U9.7 (D_), U20.4 (2D-)
/USB_C/USB_IM_P: U9.8 (D+), U20.3 (2D+)
/USB_C/USB_RX1_N: C266.2, J9.B10 (RX1-)
/USB_C/USB_RX1_P: C264.2, J9.B11 (RX1+)
/USB_C/USB_RX2_N: C270.2, J9.A10 (RX2-)
/USB_C/USB_RX2_P: C269.2, J9.A11 (RX2+)
/USB_C/USB_TX1_N: C265.2, J9.A3 (TX1-)
/USB_C/USB_TX1_P: C263.2, J9.A2 (TX1+)
/USB_C/USB_TX2_N: C268.2, J9.B3 (TX2-)
/USB_C/USB_TX2_P: C267.2, J9.B2 (TX2+)
/USB_C/VCONN: U25.12 (VCONN), U25.13 (VCONN)
/USB_N: U20.1 (1D+); also elsewhere on the board
/USB_P: U20.2 (1D-); also elsewhere on the board
/USB_REF_CLK_N: U9.4 (2D-); also elsewhere on the board
/USB_REF_CLK_P: U9.3 (2D+); also elsewhere on the board
/USB_RX2_N: C266.1; also elsewhere on the board
/USB_RX2_P: C264.1; also elsewhere on the board
/USB_SPEC_N: U9.1 (1D+); also elsewhere on the board
/USB_SPEC_P: U9.2 (1D-); also elsewhere on the board
/USB_SW_S1: U20.9 (S); also elsewhere on the board
/USB_SW_S2: U9.9 (S); also elsewhere on the board
/USB_SW_S2_OE: U9.6 (OE); also elsewhere on the board
/USB_TX2_N: C265.1; also elsewhere on the board
/USB_TX2_P: C263.1; also elsewhere on the board
/USB_VUSB: J9.A4 (VBUS_A4), J9.A9 (VBUS_A9), J9.B4 (VBUS_B4), J9.B9 (VBUS_B9), U25.2 (VBUS); also elsewhere on the board
GND: C226.2, C231.2, C232.2, C275.1, C276.1, C277.1, C278.1, J9.A1 (GND_A1), J9.A12 (GND_A12), J9.B1 (GND_B1), J9.B12 (GND_B12), J9.SH1 (SHIELD3), J9.SH2 (SHIELD4), J9.SH3 (SHIELD1), J9.SH4 (SHIELD2), U9.5 (GND), U20.5 (GND), U20.6 (OE), U25.8 (GND), U25.9 (GND), U25.15 (GND); also elsewhere on the board
unnamed: R17.2, U20.8 (D+)
unnamed: R14.2, U20.7 (D_)

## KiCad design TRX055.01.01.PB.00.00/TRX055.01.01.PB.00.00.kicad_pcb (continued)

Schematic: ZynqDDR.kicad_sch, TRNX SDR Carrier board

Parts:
C327, C328, C329, C330, C331, C332, C333, C334, C335, C336, C337, C338, C339, C340, C341, C342, C343, C344, C345, C346, C347, C348, C349, C350, C351, C352, C353, C354, C355, C356, C357, C358, C359, C360, C361, C362, C363, C364, C365, C366, C367, C368: M1; C_0201_0603Metric; Voltage 100V; JLCPCB Part # C1581
C378, C379, C380, C381: 100M; C_1206_3216Metric; Voltage 100V; JLCPCB Part # C15008
R9, R10, R11, R13, R15, R16, R30, R31, R32, R33, R34, R35, R36, R37, R38, R39, R40, R41, R42, R43, R44, R45, R46, R47: 39R; R_0402_1005Metric; Tolerance =< 5%; JLCPCB Part # C25110
R48, R52, R53: 80R; R_0402_1005Metric; Tolerance =< 5%; JLCPCB Part # C854436
R49: 10K; R_0402_1005Metric; Tolerance =< 5%; JLCPCB Part # C25744
R50, R51: 240R; R_0402_1005Metric; Tolerance =< 5%; JLCPCB Part # C25153
U1: XC7Z015-2CLG485I; CLG485XC7Z012S&slash_XC7Z015_AMD; JLCPCB Part # C1522056
U2, U3: K4B4G1646E-BYMA; BGA-96_9.0x13.0mm_Layout2x3x16_P0.8mm; JLCPCB Part # C500275

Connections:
/ZynqDDR/DDR_A0: R41.1, U1.M19 (PS_DDR_A0_502), U2.N3 (A0), U3.N3 (A0)
/ZynqDDR/DDR_A1: R35.1, U1.M18 (PS_DDR_A1_502), U2.P7 (A1), U3.P7 (A1)
/ZynqDDR/DDR_A2: R11.1, U1.K19 (PS_DDR_A2_502), U2.P3 (A2), U3.P3 (A2)
/ZynqDDR/DDR_A3: R40.1, U1.L19 (PS_DDR_A3_502), U2.N2 (A3), U3.N2 (A3)
/ZynqDDR/DDR_A4: R36.1, U1.K17 (PS_DDR_A4_502), U2.P8 (A4), U3.P8 (A4)
/ZynqDDR/DDR_A5: R33.1, U1.K18 (PS_DDR_A5_502), U2.P2 (A5), U3.P2 (A5)
/ZynqDDR/DDR_A6: R30.1, U1.J16 (PS_DDR_A6_502), U2.R8 (A6), U3.R8 (A6)
/ZynqDDR/DDR_A7: R38.1, U1.J17 (PS_DDR_A7_502), U2.R2 (A7), U3.R2 (A7)
/ZynqDDR/DDR_A8: R16.1, U1.J18 (PS_DDR_A8_502), U2.T8 (A8), U3.T8 (A8)
/ZynqDDR/DDR_A9: R37.1, U1.H18 (PS_DDR_A9_502), U2.R3 (A9), U3.R3 (A9)
/ZynqDDR/DDR_A10: R10.1, U1.J20 (PS_DDR_A10_502), U2.L7 (A10/AP), U3.L7 (A10/AP)
/ZynqDDR/DDR_A11: R31.1, U1.G18 (PS_DDR_A11_502), U2.R7 (A11), U3.R7 (A11)
/ZynqDDR/DDR_A12: R13.1, U1.H19 (PS_DDR_A12_502), U2.N7 (A12/~BC), U3.N7 (A12/~BC)
/ZynqDDR/DDR_A13: R32.1, U1.F19 (PS_DDR_A13_502), U2.T3 (A13), U3.T3 (A13)
/ZynqDDR/DDR_A14: R34.1, U1.G19 (PS_DDR_A14_502), U2.T7 (A14), U3.T7 (A14)
/ZynqDDR/DDR_BA0: R39.1, U1.L16 (PS_DDR_BA0_502), U2.M2 (BA0), U3.M2 (BA0)
/ZynqDDR/DDR_BA1: R15.1, U1.L17 (PS_DDR_BA1_502), U2.N8 (BA1), U3.N8 (BA1)
/ZynqDDR/DDR_BA2: R47.1, U1.M17 (PS_DDR_BA2_502), U2.M3 (BA2), U3.M3 (BA2)
/ZynqDDR/DDR_CAS: R9.1, U1.P20 (PS_DDR_CAS_B_502), U2.K3 (~CAS), U3.K3 (~CAS)
/ZynqDDR/DDR_CK_E: R42.1, U1.T19 (PS_DDR_CKE_502), U2.K9 (CKE), U3.K9 (CKE)
/ZynqDDR/DDR_CK_N: R48.1, U1.N18 (PS_DDR_CKN_502), U2.K7 (~CK), U3.K7 (~CK)
/ZynqDDR/DDR_CK_P: R48.2, U1.N19 (PS_DDR_CKP_502), U2.J7 (CK), U3.J7 (CK)
/ZynqDDR/DDR_CS: R44.1, U1.P17 (PS_DDR_CS_B_502), U2.L2 (~CS), U3.L2 (~CS)
/ZynqDDR/DDR_DM0: U1.B22 (PS_DDR_DM0_502), U3.D3 (UDM)
/ZynqDDR/DDR_DM1: U1.H20 (PS_DDR_DM1_502), U3.E7 (LDM)
/ZynqDDR/DDR_DM2: U1.P22 (PS_DDR_DM2_502), U2.E7 (LDM)
/ZynqDDR/DDR_DM3: U1.AA21 (PS_DDR_DM3_502), U2.D3 (UDM)
/ZynqDDR/DDR_DQ0: U1.D22 (PS_DDR_DQ0_502), U3.D7 (DQ8)
/ZynqDDR/DDR_DQ1: U1.C20 (PS_DDR_DQ1_502), U3.C8 (DQ10)
/ZynqDDR/DDR_DQ2: U1.B21 (PS_DDR_DQ2_502), U3.A7 (DQ12)
/ZynqDDR/DDR_DQ3: U1.D20 (PS_DDR_DQ3_502), U3.B8 (DQ14)
/ZynqDDR/DDR_DQ4: U1.E20 (PS_DDR_DQ4_502), U3.C3 (DQ9)
/ZynqDDR/DDR_DQ5: U1.E22 (PS_DDR_DQ5_502), U3.C2 (DQ11)
/ZynqDDR/DDR_DQ6: U1.F21 (PS_DDR_DQ6_502), U3.A3 (DQ15)
/ZynqDDR/DDR_DQ7: U1.F22 (PS_DDR_DQ7_502), U3.A2 (DQ13)
/ZynqDDR/DDR_DQ8: U1.G21 (PS_DDR_DQ8_502), U3.F7 (DQ1)
/ZynqDDR/DDR_DQ9: U1.G22 (PS_DDR_DQ9_502), U3.F8 (DQ3)
/ZynqDDR/DDR_DQ10: U1.L22 (PS_DDR_DQ10_502), U3.G2 (DQ6)
/ZynqDDR/DDR_DQ11: U1.L21 (PS_DDR_DQ11_502), U3.F2 (DQ2)
/ZynqDDR/DDR_DQ12: U1.L20 (PS_DDR_DQ12_502), U3.H3 (DQ4)
/ZynqDDR/DDR_DQ13: U1.K22 (PS_DDR_DQ13_502), U3.E3 (DQ0)
/ZynqDDR/DDR_DQ14: U1.J22 (PS_DDR_DQ14_502), U3.H8 (DQ5)
/ZynqDDR/DDR_DQ15: U1.K20 (PS_DDR_DQ15_502), U3.H7 (DQ7)
/ZynqDDR/DDR_DQ16: U1.M22 (PS_DDR_DQ16_502), U2.H7 (DQ7)
/ZynqDDR/DDR_DQ17: U1.T20 (PS_DDR_DQ17_502), U2.F2 (DQ2)
/ZynqDDR/DDR_DQ18: U1.N20 (PS_DDR_DQ18_502), U2.F7 (DQ1)
/ZynqDDR/DDR_DQ19: U1.T22 (PS_DDR_DQ19_502), U2.G2 (DQ6)
/ZynqDDR/DDR_DQ20: U1.R20 (PS_DDR_DQ20_502), U2.H3 (DQ4)
/ZynqDDR/DDR_DQ21: U1.T21 (PS_DDR_DQ21_502), U2.E3 (DQ0)
/ZynqDDR/DDR_DQ22: U1.M21 (PS_DDR_DQ22_502), U2.H8 (DQ5)
/ZynqDDR/DDR_DQ23: U1.R22 (PS_DDR_DQ23_502), U2.F8 (DQ3)
/ZynqDDR/DDR_DQ24: U1.Y20 (PS_DDR_DQ24_502), U2.A2 (DQ13)
/ZynqDDR/DDR_DQ25: U1.U22 (PS_DDR_DQ25_502), U2.B8 (DQ14)
/ZynqDDR/DDR_DQ26: U1.AA22 (PS_DDR_DQ26_502), U2.A3 (DQ15)
/ZynqDDR/DDR_DQ27: U1.U21 (PS_DDR_DQ27_502), U2.D7 (DQ8)
/ZynqDDR/DDR_DQ28: U1.W22 (PS_DDR_DQ28_502), U2.C2 (DQ11)
/ZynqDDR/DDR_DQ29: U1.W20 (PS_DDR_DQ29_502), U2.A7 (DQ12)
/ZynqDDR/DDR_DQ30: U1.V20 (PS_DDR_DQ30_502), U2.C8 (DQ10)
/ZynqDDR/DDR_DQ31: U1.Y22 (PS_DDR_DQ31_502), U2.C3 (DQ9)
/ZynqDDR/DDR_DQS0_N: U1.D21 (PS_DDR_DQS_N0_502), U3.B7 (~UDQS)
/ZynqDDR/DDR_DQS0_P: U1.C21 (PS_DDR_DQS_P0_502), U3.C7 (UDQS)
/ZynqDDR/DDR_DQS1_N: U1.J21 (PS_DDR_DQS_N1_502), U3.G3 (~LDQS)
/ZynqDDR/DDR_DQS1_P: U1.H21 (PS_DDR_DQS_P1_502), U3.F3 (LDQS)
/ZynqDDR/DDR_DQS2_N: U1.P21 (PS_DDR_DQS_N2_502), U2.G3 (~LDQS)
/ZynqDDR/DDR_DQS2_P: U1.N21 (PS_DDR_DQS_P2_502), U2.F3 (LDQS)
/ZynqDDR/DDR_DQS3_N: U1.W21 (PS_DDR_DQS_N3_502), U2.B7 (~UDQS)
/ZynqDDR/DDR_DQS3_P: U1.V21 (PS_DDR_DQS_P3_502), U2.C7 (UDQS)
/ZynqDDR/DDR_ODT: R46.1, U1.P18 (PS_DDR_ODT_502), U2.K1 (ODT), U3.K1 (ODT)
/ZynqDDR/DDR_RAS: R43.1, U1.R18 (PS_DDR_RAS_B_502), U2.J3 (~RAS), U3.J3 (~RAS)
/ZynqDDR/DDR_RST: R49.1, U1.F20 (PS_DDR_DRST_B_502), U2.T2 (~RESET), U3.T2 (~RESET)
/ZynqDDR/DDR_WE: R45.1, U1.R19 (PS_DDR_WE_B_502), U2.L3 (~WE), U3.L3 (~WE)
GND: C327.2, C328.2, C329.2, C330.2, C331.2, C332.2, C333.2, C334.2, C335.2, C336.2, C337.2, C338.2, C339.2, C340.2, C341.2, C342.2, C343.2, C344.2, C345.2, C346.2, C347.2, C348.2, C349.2, C350.2, C351.2, C352.2, C353.2, C354.2, C355.2, C356.2, C357.2, C358.2, C359.2, C360.2, C361.2, C362.2, C363.2, C364.2, C365.2, C366.2, C367.2, C368.2, C378.2, C379.2, C380.2, C381.2, R49.2, R50.1, R51.1, R52.1, U2.A9 (VSS), U2.B1 (VSSQ), U2.B3 (VSS), U2.B9 (VSSQ), U2.D1 (VSSQ), U2.D8 (VSSQ), U2.E1 (VSS), U2.E2 (VSSQ), U2.E8 (VSSQ), U2.F9 (VSSQ), U2.G1 (VSSQ), U2.G8 (VSS), U2.G9 (VSSQ), U2.J2 (VSS), U2.J8 (VSS), U2.M1 (VSS), U2.M9 (VSS), U2.P1 (VSS), U2.P9 (VSS), U2.T1 (VSS), U2.T9 (VSS), U3.A9 (VSS), U3.B1 (VSSQ), U3.B3 (VSS), U3.B9 (VSSQ), U3.D1 (VSSQ), U3.D8 (VSSQ), U3.E1 (VSS), U3.E2 (VSSQ), U3.E8 (VSSQ), U3.F9 (VSSQ), U3.G1 (VSSQ), U3.G8 (VSS), U3.G9 (VSSQ), U3.J2 (VSS), U3.J8 (VSS), U3.M1 (VSS), U3.M9 (VSS), U3.P1 (VSS), U3.P9 (VSS), U3.T1 (VSS), U3.T9 (VSS); also elsewhere on the board
unnamed: R53.1, U1.M16 (PS_DDR_VRN_502)
unnamed: R52.2, U1.N16 (PS_DDR_VRP_502)
unnamed: R50.2, U2.L8 (ZQ)
unnamed: R51.2, U3.L8 (ZQ)
VDD_DDR: C331.1, C332.1, C333.1, C334.1, C335.1, C336.1, C337.1, C338.1, C339.1, C340.1, C341.1, C342.1, C343.1, C344.1, C345.1, C346.1, C347.1, C348.1, C349.1, C350.1, C351.1, C352.1, C353.1, C354.1, C355.1, C356.1, C357.1, C358.1, C359.1, C360.1, C361.1, C362.1, C363.1, C364.1, C365.1, C366.1, C367.1, C368.1, C378.1, C379.1, C380.1, C381.1, R53.2, U2.A1 (VDDQ), U2.A8 (VDDQ), U2.B2 (VDD), U2.C1 (VDDQ), U2.C9 (VDDQ), U2.D2 (VDDQ), U2.D9 (VDD), U2.E9 (VDDQ), U2.F1 (VDDQ), U2.G7 (VDD), U2.H2 (VDDQ), U2.H9 (VDDQ), U2.K2 (VDD), U2.K8 (VDD), U2.N1 (VDD), U2.N9 (VDD), U2.R1 (VDD), U2.R9 (VDD), U3.A1 (VDDQ), U3.A8 (VDDQ), U3.B2 (VDD), U3.C1 (VDDQ), U3.C9 (VDDQ), U3.D2 (VDDQ), U3.D9 (VDD), U3.E9 (VDDQ), U3.F1 (VDDQ), U3.G7 (VDD), U3.H2 (VDDQ), U3.H9 (VDDQ), U3.K2 (VDD), U3.K8 (VDD), U3.N1 (VDD), U3.N9 (VDD), U3.R1 (VDD), U3.R9 (VDD); also elsewhere on the board
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

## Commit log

2025-09-04 Inital commit
    [Module_Interface.kicad_sch, PS_DDR_Calcolations.ods, QBUCK_LP87524B.kicad_sch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]
2025-09-11 Update Layout
    [ETH_PHY_Metal.kicad_sch, Module_Interface.kicad_sch, QBUCK_LP87524B.kicad_sch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]
2025-09-29 +ETH +USB +Connectors
    [ETH_PHY_Metal.kicad_sch, EthPair.kicad_sch, Module_Interface.kicad_sch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]
2025-10-16 + add clocks + add PSU
    [ETH_PHY_Metal.kicad_sch, EthPair.kicad_sch, Main_Power.kicad_sch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]
2026-01-23 Producing - rev0.0
    [ETH_PHY_Metal.kicad_sch, EthPair.kicad_sch, ExtInt.kicad_sch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]
2026-02-10 V0.1 - production, added brig-up comments
    [ETH_PHY_Metal.kicad_sch, EthPair.kicad_sch, ExtInt.kicad_sch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]
2026-03-05 Licence update
    [TRX055.01.01.PB.00.00.kicad_pcb]
